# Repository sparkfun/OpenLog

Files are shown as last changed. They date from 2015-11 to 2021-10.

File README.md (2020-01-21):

SparkFun OpenLog
================

<table class="table table-hover table-striped table-bordered">
  <tr align="center">
   <td><a href="https://www.sparkfun.com/products/13712">SparkFun OpenLog</a></td>
   <td><a href="https://www.sparkfun.com/products/13955">SparkFun OpenLog with Headers</a></td>
  </tr>
  <tr align="center">
    <td><i>SparkFun OpenLog (<a href="https://www.sparkfun.com/products/13712">DEV-13712</a>)</i></td>
    <td><i>SparkFun OpenLog with Headers (<a href="https://www.sparkfun.com/products/13955">DEV-13955</a>)</i></td>
  </tr>
</table>

OpenLog is an open source data logger that works over a simple serial connection and supports microSD cards up to 64GB. 

Repository Contents
-------------------
* **/Documentation** - Data sheets, additional product information
* **/Firmware** - Example sketches for the OpenLog, and for an Arduino connected to the OpenLog.
* **/Hardware** - Hardware design files for the OpenLog PCB. These files were designed in Eagle CAD.
* **/Libraries** - Libraries for use with the OpenLog.
* **/Production** - Production panel files (.brd)

Documentation
--------------
* **[Hookup Guide](https://learn.sparkfun.com/tutorials/openlog-hookup-guide)** - Basic hookup guide for the OpenLog.
* **[SparkFun Fritzing repo](https://github.com/sparkfun/Fritzing_Parts)** - Fritzing diagrams for SparkFun products.
* **[SparkFun 3D Model repo](https://github.com/sparkfun/3D_Models)** - 3D models of SparkFun products. 
* **[SparkFun Graphical Datasheets](https://github.com/sparkfun/Graphical_Datasheets)** -Graphical Datasheets for various SparkFun products.

License Information
-------------------

This product is _**open source**_! 

Please review the LICENSE.md file for license information. 

If you have any questions or concerns on licensing, please contact techsupport@sparkfun.com.

Distributed as-is; no warranty is given.

- Your friends at SparkFun.

_SDFatLib-beta and SerialPort are written by Bill Greiman, and released under GPLv3._

Version History
---------------

For a full view of changes please see the [changelog](https://github.com/sparkfun/OpenLog/blob/master/CHANGELOG.md). 

OpenLog v4 is refactored with better RAM utilization for better performance at higher record speeds (115200/57600).

OpenLog v3 is stable, supports FAT32 cards up to 64GB and supports higher record speeds (115200/57600).

OpenLog v2 is a bit buggy but supports FAT32 and SD cards up to 16GB.  

OpenLog v1 is stable but only supports FAT16 and up to 2GB.  

* **v1.0**  Buggy initial release
* **v1.1**  Small changes to system settings and EEPROM storage.
* **v1.2**  Added wild card to listing and remove commands. Added read file command.
* **v1.3**  Added auto buffer record if unit sits idle for more than 5 seconds.
* **v1.4**  Increase buffer size to 900 bytes. Pinning down URU errors.
* **v1.5**  Lowered power consumption to ~2mA avg. Added 4800 and 19200 baud rates.
* **v1.51** Added configurable escape character, and escape character amount.
* **v1.6**  Added ability to configure via config.txt file.
* **v2.0**  Massive overhaul. Ported to sdfatlib. Now supports FAT16/FAT32/SD/SDHC.
* **v2.1**  Power save not working. Fixed issue 35. Dropping characters at 57600bps.
* **v2.11** Tested with 16GB microSD. Fixed issues 30 & 34. Re-enable power save.
* **v2.2**  Modified append_file() to use a single buffer. Increased HardwareSerial.cpp buffer to 512 bytes.
* **v2.21** ringp fork brought in. rm dir, cd .., and wildcards now work!
* **v2.3**  Migrated to v10.10.10 of sdfatlib. Moved to inline RX interrupt and buffer.
* **v2.4**  Merged ringp updates. Commands cd, rm, ls work again!
* **v2.41** Power loss bug fixed. Adding support for 38400bps for testing with SparkFum 9DOF IMU logging. 
* **v2.5**  Added software reset command. Modified the read command to print extended ASCII characters.
* **v2.51** Changed command prompt control to ignore \n for easier control from microcontroller.
* **v3.0**  Migration to Arduino v1.0 and better recording speed at 115200bps and 57600bps.
* **v3.1**  Better handling of recording during power loss.
* **v3.2**  Freed up RAM for larger RX ring buffer. Added support for wildcards and ability to ignore emergency override.
* **v3.3**  Added ability to ignore escape character checking and corrected incremental log naming.
* **v4.0**  Re-worked to be compatible with Arduino v1.6.x. Freed RAM to increase RX buffer size.

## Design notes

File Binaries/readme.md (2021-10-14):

Programming OpenLog via Serial
===========================================================

The SparkFun OpenLog can be updated using a USB to serial adapter and 5 jumper wires. Run batch_program.bat with a given COM port and HEX file.

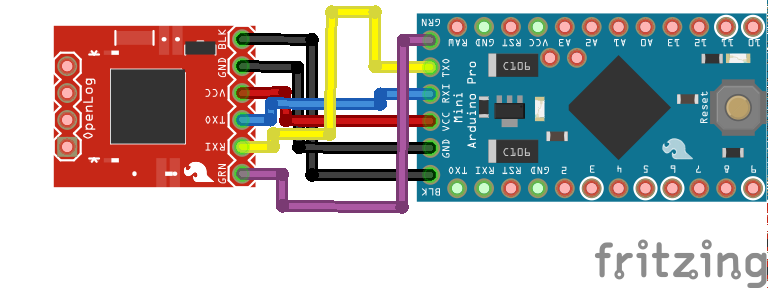
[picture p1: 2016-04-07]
Documentation/OpenLogProMini.png

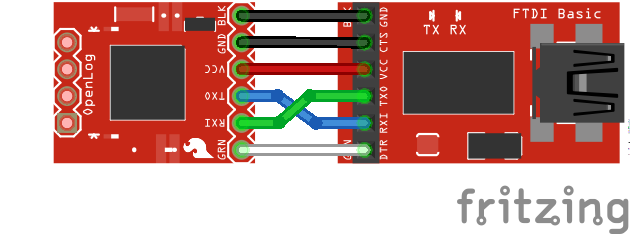
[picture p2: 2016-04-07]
Documentation/OpenLogFTDI.png

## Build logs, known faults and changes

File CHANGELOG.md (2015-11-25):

#Change Log
All notable changes to this project will be documented in this file. We'll also give shout outs to folks who help fix bugs and generally make OpenLog a better experience.
 
## [4.0] - November 23 2015 

27,046 bytes compiled

Welcome to version 4! Now compiles under Arduino v1.6.x! Thanks @owenduffy for getting OpenLog ported to the new SdFatLib.

Worked on issue #168. Fixed issue #178. Thanks @jremington! Now works with Bill's latest [SD lib](https://github.com/greiman/SdFat-beta).

[Added] Escape character sequences are now removed from logs. If you hit ctrl+z three times you'll drop to the command shell and the three escape characters will not be recorded to the log.

[Removed] The pwd command has been removed from the command shell. This *shouldn't* effect anyone but you should know.

[Removed] The sync command has been removed from the command shell. This *shouldn't* effect anyone but you should know.

Fixed a bad bug found by @ystark. Thank you! New file name array is now correctly defined as static.

Fixed the LEDs so they now blink correctly when doing an emergency reset.

In order to get the maximum out of SerialPort lib you'll need to edit SerialPort.h: 

* Set BUFFERED_TX to 0
* Set ENABLE_RX_ERROR_CHECKING to 0

## [3.3] August 2014

28,350 bytes compiled

Using the latest SdFat lib from Bill: https://code.google.com/p/sdfatlib/downloads/list
Using Arduino v1.5.4

Fixed issue #160: https://github.com/sparkfun/OpenLog/issues/160
Logs now increment continously regardless of what file may be on the card. Adds 6 bytes.

Added feature/issue #166: If escape characters is set to zero, it ignores all escape characters. Adds 200 bytes.

Fixed issue 164 - Reducing RX buffer size to allow for correct baud rate changes.
SerialPort<0, 780, 0> NewSerial; //Fails
SerialPort<0, 750, 0> NewSerial; //Works

Fixed issue #163 - using dlkeng's fix to get baud rate to work at 300 baud. Adds 80 bytes.

Increased escape character limits to 0 and 254. If set to zero, it will not check for escape characters.

## [3.2] April 8 2013

28,640 bytes compiled (yay! saved a bunch by removing the text-based menu system)

Re-wrote baud rate system to support anything from 300bps to 1,000,000bps

Added support for newlines when using the 'write' command.
Should fix issue #149.

Fixed issue #134: When removing files and there is a directory, all wildcard files are now removed correctly.
Fixed issue #135: ls with wildcard works again. Thank you @dlkeng!

## [3.14]

29,354 bytes compiled

Added support for 1200bps. Issue #139.

## [3.13]

29,172 bytes compiled

Changed the string compares from strings in RAM (strcmp) to strings located in flash memory (strcmp_P).

We used to use this type of compare: else if(strcmp_P(command_arg, PSTR("md")) == 0)

I'm not sure how or why I got away from it, but bringing it back frees up a lot of RAM. I bet I got rid of PSTRs in an attempt to reduce code size when I should have been more worried about RAM running out. RAM is currently at 645 after 2 and 562 once we've begun append_file. Also figured out there is sprintf_P built just for PSTRs. Neat! RAM is currently at 779 after 2 and 696 once we've begun append_file. Removal of strncmp(). I believe we used it to reduce flash footprint. Once migrated to PSTR, it makes it worse.

## [3.12]

29,282 bytes compiled

Using freeMemory() function from JeeLabs. Seems to be working well.

Echo on/off is working again with a reduction of the buffer from 600 to 500. Code size is up a bit to 29,282. We have free RAM of about 527 after "2" and 444 once we've begun append_file.

## [3.11] March 26 2012

Added freeMemory support for RAM testing.

This was taken from: http://arduino.cc/playground/Code/AvailableMemory

## [3.1] March 23 2012

Fixed bug where entire log data is lost when power is lost.

Added fix from issue #76. Added support for verbose and echo settings recorded to the config file and EEPROM. Bugs #101 and #102 fixed with the help of @pwjansen and @wilafau - thank you!!

Because of the new code to the cycle sensitive append_log loop, 115200bps is not as rock solid as I'd like. I plan to correct this in the Light version.

Added a maxLoop variable calculation to figure out how many bytes to receive before we do a forced file.sync.

## [3.0] March 14 2012

28,354 bytes compiled

Re-write of core functions. Support under Arduino v1.0. Now supports full speed 57600 and 115200bps! Lower standby power.

Be sure to check out https://github.com/nseidle/OpenLog/issues for issues that have been resolved up to this version.

Update to new beta version of SerialPort lib from Bill Greiman. Update to Arduino v1.0. With Bill's library, we don't need to hack the HardwareSerial.cpp.

Re-wrote the append function. This function is the most important function and has the most affect on record accuracy. We are now able to record at 57600 and 115200bps at full blast! The performance is vastly improved.

To compile v3.0 you will need Arduino v1.0 and Bill's beta library: http://beta-lib.googlecode.com/files/SerialLoggerBeta20120108.zip Unzip 'SerialPortBeta20120106.zip' and 'SdFatBeta20120108.zip' to the libraries directory and close and restart Arduino.

Small stuff:

* Redirected all static strings to point to the new way in Arduino 1.0: Serial.print(F("asdf")); instead of PgmPrint
* Figured out lower standby power from the low-power tutorial: http://www.sparkfun.com/tutorials/309
* Corrected #define TRUE to built-in supported 'true'
* Re-arranged some functions
* Migrating to Uno bootloader to get an additional 1500 bytes of program space
* Replumbed everything to get away from hardware UART
* Reduced # of sub directory support from 15 levels to 2 to allow for more RAM
* Wildcard remove is supported in v3.1
* Wildcard is supported in v3.2
* [Remove] efcount and efinfo is not yet supported in v3.0

Testing at 115200. First test with clean/empty card. The second test is with 193MB across 172 files on the microSD card.

* 1GB: 333075/333075, 333075/333075
* 8GB: 333075/333075, 333075/333075
* 16GB: 333075/333075, 333075/333075

The card with tons of files may have problems. Whenever possible, use a clean, empty, freshly formatted card.

Testing at 57600. First test with clean/empty card. The second test is with 193MB across 172 files on the microSD card.

* 1GB: 111075/111075, 111075/111075
* 8GB: 111075/111075, 111075/111075
* 16GB: 111075/111075, 111075/111075

The card with tons of files may have problems. Whenever possible, use a clean, empty, freshly formatted card.

## [2.51] June 1 2011

Improved command prompt parsing (now ignores '\n')
 
We now ignore the \n character when parsing characters from the command prompt. This makes it easier to create code on a microcontroller that correctly controls OpenLog. Previously, println or sprintf commands were adding a \n to the end of the string that would confuse OpenLog. One way around this if you have previous versions is this 

    sprintf(buff, "new blah.txt\r");
    Serial.print(buff); //No println, use \r in string instead

Also - added a CommandTest sketch to demonstrate how you can control OpenLog from a microcontroller / automate the command prompt

## [2.5] February 2 2011

28,782 bytes compiled

Improved 'read' command. Added 'reset' command.

Modified the read command so that we can print extended ASCII characters. The function was also failing to print any value over 127 (limited to signed 8 bits - boo). Thank you @wilafau! You proposed excellent, easy fixes.

Added raw command during print operation. This allows for non-visible and extended ASCII characters to be printed correctly, if need be.
 
Issuing 'reset' command causes OpenLog to reset and re-read the config file. This is important if you want to change the config file then restart.
 
Removed some of the extraneous prints from the help menu to save on space.

## [2.41]

29,124 bytes compiled (yikes)

Power loss bug fixed. Adding support for 38400bps for testing with SparkFum 9DOF IMU logging. 

Found a bug in the append_file routine. If the unit is actively logging, file.writes are flying by quickly. But if OpenLog loses power, none of the data is recorded because there is no file.sync. Data would only get recorded if the unit went idle or if user entered escape command. This has since been fixed with two file.sync() commands.

## [2.4] November 17 2010

29,028 bytes compiled (yikes)

Merged @ringp updates. Commands cd, rm, ls work again! New "rm -rf" command to remove directory and its files. Thanks ringp! Great work.
 
Remember - we had to completely butcher HardwareSerial.cpp so a normal Arduino installation will not work. 

C:\arduino-xxxx\hardware\arduino\cores\arduino\HardwareSerial.cpp

I've added the modified HardwareSerial.cpp to the repo.
 
Testing at 57600

* 1GB: 110490/111000, 110490/111000
* 8GB: 111000/111000, 111000/111000, 111000/111000
* 16GB: 83890/111000, 84908/111000

The 16GB card with tons of files continue to have problems but the other cards (FAT and FAT32) are acceptable. Whenever possible, use a clean, empty, freshly formatted card.
 
To remove a directory and all its files:

    rm -rf mydirectory
 
Windows 7 stores the Arduino hex file in an awful place. Something like:

    C:\Users\Main\AppData\Local\Temp\build3390340147786739225.tmp\OpenLog_v2.cpp.hex
 
Added HardwareSerial.cpp and a readme to the main trunk.
Added OpenLog_v2.cpp.hex to the main trunk.

## [2.3]

27,334 bytes compiled

Migrated to v10.10.10 of sdfatlib. Moved to inline RX interrupt and buffer. Improved the ability to receive a constant stream at 57600bps.
 
Remember - we had to completely butcher HardwareSerial.cpp so a normal Arduino installation will not work. 
C:\arduino-xxxx\hardware\arduino\cores\arduino\HardwareSerial.cpp
 
I removed the receive interupt handler from HardwareSerial.cpp so that we can deal directly with USART_RX_vect in the main code. This allows us to return to the way OpenLog used to operate - by having one buffer split in half. Once one half fills, it is recorded to SD while the other half fills up. This dramatically decreases the time spent in function calls and SD recording, which leads to many fewer characters dropped.

The change log at the top of the main code got so large I've moved it to a version controlled "Changes.txt" file.

By making all these changes, I have broken many things. Ringp - I could use your help here. I apologize for stomping on so much of your work. I was not good enough to figure out how to re-link from the old function calls to the new sdfatlib setup.
 
Backspace is broken - ringp, I saw this fix in one of your commits, but looking at the code, I don't see how it is supposed to work. Either way, we still get 0x08 when trying to backspace.
 
New sdfatlib doesn't have SdFat.cpp so fileInfo doesn't work. These function calls are marked with //Error
 
I have chosen to dis-allow deprecated functions: #define ALLOW_DEPRECATED_FUNCTIONS 0
This forced some trivial changes to the SD write and new file creation function calls. I believe we've successfully migrated to the new version of sdfatlib.
 
In the command_shell / read_line function : It may be better to pull directly from the UART buffer and use the RX interrupt. For now, we brute force it.
 
Because of all these changes, I need to re-test power consumption. For now, I'm confident it's low enough.
 
Testing with 512 buffer array size

* 1GB @ 57600 - dropped very little out of 3 tests
* 1GB @ 115200 - dropped very little out of 2 tests
* 8GB @ 57600 - Formatted using the sd formater (32k byte allocation size). Dropped nothing.
* 8GB @ 115200 - dropped very little, dropped none
* 16GB w/ Lots of files @ 57600 - Drops the first part of the file because of start up delay?
* 16GB w/ Lots of files @ 115200
 
1024 array size (and 800) does not run
 
Testing with 700 buffer array size

* 1GB @ 57600 - 110300 out of 111000 bytes, 110300/111000,
* 1GB @ 115200 - 111000/111000!, 109600/111000
* 8GB @ 57600 - 109000/111000, 111000/111000!,
* 8GB @ 115200 - 111000/111000!, 111000/111000!,
* 16GB w/ Lots of files @ 57600 - 85120/111000, 85120/111000
* 16GB w/ Lots of files @ 115200 - 56420 (but once it got going, log looks good). 56420.
 
I am seeing long delays on cards with lots of files. In the above tests, the 16GB test card is a good example. It has 2GB worth of random files in a sub directory.

After OpenLog boots, goes to '12<'. After I send ~500 characters OpenLog freezes for a couple seconds, then returns to normal, very fast, operation. During that down time, I believe sdfatlib is searching for an open cluster. The odd thing is that after the cluster is established (after the initial down time) OpenLog performs excellently. I am hoping to create a faux file or pre-write and save to the file or some how get this allocation done before we report the '12<' indicating we are ready. That way, if a card does fill up, as long as the host system is checking for '<', it doesn't matter how long it takes sdfatlib to find the next free cluster.
 
You can see that we drop 700 bytes at a time. That's a bit odd - I'd expect to drop half or 350 at a time. What happens if we shrink the array size to say 256? To be expected, this is bad - way more instances of dropped characters.
 
Added blink for each test to the OpenLog_Test sketch so we can see as the test progresses.
 
http://www.sdcard.org/consumers/formatter/ is the site for SD card formatting. It looks like this program takes a guess at the correct block size. This could help a lot in the future.

## [2.21]

28,440 bytes compiled

ringp fork brought in. Wildcard remove and list commands now work. Remove directory now works! Change directory up/down the tree works again.
 
ringp brought back many great commands! Thanks ringp!

* rm LOG*.* works
* ls *.TXT works
* cd .. works again
* ls now correctly shows directories first and files following the directories.
 
To remove a directory, you have to navigate into that directory. For example:

    >cd TEMP (you are now in TEMP directory)
    >rm -f TEMP (you are now removing TEMP, and you will be pushed back down one level of the tree)
    >ls (shows files and directories where TEMP directory used to be, but TEMP directory should be gone)
 
ringp added new commands:

* efcount: gives the number of files in the current directory. Example: "efcount" returns "count|3". There are 3 files in the current directory.
* efinfo <spot>: gives info about the file in <spot>. Example: "efinfo 2" reports "LOG00588.TXT|45". File number 2 is named LOG00588.TXT and is 45 bytes in size.
* verbose <"on"|"off">: sets whether command errors are verbose (long winded) or just the "!" character. Example: "verbose off" sets verbose off. Then if a command like "blah" is received, then only "!>" is seen from the command line interface. This makes it easier for embedded systems to recognize there was an error. This setting is not recorded to EEPROM.

## [2.2]

Modified append_file() to use a single buffer. Increased HardwareSerial.cpp buffer to 512 bytes.
 
More testing at 57600. Record times look to be 2, 5, and zero milliseconds when doing a record. This means that the split buffer doesn't really make a difference? There are some records that take 150ms, 14ms, etc. At 57600bps, that's 7200 bytes/s, 138us per byte. With a 150ms pause, that's 1,086 bytes that need to be buffered while we wait... Grrr. Too many.
 
I re-wrote the append_file function to use only one buffer. This allows us to more quickly pull data from the hardware serial buffer. Hardware serial buffer has to be increased manually to 512. This file (hardwareserial.cpp) is stored in the Arduino directory. With testing, it seems like recording is working more solidly at 57600bps. But now I'm seeing glitches at 19200bps so more testing is required before we make this the official OpenLog release.
 
Moved input_buffer into within the append function. Attempting to shave bytes of RAM.

## [2.11]

26,136 bytes compiled out of 30,720

Tested with 16GB microSD. Fixed some general bugs. Lowered power consumption.
 
Fixed issue #30. I added printing a period ('.') for non-visible ASCII characters during a 'read' command. This cleans up the output a bit. HEX printing is still available. 
 
Fixed issue #34. When issuing a long command such as "read log00056.txt 100 200 2" (read from spot 100 to spot 200 and print in HEX), the command shell would die at 24 spots. I increased both the general_buffer and 'buffer' in the command shell from 24 to 30. The limit is now 30 characters, so "read log00056.txt 100 20000 2" is allowed.
 
Works with a 16GB microSD card! High volume test: loaded 16GB card with 5GB of data. Basic serial tests work. When running at 57600, there is an odd delay. I think it has to do with the file system doing an initial scan for an available cluster. Takes 2-3 seconds before OpenLog returns to normal. This can cause significant data loss.
 
Fixing power management in v2. Power down after no characters for 3 seconds now works. Unit drops to 2.35mA in sleep. 7.88mA in sitting  RX mode (awake but not receiving anything). There is still a weird bug where the unit comes on at 30mA. After sleep, it comes back at the correct 7-8mA. Is something not getting shut off?

## [2.1]

26,058 bytes out of 30,720

Power save not working. Fixed issue #35. Dropping characters at 57600bps. 

Fixed a bug found by Salient issue #35. User settings where declared at chars which allowed them to be signed. If a user went from old firmware, to v2, the safety checks would fail because the settings would be read at -1 instead of 255. Declaring user settings as byte fixed issue.
 
Added "a) Clear user settings" to set menu. This allows us to completely wipe an OpenLog (user settings and config file) to see how it will respond to future firmware changes.
 
Improved the file 'size' command.
 
Sequential logging is tested and works.
 
Receive testing: Using the Test_Sketch found on Github, I am testing the receive reliability at different UART speeds.

We need to test a lot of received data. At 57600, 115200, and both from an Arduino (lots of time in between characters becuase of software overhead) and from a raw serial port (almost no time in between characters). I am hoping to make sdfatlib hiccup at 115200, full speed, across a 1MB file. If I can make it fail, then we can start to increase the buffer size and look at how much RAM sdfatlib has left open for the buffer.
 
* 9600bps from Arduino works fine
* 57600bps from Arduino drops characters
* 115200 from Arduino drops characters

It seems that sdfatlib takes longer to write to the SD card than the original file system from Robert Reigel. I'm thinking perhaps we should create a version of OpenLog firmware that is just sequantial logging, no fancy system menus... It might open up some RAM.
 
If only we could get control of the UART from Arduino's clutches, we could probably handle the ring buffer much better. Not sure how to handle UART interrupts without tearing out HardwareSerial.cpp.
 
Added README to the Test sketch. Added 115200bps to test sketch.

## [2.0]

25,986 bytes out of 30,720

Welcome to version 2! We've moved from Roland Riegel's FAT library to Bill Greiman's sdfatlib. OpenLog now works with SD cards up to 16GB (that is the current largest microSD card we can get our hands on). OpenLog automatically detects and works with FAT16/FAT32 file systems. It also automatically works with normal SD cards as well as SDHC cards.
 
Almost all the previous commands have been ported from v1 to v2. The current commands that do not work:

* cd.. - does not work. You can change to an upper directory, but you cannot navigate back down the tree.
* cat - this command was depricated. HEX printing is now done with the 'read' command. We've added a 5th argument to select between ASCII and HEX printing.
* Wild cards do not yet work. So rm and ls do not have wild cards enabled - yet. Help us out!
 
Porting OpenLog to work directly under Arduino to work with sdfatlib (http://code.google.com/p/sdfatlib/) by Bill Greiman.
 
sdfatlib intrinsically supports FAT16, FAT32 as well as SD and HCSD cards. In a word, it's amazing.
 
Needs to be done:

* (Done) Get config file reading/loading working
* Document config file in wiki: if no config file is found, current system settings are used. If config is found, system switches to settings found in file. If system settings are changed, then config file is changed and system uses new settings immediately.
* (Done) We don't want to constantly record a new config file on each power on. Only record when there is a change.
* Get cd.. working
* Seperate OpenLog_v2 into multiple files
* Re-test too many log files created in the newlog setting - 65535. Potentially create thousands of files and see how sdfatlib handles it.
* (Done) Test sequential logging.
* Get wild card support working for ls and rm
* Get backspace working
* Test rm with directories, and directory wildcards? Maybe not.
* Get power save working
* Test compile on a computer that doesn't have WinAVR
 
Test commands:

* new - works, also in sub dirs
* append - works, also in sub dirs
* rm - works, but does not yet support wild cards.
* md - works, also in sub dirs
* cd - you can change up to a sub-directory, but you cannot navigate back down the tree. The current work around is to type 'init'. This will re-init the card and set the directory back to root.
* ls - works pretty well but does not yet support wild cards. Shows directories, files, and file sizes. Would be cool if it listed dirs first.
* read - works well. Tested 0, 1, 2, 3, 4, and 5 arguments (included and left off). Fails gracefully. Now prints in HEX as well!
* size - works well
* disk - works well, prints more information than ever before!
* init - works well
* sync - works, but not really tested
* cat - I've decided to drop this command. You can now print in hex using the read command and using a 5th argument as '1' for ASCII (default) and '2' for HEX.
* set - works well
* baud - works well

## [1.61]

Small PCB change. Fixed version # in help menu.
 
Fixed the firmware version in the help menu to v1.61.
 
Updated Eagle files to Eagle v5.9. Fixed weird airwire. Changed D1 LED from Green to Blue. Will only affect new production after 4-28-10.
 
Closed some tickets and wrote some more example Arduino code: http://forum.sparkfun.com/viewtopic.php?t=21438

## [1.6]

Adding config file.
 
What happens if I reset the system by pulling RX low, but the config file has corrupt values in it?
 
If config file has corrupt values in it, system will default to known values 9600/ctrl+z/3/newlog
 
If config file is empty, system resets to known values
 
After some massive testing, and lots of code to check for illegal states, it looks to be pretty stable. The only problem is that we're running out of RAM. The buffer had to be decreased from 900 bytes to 700 bytes to facilitate all the config file checking. Testing at 57600bps, unit runs very well over 40kb test file on straight RS232 connection. That's pretty good. Testing at 115200 on straight  connection, unit will drop a buffer every once and a while. Not great, but not much we can do if the SD card times out for ~150ms while it's writing. 8 bits to the byte plus a start/stop bit = 10 bits per byte
 
* 9600bps = 960 bytes per second. Buffer will last for 729ms
* 57600bps = 5760 bytes per second. Buffer will last for 121ms
* 115200bps = 11520 bytes per second. Buffer will last for 60.7ms
 
So if the SD card pauses for more than 60ms, 115200 will have lost data, sometimes. All other baud rates should be covered for the most part.
 	
SD cards with larges amounts of data will have increased pause rates. Always use a clean card where possible.

## [1.51]

check_emergency_reset, default break character is ctrl+z 3 times, example Arduino sketch
 
Added function from @mungewell - check_emergency_reset. This has improved testing of the RX pin. There was potential to get a false baud reset. There is still a chance but it's now much less likely.
 
If OpenLog is attached to a Arduino, during bootloading of the Arduino, ctrl+z will most likely be sent to the Arduino from the computer. This character will cause OpenLog to drop to command mode - probably not what we want. So I added user selectable character (ctrl+x or '$' for example) and I added user selectable number of escape characters to look for in a row (example is 1 or 2 or 3, '$$$' is a common escape sequence). The default is now ctrl+z sent 3 times in a row.
 
Added an example Arduino sketch (from @ScottH) to GitHub so that people can easily see how to send characters to OpenLog. Not much to it, but it does allow us to test large amounts of text thrown at OpenLog at 57600bps.
 
## [1.5]

Added 4800bps and 19200bps support
 
Added power saving features. Current consumption at 5V is now:

In default append mode: 

* 6.6/5.5mA while receiving characters (LED On/Off)
* 2.1mA during idle

In command mode: 

* 3.2/2.1mA (LED On/Off)
 
So if you're actively throwing characters at the logger, it will be ~6mA. If you send the logger characters then delay 5-10 seconds, current will be ~2.5mA. (Unit records the characters in the buffer and goes into idle more if no characters are received after 5 seconds)
 
These power savings required some significant changes to uart.c / uart_getc()

## [1.4]

Added exit options to the two menus (set and baud)
Also added display of current settin to two menus (Ex: "Baud currently: 57600bps")
 
Added '!' infront of 'error opening'. This pops up if there is an error while trying to append to a freshly created new log (ex: LOG00548.txt is created, then errors out because it cannot append). '!' was added so that user can parse against it.
 
Replicated logging errors at 57600 using 5V Arduino. Unit would systematically glitch during logging of 111054 bytes.
 
Increasing buffer to 1000 characters caused URU error. URU: Unit Resets Unexpectedly
 
To recreate URU error. Type "append ". Include the space. If you get "!error opening", then things are fine. If you get "!error opening#" where # is a weird character, then type 'ls' and the unit will unexpectedly reset (URU error). I believe this is attributed to a memory overrun somewhere in the FAT system.
 
Changed buffer size to 900 and declared the character buffer as volatile

    #define BUFF_LEN 900
    volatile char input_buffer[BUFF_LEN];
 
This increase to the buffer allows for clean logging of 444055 bytes with no URU errors.
 
Experimenting with Scott's SD cards (customer gave cards on loan for recreating logging errors):

* Card with single ~740mb file produces errors when trying to open/append to new log. 
* Card with less stuff on it logs full 444055 bytes correctly.

## [1.3]

Added sd_raw_sync() inside append_file. I believe this was why tz1's addition of the timeout buffer update feature was not working. Auto buffer update now working. So if you don't send anything to OpenLog for 5 seconds, the buffer will automatically record/update.
 
Need to create 'Testing' page to outline the battery of tests we need to throw at any OpenLog after a firmware submission and update is complete.
 
Testing create 40,000 logs
 
Record at full speed: Run at full 115200, load lotsoftext.txt and verify no characters are dropped.
 
Detect too many logs: Create new log at 65533 (do this by editing 'zero' function to set EEPROM to 0xFF and oxFD) and power cycle. Verify unit starts new log. Power cycle and verify unit errors out and drops to command prompt.
 
Record buffer after timeout: Create new log. Type 20 characters and wait 5 seconds. Unit should auto-record buffer. Power down unit. Power up unit and verify LOG has 20 characters recorded.	

## [1.2]

@ringp added:

* Adding support for splitting command line parameters into arguments
* Adding support for reading files sequencially
** read <filename> <start> <length>
* New log now for sequencial log functions supports 0-65535 files
* Adding support for wildcard listing or deletion of files
** ls <wildcard search>
** rm <wildcard delete>
 
Really great additions. Thanks ringp!
 
Nate added error testing within newlog(). Checks to see if we have 65534 logs. If so, error out to command prompt with "!Too many logs:1"
 
## [1.1]

Adding better defines for EEPROM settings
Adding new log and sequential log functions.
 
Code is acting very weird with what looks to be stack crashes. I can get around this by turning the optimizer off ('0'). Found an error : EEPROM functions fail when optimizer is set to '0' or '1'. sd-reader_config.h contains flag for USE_DYNAMIC_MEMORY
 
Looks like tweaking the optimization higher causes the asm("nop"); to fail inside the append_file routine. Changing this to delay_us(1); works.
 
I have a sneaking suspicion that I was having buffer overrun problems when defining the input_buffer at 1024 bytes. The ATmega328 should have enough RAM (2K) but weird reset errors were occuring. With the buffer at 512bytes, append_file runs just fine and is able to log at 115200 at a constant data rate.
 
Added file called 'lots-o-text.txt' to version control. This text contains easy to scan text to be used for full data rate checking and testing.
 
## [1.0] December 3 2009

Original version written in C.

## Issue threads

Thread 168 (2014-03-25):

problem command Write file offset

marclabouille, 2014-03-25:
Hi, i have tested the V3.3 for command write file offset, i want modify data on text, but when i enter the new data, the two Carriage return (exit write mode) killed the next data and i have a new line on my text
The V3.13 don't have this problem, i don't see the problem on code.

nseidle, 2015-08-20:
I'm just scratching the surface of this issue. There are multiple things going on. Let's start with some test cases:

    new test.txt
    append test.txt
    1234567890<CR>^Z^Z^Z           //(should exit out)
    read test.txt 0 100 2                    //(show file from 0, 100 chars, in hex)
    output: 31 32 33 ... 39 30 D 1A 1A 1A          //0x0D is CR, 0x1A is ^Z

This output seems to be correct. I am using teraterm v4.87.

"The CR character 0x0D has been replaced with a LF 0x0A and then the 3 ^Z characters are written to the file."

This is perhaps a limit of your terminal program? I cannot replicate this problem.

"It's even worse when I use the write command to insert characters ABC at position 3."

Forgive me but there is too much going on in this issue to keep it straight. Please start another issue with specific test cases that I can test from a terminal. I really like your ideas about ways to avoid recording escape characters but there are some technical challenges to figure out.

nseidle, 2015-08-20:
I believe most of the issues revolve around the write command. If we return to the original issue:

    rm test.txt
    new test.txt
    write test.txt
    123456789<enter><enter>
    read test.txt 0 100 2
    31 32 33 34 35 ... 39 A D       //A is NL, D is CR

It is odd that Openlog is recording a Newline and a carriage return

    write test.txt 1
    ABC<enter><enter>
    read test.txt 0 100 2
    31 41 42 43 A D 37 38 39 A D

This looks sort of correct. The NL and CR are being inserted the same as the previous write command. I believe the original poster wants the write command to not insert the 0x0A and 0x0D into the stream. This can be done but it will be tricky to not write two CRs but *to* write one CR followed by other text.

jcdammeyer, 2015-08-20:
It’s been a few months since I looked at this.  I did a work-around.  I’ve almost used up the first 50 units.  I made 100 carrier boards for them so I’ll get getting another 50 or so.

Here’s the thing.  In DOS and before that in CP/M-80,  a ^Z marked the end of a text file.  If you opened the file and did a seek to the end to append to the file the next written character was written over the ^Z and the new text was terminated with the ^Z when the file was closed.
You could have three ^Z characters there.  It doesn’t matter.

So a file might look like:
Hello World!<CR><LF>
It’s a nice day outside. <CR><LF>
Do you want to Play? <CR><LF>^Z^Z^Z

Now if I want to append to the file the Line “No it’s cold outside.” The file would look like this.

Hello World!<CR><LF>
It’s a nice day outside. <CR><LF>
Do you want to Play? <CR><LF>
No it’s cold outside. <CR><LF>^Z^Z^Z

IIRC, My testing showed the file looked like this.
Hello World!<CR><LF>
It’s a nice day outside. <CR><LF>
Do you want to Play? <CR><LF>^Z^Z^Z
No it’s cold outside. <CR><LF>^Z^Z^Z

So instead I’d have to seek to the EOF minus 3 characters to get rid of the ^Z..  But then I’m not appending and the writing doesn’t terminate with the ^Z.  I think that’s what was happening.

But as I said, that’s a long time ago and the code for it is currently locked down and since it’s for a Homeland Security client I’m not allowed to just change it without the client doing extensive testing.

Thanks
John

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

jcdammeyer, 2015-08-20:
Also to test what is written it's best to use write or append the data and close the file.  Then pull the MicroSD card ands mount it in your PC and load it with an editor that can look at the binary values.  That's when I discovered there were problems.  Writing and reading to the SD card in my application is done with a Delphi application and UART.  Not a terminal emulation program from the desktop.

jcdammeyer, 2015-08-20:
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I just checked the application code.
The solution was to break the file into smaller pieces.  I have one file per minute. So I'd rm the old one.  Append the new one and close it when done.  That solved the multiple ^Z issue since I never append to an existing file.  I have an #ifdef in the code for APPEND verses WRITE and APPEND is enabled.
Simple solution for problem code.  The attached photo shows the board it's mounted on.  At the far back (not installed) is a WizNet Ethernet module.  On the bottom side of the board is a coin cell and RTC.  I have one version that runs ACN-E1.31 DMX-512A messaging on Ethernet and the plan was to also put show software on the SD card.
This board was done in a hurry because the client forgot to ask for it.  Then suddenly there was a deadline that had to be met.
A replacement

nseidle, 2015-08-20:
So very cool! Thanks for posting the photo. Sounds like you've got some nice work arounds in place.

To be clear, I'm not using an emulator - I am using a serial terminal to send commands directly to OpenLog. Teraterm is just a free/easy to use one that allows distinct CR/NL control.

The ^Z command is intended to drop the user to the command prompt, not to designate the end of a file (sorry for the confusion). The break command (^Z) on OpenLog is configurable to any ASCII character and was picked arbitrarily to be ^Z by me as the default.

The write command relies on the user entering it from the command shell. This means it uses the read_line function which itself relies on searching for \r to signify the end of user input.

    if(dataLen < (sizeof(buffer) - 1)) tempFile.write("\n\r", 2); //If we didn't fill up the buffer then user must have sent NL. Append new line and return

We could change the two bytes that are written to the file when using write command but I am worried about breaking compatibility with current users.

I'm going to close this issue but open a new one that discusses methods to avoid recording the three escape characters from the log. I that feature would be more valuable than modifying how the write method works.

JKPina, 2017-06-20:
Hi guys, I got #168 issue but I couldn't figure out if it was finally solved, I dived into the openlog firmware version 4, but checked that the piece of code referring to that issue was commented, so: is it a fixed issue or (even better) is a correct way in the uController code to avoid putting a <CR> in the file?

thanks in advance ;)

jcdammeyer, 2017-06-20:
I don't know if it was ever fixed.  I ordered (and received) another 50 to finish off this production run.  Because the board these plug into uses an FTDI device that is only rated 0-70C and a -40C device isn't available in the package I'm using we will need to revise the main board for the next production run.  The OpenLog crystal is also only 0-70C and we don't want to rework it with a new crystal.

That's a good enough excuse to fix some of the little issues and recreate the companion board to have a PIC32 for Ethernet, Battery backed up RTC and SD card support.  As I said above.  I worked around the issue and that interface code is stable.

JKPina, 2017-07-05:
Finally I found that the best way to avoid escape characters ( `(<SUB>)` is just a particular escape character) in the end of file is just update the firmware to v4. as @nseidle said in another thread #196 https://github.com/sparkfun/OpenLog/issues/196

cheers,

Closed 2015-08-20.

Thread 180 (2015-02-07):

Eagle Cad file error

rconry60, 2015-02-07:
From the hardware section, right clicked on the .sch and .brd files and selected "save link as...", saved the files locally.  Attempted to open (in Eagle v6.1 and v7.2) but was given the message
"Error:
line 6, column 25: This is not an EAGLE file."

I have seen closed issues where the files could be corrupted because the raw file is being downloaded but that is not the case.

nseidle, 2015-02-11:
Hello! Github is not friendly when it comes to downloading a single file or two. Right clicking and save as will not work. You have to click on the file, then raw. This should cause your browser to download the file.

If that doesn't work, goto the main page: https://github.com/sparkfun/OpenLog and click on 'Download As Zip' button on the right side. You'll get all the files that you don't need but you'll also get the true brd and sch files.

Cheers,
-Nathan

Closed 2015-02-11.

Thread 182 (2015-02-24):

No/wrong serial communication

Brodi, 2015-02-24:
We have been able to log data over the arduino with this board, however when I try communicate over serial directly (putty, teraterm) I don't get the 12> on start up.  It outputs g3 usually, so I know the com1 port is correct and I'm using 9600 8N1 BAUD. The CONFIG.TXT file is the standard 9600,26,0,1,1,0 .  Also I can't access the commands (Ctrl+z).

Thank you.

Brodi, 2015-02-24:
Just realised that my USB converter is RS-232, not TTL.  My Dumb.  I'll use a converter and report back.

Brodi, 2015-02-24:
Yup.  Problem resolved.

nseidle, 2015-02-25:
Best issue resolution ever. Thanks for coming back to post+close it!

Brodi, 2015-02-25:
Well, I hate leaving people in suspense.

Closed 2015-02-24.

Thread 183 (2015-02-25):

Multiple files creates (intermittent garbage data)

krevans, 2015-02-25:
I am trying to print to the SD card in the datalogger, and am having issues with it creating multiple files while the code is looping (and loosing some information between files). Additionally, sometimes a few lines of garbage data are output to the SD card, usually at the beginning or end of a file (can be anywhere within the files created during a single run of the code). I see this issue has been discussed previously, but I've tried to update the firmware to the latest version and this still seems to be a problem.

I am currently running at 9600 baud, printing four integer values (separated by commas) every 136 ms, with the last print including a new line (println).

Do you have any suggestions to remove this problem?

@Brodi has been helping with this issue, but we are stumped!

nseidle, 2015-02-26:
Hmm, I don't have a good solution off the top of my head. I'll need to replicate it on the bench to really dig in. Can you post some code that causes the problem?

Let's also cover the basics:

What have you got it hooked to?
What pins are hooked up?
What operating voltage?

krevans, 2015-02-28:
I think the problem may be that I am trying to send information too quickly. I am trying to send 4 integers, comma delimited, at about 200 Hz frequency. When I slow down the cycle time the problem does not seem to occur. Do you think this might be what was causing problems?

nseidle, 2015-08-20:
9600bps is 960 bytes per second. I can transmit at this speed constantly to OpenLog without it dropping a character. Depending on the extra characters you are transmitting, for example "4,6,11,5" that would be 8 characters at 200Hz. This is 1600 bytes per second, significantly faster than the 9600bps you are communicating at.

Your original comment is "four integer values (separated by commas) every 136 ms, ". This is doable "1,2,3,4," or 8 bytes at 7.35Hz. Much slower. OpenLog should be able to handle a few bytes every few hundred milliseconds.

Because of the age of this issue (sorry I'm slow!) and because it sounds like you've settled on a solution I am going to close it. If you have new information or example code please re-open.

AyrtonEstrella, 2018-08-21:
Hi @nseidle !
I know it's been 3 years since this was posted. But I recently got my own original OpenLog and I am having this same exact issue.
I'm attaching a screenshot of the text I'm trying to capture with the OpenLog.
I'm using this configuration:

- Firmware: OpenLog Minimal
- Baudrate = 9600bps

I don't know how to measure how many bytes are sent each second, but the data you can see on the screenshot takes less than 2 seconds to be printed.

Any ideas?

Thanks!
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

nseidle, 2018-08-27:
Hi! Welcome back. Let's solve this!

Let me get the basics out of the way so we don't waste time chasing the wrong thing:

* What platform are you using?
* What version of the device are you using? Is there a firmware version?
* How is the device wired to your platform?
* How is everything being powered?
* Are there any additional details that may help us help you?

Can you post a text file of that output so that we can measure the number of bytes? With the raw text of your output we can also look for things like ctrl+z popping up. I doubt that's the issue.

Once I have a copy of that output I can replicate your work by sending the same text to a unit I've got here.

AyrtonEstrella, 2018-08-27:
Hi Nathan!

  *   I’m not sure about what you mean by “Platform”. If you mean the device to which I am connecting the OpenLog, its a 3.3V PIC18F26J50.
  *   I purchased the OpenLog a couple of weeks ago. So I assume its the latest OpenLog version.
  *   The firmware version is also the latest, downloaded from github.
  *   This are the connections using jumper wires, I am testing the Minimal version of the OpenLog firmware, and modified the baudrate to 9600:
     *   PIC - OpenLog
     *   3.3V - VCC
     *   GND - GND
     *   TX - RX
  *   The target device is powered by a external 12V power supply, followed by a 4V switching regulator and then a 3.3V LDO (on the target device).
  *   More details:
     *   I am not sure if the 3.3V input voltage is enough to provide stable 3.3V to the OpenLog, because its passing through the OpenLog’s LDO.
     *   I tried modifying some options of the config file, like ignoring the escape character but I had no luck.

Thanks!
--
Ayrton Estrella Alcocer
Móvil: (999) 207 4796

On Aug 27, 2018, at 5:49 PM, Nathan Seidle <notifications@github.com<mailto:notifications@github.com>> wrote:

Hi! Welcome back. Let's solve this!

Let me get the basics out of the way so we don't waste time chasing the wrong thing:

  *   What platform are you using?
  *   What version of the device are you using? Is there a firmware version?
  *   How is the device wired to your platform?
  *   How is everything being powered?
  *   Are there any additional details that may help us help you?

Can you post a text file of that output so that we can measure the number of bytes? With the raw text of your output we can also look for things like ctrl+z popping up. I doubt that's the issue.

Once I have a copy of that output I can replicate your work by sending the same text to a unit I've got here.

—
You are receiving this because you commented.
Reply to this email directly, view it on GitHub<https://github.com/sparkfun/OpenLog/issues/183#issuecomment-416393968>, or mute the thread<https://github.com/notifications/unsubscribe-auth/AUJjovFj2YUv7Lb1O40fBLLMocPSgaLJks5uVHdngaJpZM4DlTbc>.

nseidle, 2018-11-03:
Your setup sounds fine. Out of curiosity, why did you go with the Minimal firmware version? The stock version should work fine for this application.

Can you post a file of what you're sending to the OpenLog so I can try to replicate?

My only guess at the moment is your gut feeling which is maybe the voltage running OpenLog is too low. If you can, check VCC on OpenLog when powering your system. Everything should work if VCC on OL is above about 3.0V.

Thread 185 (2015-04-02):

921600 Baudrate and continuous logging

Leek1001, 2015-04-02:
I would like to use this logger as a sniffer.
OpenLog v3.20
Connected to a serial output with a baudrate of 921600.
Pins used: +3v3, GND, TX, RX
The flashcard what is inserted is: 8GB FAT32 SDHC class 4.
The configuration file on this flashcard is:
921600,26,3,1,1,1,0
baud,escape,esc#,mode,verb,echo,ignoreRX

While booting it flashes a couple of times green and then 3 times blue, goes of and now and then 1 times blue.

But it will not work and log all kind of stange characters. Do you have any idea how I can get this to work?

nseidle, 2015-04-02:
You are using TTL serial not RS232, correct?

I've tested with 1,000,000bps from an Arduino to OpenLog and it worked well because the ATmega on OpenLog could use a divisor that was a whole integer. I'm not sure what the serial error will be at 921,000 bps, I have never tried that before.

If possible, try (or emulate) the system at a slower baud rate just to make sure your system is setup correctly.

thenickdude, 2015-04-02:
Some baud rates have quite inaccurate clocks, if I log at 230400, the error is 8% (from memory) and only garbage will be logged unless I set the data source to use 2 stop bits to aid synchronisation.

The 250000 baud rate has no error and logs flawlessly.

Leek1001, 2015-04-03:
@nseidle,
I've tested it with a FTDI cable 'TTL-232R-3v3-WE' connected to the board and than logging to the computer is going okay, but when I connect the OpenLog it will not log correctly.

nseidle, 2015-04-03:
Ok so you are interfacing with TTL level.

Off the top of my head I can't remember if Arduino sets U2Xn to 1 (I think so). So from page 173 of the ATmega328p datasheet:

UBRRn = 16,000,000 / (8*921600) - 1 = 1.17013
UBRRn = 1 (we have to round 1.17 to whole integer)
BAUD = 16,000,000 / [8*(UBRRn+1)] = 1,000,000bps

(should be) 921,600bps / (is) 1,000,000bps = 92.16 (no so great, 8% error)

Because the ATmega on OpenLog is running at 16MHz it can only really receive at 1Mbps, 666,666bps, 500,000bps, etc. I'm afraid at 921,600bps is going to have considerable receive error rates. If you can change the baud rate of the thing you are trying to log to 1Mbps it should work much better.

Closed 2015-08-20.

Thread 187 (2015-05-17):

File modification date

pgebhard, 2015-05-17:
Is it possible to adjust the modification date generated for each new file on the SD card? As it is, mine always dates files as being modified on Jan 1, 2000.

thenickdude, 2015-05-18:
The OpenLog doesn't have a real-time clock onboard so it can't keep time for you. But are you asking if there is an API for setting the timestamp on a file?

pgebhard, 2015-05-18:
Yes, an API would be sufficient. I'm planning to get a time sync over an Xbee connection first.

--
Peter

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

nseidle, 2015-05-18:
The best way I've found is to add a [GPS module](https://www.sparkfun.com/tutorials/282) (jump down to 'Main Controller Board') or an RTC and print the current date/time to the log. I then use a python script to pull out the date from the log and rename the files. Not ideal but workable.

Allowing the end user to assign a modification date is tricky. The user would send a command, then the date/time, then OpenLog would have to track it until it was power cycled. I'm afraid we don't have the room in flash to handle this amount of overhead. I'm sorry. Please re-open or comment if you think it's a must have feature.

shadimoustafa, 2019-04-15:
Hi Nathan,
I am looking for the same feature to add a timestamp to the log file name so I can distinguish between them as I am using the OpenLog as a black box device.
Thanks

Closed 2015-05-18.

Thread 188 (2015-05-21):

Won't compile with Arduino 1.6.4

ohhorob, 2015-05-21:
Per instructions on this GitHub repo, I downloaded SerialPortBeta20120106.zip and unpacked it, moved the SerialPort folder to the libraries directory.

    Build options changed, rebuilding all
    Using library SdFat in folder: /Applications/Arduino.app/Contents/Java/libraries/SdFat (legacy)
    Using library SerialPort in folder: /Applications/Arduino.app/Contents/Java/libraries/SerialPort (legacy)
    Using library EEPROM in folder: /Applications/Arduino.app/Contents/Java/hardware/arduino/avr/libraries/EEPROM

    /Applications/Arduino.app/Contents/Java/hardware/tools/avr/bin/avr-g++ -c -g -Os -w -fno-exceptions -ffunction-sections -fdata-sections -fno-threadsafe-statics -MMD -mmcu=atmega328p -DF_CPU=16000000L -DARDUINO=10604 -DARDUINO_AVR_UNO -DARDUINO_ARCH_AVR -I/Applications/Arduino.app/Contents/Java/hardware/arduino/avr/cores/arduino -I/Applications/Arduino.app/Contents/Java/hardware/arduino/avr/variants/standard -I/Applications/Arduino.app/Contents/Java/libraries/SdFat -I/Applications/Arduino.app/Contents/Java/libraries/SerialPort -I/Applications/Arduino.app/Contents/Java/hardware/arduino/avr/libraries/EEPROM /var/folders/8p/8cqdmrl10t79g_7gnkytpqn40000gq/T/build876313168200282986.tmp/OpenLog_v3.cpp -o /var/folders/8p/8cqdmrl10t79g_7gnkytpqn40000gq/T/build876313168200282986.tmp/OpenLog_v3.cpp.o
    In file included from OpenLog_v3.ino:180:0:
    /Applications/Arduino.app/Contents/Java/libraries/SerialPort/SerialPort.h: In member function 'size_t SerialPort<PortNumber, RxBufSize, TxBufSize>::write(const __FlashStringHelper*)':
    /Applications/Arduino.app/Contents/Java/libraries/SerialPort/SerialPort.h:583:11: error: 'prog_char' does not name a type
         const prog_char* p = (const prog_char*)s;
               ^
    /Applications/Arduino.app/Contents/Java/libraries/SerialPort/SerialPort.h:584:25: error: 'p' was not declared in this scope
         size_t n = strlen_P(p);
                             ^
    Error compiling.

BrentWilkins, 2015-05-21:
I don't have a way to test right now, but you might try replacing `const prog_char* p` with `const PROGMEM char * p` or `const char* p`.
prog_char is depreciated in avr-libc.  You might first try:
`#define __PROG_TYPES_COMPAT__`

nseidle, 2015-08-20:
I have run into piles of problems getting OpenLog to correctly compile under Arduino 1.6.x. At this time it only works under Arduino 1.0.x. Sorry! I'll update the wiki instructions and this issue as things change.

CerealKiller1, 2015-09-19:
Hello, sorry to bring this back up (this is my first ever issue tracker of any project...)

I am trying to compile OpenLog to install it on a custom board I made. I sourced 328P's with the arduino bootloader already installed on them. The problem is I can not compile, I get a LONG LONG list of errors. I reverted back to arduino 1.0.5 and installed the two libraries needed (SerialPort and SdFAT) yet it doesnt even come close to working. I have also tried sellecting differnt board types and tried both the regular and the lite versions.

I will copy/paste the list of error messages below. I hope my intended use is ok, it complies with the CC SA v3 license and is an open source project I'm working on @ RCGroups

Please note I tried both, downloading the linked directory from the "flashing FW" wiki page as well as downloading from the repo, I also tried copying the text from the files in the repo directly into a new sketch, I've also verified the libraries are installed, nothing works. I'm use to going threw and fixing [sometimes a lot] of errors but this just seems like something's fundamentally messed up. Thanks in advance! If this should be split into it's own issue then I'm sorry...

errors:
sketch_sep19a:5: error: expected constructor, destructor, or type conversion before '<' token
sketch_sep19a:70: error: 'Sd2Card' does not name a type
sketch_sep19a:71: error: 'SdVolume' does not name a type
sketch_sep19a:72: error: 'SdFile' does not name a type
sketch_sep19a.ino: In function 'void systemError(byte)':
sketch_sep19a:103: error: 'NewSerial' was not declared in this scope
sketch_sep19a.ino: In function 'void setup()':
sketch_sep19a:147: error: 'NewSerial' was not declared in this scope
sketch_sep19a:159: error: 'card' was not declared in this scope
sketch_sep19a:159: error: 'SPI_FULL_SPEED' was not declared in this scope
sketch_sep19a:160: error: 'volume' was not declared in this scope
sketch_sep19a:160: error: 'card' was not declared in this scope
sketch_sep19a:161: error: 'currentDirectory' was not declared in this scope
sketch_sep19a:162: error: 'volume' was not declared in this scope
sketch_sep19a.ino: In function 'char* newlog()':
sketch_sep19a:200: error: 'SdFile' was not declared in this scope
sketch_sep19a:200: error: expected `;' before 'newFile'
sketch_sep19a:225: error: 'NewSerial' was not declared in this scope
sketch_sep19a:239: error: 'newFile' was not declared in this scope
sketch_sep19a:239: error: 'currentDirectory' was not declared in this scope
sketch_sep19a:239: error: 'O_CREAT' was not declared in this scope
sketch_sep19a:239: error: 'O_EXCL' was not declared in this scope
sketch_sep19a:239: error: 'O_WRITE' was not declared in this scope
sketch_sep19a:242: error: 'newFile' was not declared in this scope
sketch_sep19a:242: error: 'currentDirectory' was not declared in this scope
sketch_sep19a:242: error: 'O_READ' was not declared in this scope
sketch_sep19a:256: error: 'NewSerial' was not declared in this scope
sketch_sep19a:260: error: 'newFile' was not declared in this scope
sketch_sep19a.ino: In function 'void seqlog()':
sketch_sep19a:290: error: 'SdFile' was not declared in this scope
sketch_sep19a:290: error: expected `;' before 'seqFile'
sketch_sep19a:296: error: 'seqFile' was not declared in this scope
sketch_sep19a:296: error: 'currentDirectory' was not declared in this scope
sketch_sep19a:296: error: 'O_CREAT' was not declared in this scope
sketch_sep19a:296: error: 'O_WRITE' was not declared in this scope
sketch_sep19a:298: error: 'NewSerial' was not declared in this scope
sketch_sep19a:302: error: 'seqFile' was not declared in this scope
sketch_sep19a.ino: In function 'byte append_file(char*)':
sketch_sep19a:316: error: 'SdFile' was not declared in this scope
sketch_sep19a:316: error: expected `;' before 'workingFile'
sketch_sep19a:321: error: 'workingFile' was not declared in this scope
sketch_sep19a:321: error: 'currentDirectory' was not declared in this scope
sketch_sep19a:321: error: 'O_CREAT' was not declared in this scope
sketch_sep19a:321: error: 'O_APPEND' was not declared in this scope
sketch_sep19a:321: error: 'O_WRITE' was not declared in this scope
sketch_sep19a:322: error: 'workingFile' was not declared in this scope
sketch_sep19a:329: error: 'NewSerial' was not declared in this scope
sketch_sep19a:349: error: 'workingFile' was not declared in this scope
sketch_sep19a:363: error: 'workingFile' was not declared in this scope
sketch_sep19a.ino: In function 'void check_emergency_reset()':
sketch_sep19a:429: error: 'card' was not declared in this scope
sketch_sep19a:430: error: 'volume' was not declared in this scope
sketch_sep19a:430: error: 'card' was not declared in this scope
sketch_sep19a:431: error: 'currentDirectory' was not declared in this scope
sketch_sep19a:432: error: 'volume' was not declared in this scope
sketch_sep19a.ino: In function 'void read_config_file()':
sketch_sep19a:549: error: 'SdFile' was not declared in this scope
sketch_sep19a:549: error: expected `;' before 'rootDirectory'
sketch_sep19a:550: error: expected `;' before 'configFile'
sketch_sep19a:551: error: 'rootDirectory' was not declared in this scope
sketch_sep19a:551: error: 'volume' was not declared in this scope
sketch_sep19a:557: error: 'configFile' was not declared in this scope
sketch_sep19a:557: error: 'rootDirectory' was not declared in this scope
sketch_sep19a:557: error: 'O_READ' was not declared in this scope
sketch_sep19a:580: error: 'configFile' was not declared in this scope
sketch_sep19a:584: error: 'configFile' was not declared in this scope
sketch_sep19a:585: error: 'rootDirectory' was not declared in this scope
sketch_sep19a:677: error: 'NewSerial' was not declared in this scope
sketch_sep19a.ino: In function 'void record_config_file()':
sketch_sep19a:760: error: 'SdFile' was not declared in this scope
sketch_sep19a:760: error: expected `;' before 'rootDirectory'
sketch_sep19a:761: error: expected `;' before 'myFile'
sketch_sep19a:762: error: 'rootDirectory' was not declared in this scope
sketch_sep19a:762: error: 'volume' was not declared in this scope
sketch_sep19a:768: error: 'myFile' was not declared in this scope
sketch_sep19a:768: error: 'rootDirectory' was not declared in this scope
sketch_sep19a:768: error: 'O_WRITE' was not declared in this scope
sketch_sep19a:770: error: 'NewSerial' was not declared in this scope
sketch_sep19a:780: error: 'myFile' was not declared in this scope
sketch_sep19a:780: error: 'rootDirectory' was not declared in this scope
sketch_sep19a:780: error: 'O_CREAT' was not declared in this scope
sketch_sep19a:780: error: 'O_APPEND' was not declared in this scope
sketch_sep19a:780: error: 'O_WRITE' was not declared in this scope
sketch_sep19a:781: error: 'NewSerial' was not declared in this scope
sketch_sep19a:803: error: 'myFile' was not declared in this scope
sketch_sep19a:804: error: 'NewSerial' was not declared in this scope
sketch_sep19a:806: error: 'myFile' was not declared in this scope
sketch_sep19a:816: error: 'rootDirectory' was not declared in this scope

This is when pasted into a new sketch but it's the same list of errors no matter how I go about it. Please help! Thanks again.

argtrak, 2016-04-16:
I know it's frowned upon to resurrect old things, but I prefer keeping relevant stuff together instead of looking at dozens of posts for a solution that should be with the question.

I hit the same problem and was able to compile in 1.6.5 by tweaking the code a bit.  There are a few different ways we can make things work, but in essence, the compiler must see __PROG_TYPES_COMPAT__ prior to any inclusion of avr/pgmspace.h in the compile process in order for the SerialPort library to compile and be usable (in this context at least).

The easiest way I found is:
1. Add the PROG_TYPES_COMPAT line in SerialPort.h:
`#ifndef SerialPort_h`
`#define SerialPort_h`
`#define __PROG_TYPES_COMPAT__ //Needed to get SerialPort.h to work in Arduino 1.6.x`
2. Move the `#include <SerialPort.h>` statement to the top of the include block OpenLog.ino
` */`
`#include <SerialPort.h>`
`#include <SPI.h>`
`...`

This way it seems to fix both the library AND the sketch.
Hope it helps.  (Now back to trying this thing out!)

joneseym, 2021-03-28:
@argtrak it may be 5 years later but thank you, this helped me.  I'm surprised that Sparkfun have not fixed this in all that time.  The Openlog bundle referenced from the Openlog guide still contains this issue and I wasted a lot of time trying to get it to compile.

Hermesfrank, 2021-06-01:
@ohhorob's comment above (May 20, 2015)...

I had same problem today! June, 2021...the "fix", i.e.:   _#define __PROG_TYPES_COMPAT__ //Needed to get SerialPort.h to work in Arduino 1.6.x_, was already in the .ino file...

I downloaded IDE V1.6.5 for this purpose, and used it, so not sure what may still be lingering out there to cause such an issue so many years later - I guess @jonesym saw similar a few months ago...

Wonder what will happen if use current IDE?

If anyone has an insight as to another fix, please advise...

markingle, 2022-09-11:
This one was tough....I got lucky and found the solution.  Simply change the following in Serialport.h.....

const prog_char *p = (const prog_char *)s  to   PGM_P p = (PGM_P)s;

There are two lines in the SerialPort.h that need to be changed...here is a screenshot from my header file that has been updated...
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

Closed 2015-08-20.

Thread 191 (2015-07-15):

LED not working on stm32

puedpued, 2015-07-15:
The openlog works fine with arduino, the blue LED is ON when data is being transmitted.
When I use it with an STM32F411 microcontroller, the data transmits normally but the blue LED is not lit to show when it's communicating with the microcontroller.

Am I missing something? Is there a way to fix this?

Thank you in advance.

nseidle, 2015-07-15:
Hmm. Do you have the ability to check the communication with a logic analyzer? Do you know what voltage the STM is communicating at?

thenickdude, 2015-07-20:
To clarify, are you saying that the data is logged fine but the blue LED doesn't light up?

puedpued, 2015-07-20:
I know what the problem was. I had the transmitting rate too slow, hence, causing the led to hardly flash and my room was too bright to actually realize it was flashing. Once I increased the trandmitting rate it all works fine :)

Closed 2015-07-20.

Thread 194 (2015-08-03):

QC-Rev 4-way junction

ToniCorinne, 2015-08-03:
4 way junction on power supply on schematic

SFE-KADE, 2015-08-03:
fixed.

Closed 2015-08-03.

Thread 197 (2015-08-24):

READ command doesn't work properly in ASCII or RAW mode

jremington, 2015-08-24:
I'm using a Pololu USB-TTL serial converter at 9600 baud, with 3.3V IO, and a terminal program on a PC, to talk with a brand new OpenLog. Everything works properly except the actual data logging and read back, as follows. However, READ works correctly with CONFIG.TXT.

at the 12< prompt I type the following 3 lines, followed by 3 fast ctrl-Z:
line 1
line 2
last 3
^z^z^z

The latest file created was log00077.txt. If one "reads" the entire file, the output consists of some periods and the "t 3" from the third line. However, a read HEX format command works properly and shows that the contents of the file are correct. A laptop also verifies that the file contents are correct.

A typical session output follows:
12<~>ls
Volume is FAT16
CONFIG.TXT 59
LOG00076.TXT 29
LOG00077.TXT 30
>read log00077.txt
...t 3

Power down/up and repeat data entry...

12<~>ls
Volume is FAT16
CONFIG.TXT 59
LOG00076.TXT 29
LOG00077.TXT 30
LOG00078.TXT 10
LOG00079.TXT 24
>read log00079.txt 1
...t 3
>read log00079.txt 0 100 2
6C 69 6E 65 20 31 D 6C 69 6E 65 20 32 D 6C 61 73 74 20 33 D 1A 1A 1A
>read log00079.txt 0 100 1
...t 3
>read log00079.txt 0 100 3
last 3
>read config.txt
9600,26,3,0,1,1,0
baud,escape,esc#,mode,verb,echo,ignoreRX

jremington, 2015-09-09:
Fixed. Line feeds weren't being stored or printed, so the output lines were being overwritten.
New code for the "read" command follows:

        if(printType == 1) { //Printing ASCII
          //Test character to see if it is visible, if not print '.'
          if(c >= ' ' && c < 127)
            NewSerial.write(c); //Regular ASCII
          else if (c == '\r') {
            NewSerial.write(c); //Go ahead and print the carriage returns and new lines
            NewSerial.write('\n');
          }

Closed 2015-09-09.

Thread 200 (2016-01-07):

Maximum ATmega328 frequency

YvonKAP, 2016-01-07:
Hi,
I'm currently working with the OpenLog V11 board and I noticed that the crystal is 16MHz.  According to the ATmega328 datasheet, at 3.3V, 16MHz is outside the maximum frequency safe operating area.  See Figure 29-1, page 303, ATmega328 full datasheet.  Am I missing something?

http://www.atmel.com/images/atmel-8271-8-bit-avr-microcontroller-atmega48a-48pa-88a-88pa-168a-168pa-328-328p_datasheet_complete.pdf

Thanks,

BrentWilkins, 2016-01-07:
You are correct. We are running that IC out of the manufacturer's recommended safe area.

YvonKAP, 2016-01-07:
Thanks Brent.
Is there a particular reason?
If we use 12MHz instead, would the ATmega328 still be fast enough to do its job?

BrentWilkins, 2016-01-07:
The engineer wanted to be able to process buffers as quickly as possible. A common 12.5MHz clock would run in the safe operating area of Figure 28-1 of the datasheet. I believe any clock speed at least 8MHz and less than 50MHz will interface the µSD card at the same speed. That's how the Arduino SD library that's based on the same code (sdfatlib) works. Unfortunately last time I looked a lot of stuff was hard coded in Arduino to run at the more common 8MHz, 16MHz, etc. rates. I'd look into that before changing hardware.

nseidle, 2016-01-11:
Hi Yvon! Yep - this has been discussed in the product comments (our comment system pre-dates our use of github) [here](https://www.sparkfun.com/products/9530#comment-53bb7377757b7f305b8b4567) and [here](https://www.sparkfun.com/products/9530#comment-4eaad842757b7fd351001fe2). The decision was made many years ago to run OpenLog with an ATmega328P at 16MHz. This is outside the mfg recommended graph of voltage vs frequency. There is a need for speed as we pull characters from the serial buffer and out to the SD library. Running at 8MHz would degrade the performance of OpenLog for our users who are doing lots of recording, nonstop at 115200bps.

12MHz might be sufficient but, as Brent pointed out, would break the underlying serial libraries that Arduino is built on.

For now I'm closing the issue. Please re-open if you have any other concerns.

YvonKAP, 2016-01-12:
Thanks for the reply.  Maybe on a future version, you can power the AtMega at 5V and have 5V to 3.3V level shifter to access the card if there's room.  i know there's not much space available on this one.

Closed 2016-01-11.

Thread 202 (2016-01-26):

v15 hardware review [for reds]

lewispg228, 2016-01-26:
1) Does it pass SparkFun DRC? [NO]
comment: Not sure how I missed this on the checklist for proto, but there's an overlap error - a GND via sitting on the upper left pad of the SD socket, I'd like to see that via moved off that pad to prevent sucking away the paste

2) If there are any DRC errors, have they all been approved? [NO]
comment: a couple dimension errors should be approved

nseidle, 2016-01-26:
Cool. Via removed/fixed in branch v15: https://github.com/sparkfun/OpenLog/tree/hardware-v15

Closed 2016-01-26.

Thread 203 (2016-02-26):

only write every other record

s-hicks2, 2016-02-26:
I've been using more than 20 of these for the past year.  I've been very happy with their performance so far, but It seems like almost a third of the ones I bought will skip every other serial string when writing to the card.  No matter what I do, they always miss data in an alternating pattern.

For example, I power it up via the Arduino board using a relay, give it time to read the config.txt (I currently have it appending the sequential file), then send it a serial string, give it a second, then power it off.  Five minutes later, I repeat the process.  What I find is that for some of OpenLog boards, the text files will only have data every 10 minutes.  Keeping the Arduino/relay circuit the same and just swapping out the OpenLog module for another one, then the data is correctly recorded every 5 minutes.

So I've got 5 or 6 of them lying around that aren't being used because they aren't reliable enough.  Would reflashing with new code help, or is it a hardware problem, or something else?

mgrusin, 2016-02-29:
Hi there, sorry to hear you're having these problems. The developer will probably step in and try to help, but my first guess is that the bad ones aren't being given enough time to write the received data to SD before you power them down. The firmware first stores any received data in RAM, and only writes it to the SD when the RAM buffer is full, or if 500ms elapses since the last character was received. If the log is powered down before 500ms elapses, or if a stray character extends the timeout, you'll lose the data in RAM. This doesn't explain why some of your logs are working and some aren't though.

Updating to the latest code couldn't hurt; at least you'll know they all have the same baseline. (You can also check the version number of each unit in the menu if you connect to it interactively.) Beyond that, my advice is to ensure you're giving them at least one solid second (1000ms) before powering them down (500ms + a few 10s of ms to allow the write to complete + safety margin) as well as ensuring that all characters have really stopped during that time period. And since these go into a low-power sleep mode after the 500ms timeout anyway, you might consider NOT cutting power to them, and just leaving them connected to power the whole time.

If none of this fixes your problem, please contact our tech support department (techsupport@sparkfun.com). They'll probably want to examine one of the failing ones. Again sorry for the problem, I hope this helps!

nseidle, 2016-06-09:
Hi s-hicks2 - Can you post a basic example sketch that demonstrates this behavior? I'm wrapping my head around the problem.

> For example, I power it up via the Arduino board using a relay,

You control power to the OpenLog via a relay? This should be ok but OpenLog requires only a few mA so you could power it through a NPN transistor if it's easier/smaller for you.

What voltage are you providing to OpenLog via the relay? 5V should be ok.

> give it time to read the config.txt (I currently have it appending the sequential file), then send it a serial string, give it a second, then power it off. Five minutes later, I repeat the process. What I find is that for some of OpenLog boards, the text files will only have data every 10 minutes. Keeping the Arduino/relay circuit the same and just swapping out the OpenLog module for another one, then the data is correctly recorded every 5 minutes.

Very odd. I agree with mgrusin, the OpenLog will auto-record after a few hundred milliseconds if no additional serial data is received. Perhaps OpenLog is not being

nseidle, 2016-10-11:
Closing because of lack of activity. s-hicks2 if you have any updates please re-open and let us know!

Closed 2016-10-11.

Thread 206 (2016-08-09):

lower power usage

bandigore, 2016-08-09:
Is there any way to optimize the power consumption of OpenLog?  I am operating on battery power over long periods and need to conserve every electron.  Compared to my other components, OpenLog is quite power hungry.

I've thought of turning the power off between log writes (about every 30 sec).  But I'm not sure if this will gain me anything with the (assumed additional) power use during initialization.

My thought is to optimize power consumption by shutting down all unused portions of the processor. I know this is possible on the newer chips, but not sure about this one.  Maybe you've already done this?

Also great would be to add a sleep mode and be able to turn off the LEDs.

nseidle, 2016-08-18:
Power consumption is already pretty low. OpenLog automatically goes to sleep when a serial char is not received for more than 500ms:

See line 454: https://github.com/sparkfun/OpenLog/blob/master/firmware/OpenLog_Firmware/OpenLog/OpenLog.ino#L454

I believe current is around 1.5mA during sleep/idle and ~15mA when 100% logging.

Closing out. Let me know if you have other thoughts.

bandigore, 2016-08-19:
In the power save mode the processor should be using less than 1 ua.  Add
in the crystal and the regulator and I would think it would be possible to
achieve an OpenLog sleep mode of under 100 ua.  I need to get way under the
1.5 ma.  I haven't really looked at the code in any kind of depth yet.  If
you can point me to where the current sleep/idle is implemented, I'll try
to find some time to tinker with a deeper sleep mode.

Thanks,

John

On Thu, Aug 18, 2016 at 12:15 PM, Nathan Seidle <notifications@github.com>
wrote:

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

--
John der Kinderen
WNWN: "Win Win; Waste Not Want Not"
www.wnwn-llc.com
207 671 0522

nseidle, 2016-08-22:
Hi John,

Code relating to powering bits down is here: https://github.com/sparkfun/OpenLog/blob/master/firmware/OpenLog_Firmware/OpenLog/OpenLog.ino#L206

Also a tutorial I wrote awhile ago may be helpful to you: https://www.sparkfun.com/tutorials/309

I suspect the microSD card may be a vampire draw of unknown amounts (varying mfgs may have varying draws). I agree the regulator may be part of the draw but the quiescent current should be minimal.

Let me know if you find any places for improvement! I would love to make things better.

bandigore, 2016-08-22:
Thanks! It's a great little tool, but needs a few refinements. I'll see
what I can squeeze in in between my other commitments.

John

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

bandigore, 2016-08-23:
I think what I'll try first is to completely shut down between writes. What
would be the consequences of turning power on and off repeatedly (say every
few minutes)?

John

On Aug 22, 2016 7:58 PM, "John der Kinderen" <johndk@wnwn-llc.com> wrote:

Thanks! It's a great little tool, but needs a few refinements. I'll see
what I can squeeze in in between my other commitments.

John

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

nseidle, 2016-08-23:
The unit already shuts down if no characters are received after 500ms, so no consequences? :) Please have at it and let us know!

bandigore, 2016-08-23:
I'll let you know how it goes. I don't mean an idle state, but a no-power
state. It seems that should be more energy efficient if it doesn't cause
side effects.

John

On Aug 23, 2016 11:39 AM, "Nathan Seidle" <notifications@github.com> wrote:

The unit already shuts down if no characters are received after 500ms, so
no consequences? :) Please have at it and let us know!

—
You are receiving this because you authored the thread.
Reply to this email directly, view it on GitHub
<https://github.com/sparkfun/OpenLog/issues/206#issuecomment-241775478>,
or mute
the thread
<https://github.com/notifications/unsubscribe-auth/APXHEaJndMXgnsYH8qMLJ3q-V_kTLUMRks5qixQ5gaJpZM4Jf9yT>
.

lipopo, 2018-01-04:
So are there any solution that can make much more power save now?

Closed 2016-08-18.

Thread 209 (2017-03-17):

unresponsive OpenLog device, blue LED blinking 3x...

RootlessAgrarian, 2017-03-17:
I am not that experienced yet with Arduino (have worked my way through all examples in the Uno beginner book successfully).  This is my first non-Genuino part (Sparkfun OpenLog board).

So I soldered header pins onto the board, and wired it up to my Uno per this guide

http://arduino.stackexchange.com/questions/30389/where-on-uno-to-connect-blk-and-grn-pins-of-openlog-board

I then attempted to load the sketch OpenLog_CommandTest, which I DL'd from Sparkfun's web site.  This seemed to be the basic "Hello World" test for this device.

I am able to upload the sketch only if I pull the tx and rx wires, otherwise I get the dreaded avrdude error.  I posted about this error originally.   I have added a 5 sec delay into the example sketch to give me time to reinsert the wires before the sketch attempts to contact the OpenLog device:

```
//Reset OpenLog
  digitalWrite(resetOpenLog, LOW);
  delay(100);
  digitalWrite(resetOpenLog, HIGH);

  signal(1);
  delay(5000);  // plug in tx rx  wires now!
  signal(1);
```

('signal' is a void func of my own which blinks the Uno built-in LED with distinctive patterns, giving me a low level debug capability).

```
//Wait for OpenLog to respond with '<' to indicate it is alive and recording to a file
  while(1) {
    if(Serial.available())
      signal(2);
      if(Serial.read() == '<') break;
  }

```

We get the first signal (4 slow blinks), and after 5 seconds during which I plug the tx and rx wires in again, we get the second signal (4 slow blinks).  But then... no more blinks.  I conclude that Serial.available() never becomes true, and so we are stuck forever in that while loop.  I don't know why Serial.available() would never become true.

It bears repeating that I am not that experienced with Arduino.  I bought this OpenLog device because it sounded like it "just works out of the box" for logging data from an Arduino project.  I am therefore pretty much flummoxed when the demo sketch doesn't work as described;  out of my depth already.  I don't know what I should try next.  I did notice that there's no "include" macro at the top of the demo sketch;  I expected that there would be an include of some OpenLog library.  Could this be my issue?

(UPDATE) I tried the OpenLogReadExample sketch.  Once again, all my OL will do is blink its blue LED three times.  This apparently indicates a problem with the SD card;  however, this SD card formats OK as FAT (under OSX using Disk Utility), and I can put a config.txt file on it.  It mounts and unmounts under OSX without issue.  So I don't know why OL would blink at it.  Did I just get a dud unit?

nseidle, 2018-02-09:
I have re-written the example files. Please see them [here](https://github.com/sparkfun/OpenLog/tree/master/firmware/Arduino_Examples). Example1 should help you get started.

I recommend you use SoftwareSerial and avoid using the hardware serial port. Every time you upload a new sketch it can lead to accidental re-configuring of your OpenLog.

Closed 2018-02-09.

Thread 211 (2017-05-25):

Garbage Characters

dpstring, 2017-05-25:
I have an OpenLOG that is hooked up to an AliCAT mass flow controller via an 8-pin mini-DIN connector. My problem is that when it is powered up and collecting data, I get data that looks like this:

" ßÿû %ìûë %dÿë¡!dÿû BIïÿ (d{÷ÿ (auûÿAIB}ï (d{»ÿ‰(eÝûÿ % õÿ÷ $huï "hw÷ÿ AI»¯ÿ $2ûk Hdë÷ÿ
­û{% Ñû» Ûûû  úý{*

Just a bunch of unintelligible characters. I'm curious if anyone has had this same problem. It has been suggested that the OpenLOG needs to be programmed to read and interpret/parse the data correctly. Do you all agree, what could be my problem? Sorry if this is a dumb question, I'm new to most of this.

Thanks
Danny

nseidle, 2017-05-25:
Hi Danny -

There could be a few culprits. What is the baud rate that the AliCAT is outputing? OpenLog needs to be configured to communicate at that same baud rate. Is AliCAT outputting TTL serial or RS232? OpenLog only works with TTL (0 to 5V) signals, not RS232 (-9 to +9V).

dpstring, 2017-05-25:
Hmm, the baud rates are both 9600 so that is good. But I believe that the AliCAT is based around an RS232 serial. If that is the case, any suggestions? Thanks for your response!

Danny

nseidle, 2017-05-25:
No problem. First, checkout the [RS232 tutorial](https://www.sparkfun.com/tutorials/215) if you haven't already. If AliCAT is indeed outputting RS232 then I would use [this](https://www.sparkfun.com/products/449) or [this](https://www.sparkfun.com/products/8780) to convert the RS232 to TTL.

Closed 2017-05-25.

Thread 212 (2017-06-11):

Stat 1 (blue )LED pulse inconsistency.

andydswing, 2017-06-11:
I'm serial writing about 15 characters every 10 seconds at 9600 baud. I have a dozen or so loggers.

All my old loggers pulse the blue LED for about 250ms and I have had no data issues on 4GB and 8GB sandisk cards. For months, sometimes years, at a time.

My new loggers seem to do 250ms pulses and then randomly drop to 25ms pulses and I'm not sure if they are logging data in the same reliably way. I've had a few 0 byte log files. It's a bit unnerving as these need to go into the field soon. They are right on top of a promini.. close proximity.

Andy ideas??

andydswing, 2017-06-11:
I should mention that my ProMini is 5V and I think the Tx is also 5V. Openlog appears to require 3.3V - I never noticed this before. Is openlog compatible with 5V ProMinis?

nseidle, 2017-06-12:
It may be different versions of firmware. If you have access to a good and bad units please drop to the command prompt (usually 3 x ctrl+z) and send the '?' [command](https://learn.sparkfun.com/tutorials/openlog-hookup-guide#command-set). This will give you the firmware version on the units.

The LEDs may be behaving differently but can you confirm that data is being recorded differently?

andydswing, 2017-06-13:
The units are brand new from digikey.

The good news is that the data seems to be fine. But it's unnerving when it goes from a relatively long blue pulse to a short blip. Something is changing.

nseidle, 2017-06-13:
It's still unclear to me if you have units of all the same age (firmware would be the same) or if you have units from very different time periods (we have customers with 4+ years in between versions).

Sounds like the units are working as designed. On [this line](https://github.com/sparkfun/OpenLog/blob/master/firmware/OpenLog_Firmware/OpenLog/OpenLog.ino#L449) the write time may vary depending on the card write times and even what section of the card is being written to (it may take a few extra ms for the controller to locate a new/good section of flash for these bytes to be written to).

I'm going to close out this issue but do please raise a flag if you see any problems.

Closed 2017-06-13.

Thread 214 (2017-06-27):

Using hardware flow control

tostasmistas, 2017-06-27:
Hi,

I'm using the OpenLog to record data at 115200bps, sent by a device at a rate of 8 bytes per 1ms. The uSD card is a 32GB SanDisk Extreme PRO, UHS-I Class 3.

To have better control over the UART transmission we are using hardware flow control. For this, we shunted one of the GPIO pins of the MCU of the OpenLog to the CTS pin, and set it as a digital output that we are abe to control. In terms of firmware, we have based our work on v4.0 of the OpenLog Minimal version.

We have adjusted the loop of the `appendFile()` function so that it works as follows:

```
while (1) {
  charsToRecord = NewSerial.read(buff, sizeof(buff));
  if (charsToRecord > 0) {
    charsCount += charsToRecord;
    toggleLED(stat1);
    workingFile.write(buff, charsToRecord);
  }
  if (charsCount >= CHAR_COUNT) {
   digitalWrite(cts, HIGH);
   _delay_ms(1);
   workingFile.sync(); // sync the card
   digitalWrite(cts, LOW);
   charsCount = 0;
  }
}
```
Instead of controlling the sync by time, we are doing it by counting the bytes. Whenever we have recorded `CHAR_COUNT` bytes (set at the moment to 384), the OpenLog should sync the card. However, before doing this, we set the CTS pin HIGH so we can suspend the UART transmission from the device, with the goal of possibly avoiding data loss. This device is capable of internally storing ~1400 bytes, which should give us time to sync the file and resume the data transmission, once the CTS pin is set to LOW.

Even though we are using this flow control technique we are still experiencing some data loss. To better understand what is happening, we recorded to the SD card the state of the CTS pin. The next picture shows the temporal representation of the state of the pin for a time when there was data loss.

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

For some reason, the sync operation seems to have taken longer time to complete. On average, this operation lasts ~5ms, but we registered a maximum of ~145ms, which caused the data loss. Furthermore, this occasional longer sync appears to be periodic, for instance we recorded continuously for ~35mins, and the fails happened at minutes 1, 15 and 30.

Is the card doing some internal housekeeping that could justify this behaviour? Our goal is to record continuously at 115200bps, without data loss.

I should also mention that because in our application we are doing some JSON encoding and decoding, we have to use the ArduinoJson library, limiting the overall available memory. As such, the serial RX buffer has 512 bytes instead of 1024.

alexpirine, 2018-01-24:
Hi,

I am also interested in the continuous 115200 bps logging. Any success since you opened the issue?

tostasmistas, 2018-01-24:
Hi,

Yes, I was able to do it successfully. I ended up removing the JSON enconding and decoding, so the serial RX buffer could have a size of 1024 bytes. This change along with the hardware flow control mechanism provided good results.

I did extensive performance tests and I could log data for 24h-40h without loss of packets. You can see the hardware modifications I did on the OpenLog board and the firmware in this [repo](https://github.com/BITalinoWorld/firmware-loggerbit).

Closed 2018-01-24.

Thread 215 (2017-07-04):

openlog power consumption

pvfpvf, 2017-07-04:
I hooked up an openlog to my PC. 5V supply. Nothing connected to pins 1 (marked BLK) and 6 (marked GRN). It works fine. However the current consumption is weird.

After power on (in mode 0): 21.5 mA, lowering momentarily to 6 mA whenever a character is sent to openlog
After switching to command mode: 26.2 mA continuous (stays like that after a READ or DISK command)
After giving LS command: 7 mA
After giving ECHO OFF  command: back to 27 mA (echo was off anyway)
After giving APPEND command: 1.5 mA until first char sent, then 21.5 mA continuous falling to 7 mA as each char sent.

There doesn't seem go be a command to find firmware version. I am not using an Arduino.

Is this how it should behave?

pvfpvf, 2017-07-22:
I am disappointed no one has decided to look into this matter. The current consumption is excessive and clearly irrational. There must be something wrong with this software. It limits the utility of openlog in battery powered applications.

nseidle, 2018-02-09:
I apologize for the slow response. I was incorrectly filtering github issue notifications.

Pressing ? at the command prompt will give you a list of commands as well as the firmware version at the start of the help menu. This is documented under the low level commands on the [hookup guide](https://learn.sparkfun.com/tutorials/openlog-hookup-guide#command-set).

I believe OpenLog is performing as designed. When the device is in command mode it is not low power, it does not go to sleep, it does not turn off the LEDs. As you type commands the status LED will turn on/off and the LED is responsible for ~20mA of current. The processor not sleeping is another 5-10mA.

To test overall system current consumption make sure the device is in mode 0 (config file setting). With no other wires or devices attached, insert a microSD card and power with 5V and GND. Interrupt the 5V line with a DMM in current measuring mode. When the DMM is attached the OpenLog should power up, briefly blink the LEDs, then turn off the LEDs indicating it has gone to sleep. This should draw less then 2mA (1.5mA on the unit on my desk). When you enter command mode it will increase to ~20mA as you were seeing and alternate as the status LEDs turn on/off with each key stroke received.

nseidle, 2018-04-18:
Please open a new issue. The original issue possibly describes connecting an OpenLog to a PC's serial or USB port. Both of which are generally bad ideas (12V on serial port can fry the OpenLog pins, USB is not TTL serial).

pvfpvf, 2018-04-18:
No it doesn't, and that's just an excuse toavoid facing the issue. Naturally I used an FT232R. However, I lost interest in this matter some time ago.

nseidle, 2018-04-18:
@pvfpvf - I had not heard back from you so I closed this issue. Can you answer the questions, mainly what firmware version you have?

Additionally, so I can replicate your issue:

* What platform are you using?
* What version of the device are you using? Is there a firmware version?
* How is the device wired to your platform?
* How is everything being powered?
* Are there any additional details that may help us help you?

I have tried to replicate this issue but cannot. If you've lost interest, I totally understand. Perhaps @zmeeaag can help me figure out the problem.

zmeeag, 2018-04-20:
Platform: Windows/ STM32
Product/FW version: It's been a while since I've looked at this. But I believe it was the latest OL firmware. All boards were purchased across the past year.
Connection/p: FTDI USB->TTL adapter / STM32L4 w/ HW UART
Power: Regulated 3.3V and 5V rails
Not sure it helps but the original support email went in on May 30th, 2017 at 1:44pm MDT. I can forward you the email chain if you'd like.

nseidle, 2018-04-25:
Here's what I found:

* Firmware version: OpenLog v4.0 (fresh off the shelf production unit)
* Connection: Arduino hardware TX, VCC, and GND to OpenLog
* Powered from 3.3V on Arduino (in an attempt to match your STM32 3.3V power)
* SD Type: Cheap card, 512mb
* During standby - 2.4mA
* During constant record - 7.5mA
* Sitting at command prompt waiting for character - 7.2mA

To measure the current I interrupted the 3.3V line to the OpenLog.

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

Above - standby

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

Above - constant read

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

Above - sitting at command prompt with LED on

I cannot replicate @pvfpvf's findings. Do either of you have simplified code that I can use to replicate your measurements? If you think this is still an issue I'm happy to do a hardware swap.

nseidle, 2018-04-25:
Btw - I added an [example sketch](https://github.com/sparkfun/OpenLog/blob/master/firmware/Arduino_Examples/Example6_GetVersionNumber/Example6_GetVersionNumber.ino) to help you obtain your firmware version without a USB connection.

zmeeag, 2018-04-29:
How about a simplified HW setup?
I connected one to 3.3V through a multimeter and it immediately started drawing 20mA immediately on power up.

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
I then went to check the FW version by hooking up a 3.3V ftdi cable and putting the OL into command mode. When I did this the current increased to 23.6mA. Here is a screenshot of the serial terminal including the card information.
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

If I remove the card then the current draw goes down to 7mA in command mode, which is about what I'd expect (and what you've reported)

Now to the interesting bit. Some SD cards work a lot better than others.  I have an 8GB ATP card here:
Card type: SDHC
Manufacturer ID: 9
OEM ID: AP
Product: AF UD
Version: 0.2
Serial number: 1741636114
Manufacturing date: 3/2017
Card Size: 8039 MB
that does properly return down to a lower current (<2mA!) which is awesome

I have a 16GB Kensington card here:
Card type: SDHC
Manufacturer ID: 27
OEM ID: PH
Product: SD16G
Version: 3.0
Serial number: 784587265
Manufacturing date: 7/2017
Card Size: 15590 MB
That starts low (~3mA) but the second anything is written to it the current jumps to ~17mA and won't come back down until a read operation occurs (I generally use ls as it's really simple to do)

lastly I have a 16GB card I purchased from SF with the OL a while back:
Card type: SDHC
Manufacturer ID: 2
OEM ID: TM
Product: SA16G
Version: 2.4
Serial number: 2813862936
Manufacturing date: 5/2016
Card Size: 15489 MB
This one starts at ~20mA and blips *down* to ~7.5mA with each character it gets before returning up to 20mA on an idle serial line.

Is there some "sleep" step that needs to be done to higher performance cards that got missed?

nseidle, 2018-04-30:
Really interesting. Thanks for the numbers! In addition (someday), please measure the current outside of command mode as well, as command mode is the highest (no sleep) mode.

The current consumption of the SD card is the result of the flash controller and AFAIK sleep control is not accessible via SPI commands.

I'll keep trying to find SD cards that mimic your behavior. This issue looks like it's outside the purview of the OpenLog firmware.

pvfpvf, 2018-04-30:
Thanks to you both. You have inspired me to revisit the issue. I bought 3 openlogs in June 2017, tested one, and reported the above anomalies. I then built one into some equipment, destroyed one, and I've just managed to find the third. Meanwhile I had used it as an Arduino Uno and overwritten the openlog software. So I reinstalled the openlog bundle I'd downloaded in March 2018. Testing this with a Sandisk Ultra 16GB HC I card, it does not show the anomalies I reported. Nor is it's consumption as high. But I don't know if the SD card is the same as last June's, nor what openlog version was in the June hardware. For details of current test results, please see
https://www.dropbox.com/s/ivs1sz8oz401z8g/openlog_consumption_201804.mp4?dl=1
(about 75 MB).
In a sense I am sorry to have bothered you now about it, but it really was there last June.

nseidle, 2018-04-30:
Hi pvfpvf - I have never had such a pleasant interaction on Github! You have no need to apologize, I should have responded to your issue *much* faster than I did.

Thank you, your video is superb and highlights the current consumption in different modes.

When OpenLog is in command mode the ATmega never goes to sleep. Thus we see the ~10mA current consumption. For each letter that is pressed in command mode the LED toggles on/off. Your video expertly shows 9.2mA when the LED is off and 9.9mA when the status LED is on. Not much of a difference but it is part of the equation.

When in normal logging mode the ATmega will go to sleep when there is 500ms of no serial traffic and the unit should go down to the 3 to 4mA range *and* turn off the power LED. What I think the issue is, and your issue is valid, is that different SD cards can use different currents, regardless of how much we sleep the ATmega.

I'll grab a microSD card from our production stock to test as well because zmeeag reported high current from a card they bought from us.

And if you managed to fry an OpenLog, I'm impressed! They are pretty hardy. I will email you separately about replacing hardware.

zmeeag, 2018-04-30:
Little bit of research is pointing me towards some cards being less tolerant of floating pins than others when trying to go to sleep (See Cave Pearl Project). This sorta matches the behavior I'm seeing with the card where the power consumption drops when its active.  Might be worth looking into in the long run, but for now I've moved these over to a switched power rail. Wish I had the time to dig into this further it seems like a really fun project.

nseidle, 2018-04-30:
Hmm. Floating pins could be the problem? That's interesting. I could drive the pins on the SPI interface low before going to sleep...

Here is a [version of OpenLog](https://github.com/sparkfun/OpenLog/files/1962365/OpenLog.zip) where I drive the SPI pins low before sleep (pins 10, 11, 12, 13). I'll call it beta for now.

Current usage: v4.0 firmware / beta firmware
Transcend 8GB: 2.0/2.1
512MB Generic: 2.4/2.4
16GB Kingston: 3.2/3.3

I don't see much of a difference but I haven't found a power-hog SD card yet. If you can load new firmware please give it a try.

pvfpvf - I pulled a [16GB Kingston](https://www.sparkfun.com/products/13833) from our stock to check if the cards we are (currently) selling are a problem. I don't think they are.

nseidle, 2018-11-03:
Closing issue due to lack of activity. Please re-open if anyone has power issues or information.

nseidle, 2019-01-24:
This is a very new issue that is unrelated to power consumption. Please open a new issue.

Closed 2018-11-03.

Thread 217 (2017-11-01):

RXI pin voltage 3.2v , seemingly preventing serial data reception (or it's dead)

dmalnati, 2017-11-01:
Hi,

I think my OpenLog may have gone bad (though I don't know why it was in a box for a year since I last used it successfully).

Short story is that OpenLog doesn't appear to be receiving Serial data properly.
Looking more closely with a scope (Saleae) I measure the RXI pin as having a voltage of around 3.2v, which I believe is either the cause of Serial data not being received, or a symptom of the unit having died somehow.

To illustrate I have two screenshots below:
- the first in isolation from all other circuit elements (and showing the RXI voltage)
- the second being in circuit with a microcontroller and the voltage changes on RXI as Serial data is received.  Here the voltage varies, but not full 0v-5v swings, instead it's within 2v-3.5v, which is wrong.

I have tried tying RXI to ground to reset any bad configuration (no change).
I have not flashed any new firmware because I just suspect this unit is busted.

Can you tell me what might be going on, or perhaps send me another?  My original order number was 2839165.

Again, this used to work in 2016 when I last used it.  Now it doesn't, and I didn't change anything.  I even ran the original working test code I wrote for it and no luck.

When completely isolated from any microcontroller, simply plugged into a power supply:
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

When on the same circuit as a properly functioning microcontroller and receiving serial data:
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

Thanks.

doug

nseidle, 2018-02-04:
Hi dmalnati - Sorry for the very late response. My github notifications were being filtered.

I'm happy to get you a replacement unit if you're still working on a project that could use an OpenLog.

A few things to check:

* With nothing but VCC/GND attached, do you see the status LEDs do anything? You should see activity at power on. If you don't, there's something more wrong than the RX pin.
* Format the SD card, reinsert, apply power. You should see status LEDs active then turn off. Check contents of SD card with computer. Does the config.txt file appear? If not, there may be a problem with the microSD socket.

dmalnati, 2018-02-08:
Hi Nathan,

Thank you for getting back to me.

Unfortunately I have already thrown away the module and replaced it with
another so I can't do any testing beyond what I wrote up in the bug report.

I'd be happy to take a replacement if it's covered by warranty or
anything.  I can't imagine why it died, and the replacement worked in the
same conditions that the replaced one didn't.

Thanks.

doug

On Sat, Feb 3, 2018 at 7:29 PM, Nathan Seidle <notifications@github.com>
wrote:

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

nseidle, 2018-02-08:
Hi Doug - No worries. Yep, I'll email you.

dmalnati, 2018-02-09:
Thanks!

On Thu, Feb 8, 2018 at 3:24 PM, Nathan Seidle <notifications@github.com>
wrote:

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

Closed 2018-02-08.

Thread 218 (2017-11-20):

Reduce clock speed to 8 MHz, can not properly log @ 115200 baud rate

ewan1983, 2017-11-20:
I use Openlog to connect with my board, and got a lot of small files, seems Openlog have been keep resetting. I suspect it was a power issue as my board have only 3V supply, and it might not be enough to drive 16MHz clock as in default Openlog.

So I modified the F_CPU configuration in boards.txt to 8MHz `uno.build.f_cpu=8000000L, `
and in `setup(void)` function of OpenLog_Minimal firmware, I add
`clock_prescale_set(clock_div_2);`

The result is that I can only correctly log one character, if send more than one character only the first one is correctly logged, and the rest are corrupted. The problem is probably in serial rx part, but I haven't figure out what exactly the problem is.

The `setting_uart_speed` is 115200, when this problem happens. If I change the baud rate to 57600, everything is fine. So I thought high baud rate got problem, then I change the baud rate to 200000, it also works! Only 115200 got problem, WTF?

However, at 8 MHz and 200000 baud rate, I still have multiple small files, and have many data missing in-between.

alexpirine, 2018-01-24:
Hi,

Have you solved the issue?

marshalltaylorSFE, 2018-01-24:
I ran into a similar issue on another project using an 8MHz processor and 115200.  The problem is that there simply isn't enough time to service the ISR between bytes.  By the time the serial ISR completes, we're mid-way into the next byte.  Thus garbage.

If you can cause your serial transmitter to emit two stop bits instead of one, it gives an extra symbol's worth of time between the bytes.  With my test, this was enough to get the data correctly.  Otherwise, get the voltage up so you can run at 16MHz.

alexpirine, 2018-01-24:
Which voltage is required for 16 MHz? I currently use 3.3 V and sometimes it works, sometimes I get plenty of log files and lose data in between...

alexpirine, 2018-01-24:
Is it possible to set an arbitrary clock speed like 12 MHz?

marshalltaylorSFE, 2018-01-24:
3.3V should be fine.  ewan1983's issue is exactly a baud related problem... if you're getting solid chunks of data, then just missing some, that sounds like a different issue entirely.  Can you post another issue with more information about your setup that causes intermittent lost of data?

I explored 12MHz for my other project.  There's no easy way to scale things to 1.5x, so it would take a bit of research and modification to the project and maybe even the board files in Arduino.

JensGrabner, 2018-01-24:
Here is a calculator for that: http://wormfood.net/avrbaudcalc.php?bitrate=57.6k%2C76.8k%2C115.2k&clock=8%2C+12%2C+16&databits=8
I use 3V3 with 12MHz Clock a Baud Rate 115.2k (U2Xn = 1)  is good ...
and 3V3 with 8MHz Clock a Baud Rate 76.8k (U2Xn = 1)  is also good.

alexpirine, 2018-01-24:
Thanks for the tips. I am running at 3.3V and 115200 baud rate with the "minimal" firmware.

And I get multiple open log files instead of just one.

I will be happy to open a new issue if this not related to the clock (which is at 16 MHz by default from my understanding) / voltage.

Closed 2018-01-24.

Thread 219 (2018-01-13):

Flashing with avrdude

alexpirine, 2018-01-13:
Hello,

I wanted to update the firmware of my OpenLog device, and I encountered a lot of problems on my Mac.

So I tried using `avrdude`. Sometimes flashing succeeds, sometimes it fails, but the device never properly works. And eventually, I can not even flash it anymore.

I compiled hex files in Arduino UNO (should I use Uno or Pro Mini as target?).

I then flashed them with `avrdude` (should I flash with or without bootloader ?).

I wonder if, before flashing, I should set the fuse values?

Currently, my chip reads:

```
avrdude: Device signature = 0x1e950f (probably m328p)
avrdude: safemode: lfuse reads as 62
avrdude: safemode: hfuse reads as D9
avrdude: safemode: efuse reads as FF
```

Should I change these values before flashing? I think my problems might be related to the fuse settings.

I found that values used by Arduino IDE are different:

https://github.com/arduino/Arduino/blob/dc5827e08b5e269d3d22322cefaed90a14191b89/hardware/arduino/avr/boards.txt

Which values should I use?

Thank you!

alexpirine, 2018-01-14:
I think I bricked about 4 OpenLog devices now… I don't understand why writing OpenLog firmware to flash with OpenLog firmware changes fuses incorrectly sometimes. And sometimes it says that everything is OK, but when I boot the device, the TX/RX led is flashing and the device is not responding to any commands. Under oscilloscope the TX pin seem to send data at some non-standard baudrate…

The bricked devices no longer work and avrdude reads random chip identifiers now (like 0x00ff00, 0x0000ff…). If I try to force it with `-F`, it just says it cannot read fuses.

I am using an Arduino nano as ISP. I learned plenty of things, but still have so many random problems… I don't understand why is it so difficult to flash using the SPI pins? I never thought it I would struggle with this so much.

alexpirine, 2018-01-24:
Works now with a USBAsp device I bought.

Closed 2018-01-24.

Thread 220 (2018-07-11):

Garbled Data, No Serial RX

BigDave365, 2018-07-11:
### Garbled Data, No Serial

I cannot seem to get my Open Log to work properly.

Lights work as described in wiki. Will create a config file on sd card. Will record data file on sd card.

Data fed from GPS is totally garbled. GPS data tested good via FTDI and terminal (9600,8,N,1).

Data is also corrupted if sent directly to OpenLog via FTDI.

Openlog will NOT generate a prompt, or go in command mode.

Openlog will not reflash via Arduino IDE.

I reflashed via USBASP with clips, same result.

Any Ideas?

nseidle, 2018-07-11:
Hmm, did you use a cross over board to align the tx pin of openlog to the
rx pin of your terminal?

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

BigDave365, 2018-07-11:
You mean OpenLog TX to FTDI RX and vice versa? Yes, I check it backwards as well, and the Openlog receives no data.

Is there any way to get an older copy of the firmware to give that a try?

Thanks for the help!

-Dave

nseidle, 2018-07-11:
You can compile from the [source](https://github.com/sparkfun/OpenLog/tree/master/firmware/OpenLog_Firmware/OpenLog) (it's just an Arduino sketch with a lib or two). Also, I had the sketch handy so I compiled it.

[OpenLog.ino.with_bootloader.eightanaloginputs.zip](https://github.com/sparkfun/OpenLog/files/2186352/OpenLog.ino.with_bootloader.eightanaloginputs.zip)

This version might be slightly non-production: I was doing some work on the other issue (SPI current consumption).

BigDave365, 2018-07-16:
I got it sorted...what an adventure.

Thanks for the help. I did end up using your .Hex file, but the root of the problem was I was using a chip from bare metal and did not program the fuses. The defaults will give the results I had (no response to serial and garbage data).

For those that might need them, here is what worked for me with Avrdude and a UsbASP:

High = 0xD6
Low =  0xFF
Ex  = 0x05

Lock Bit = 0x0F

Thanks again for the project and help.

-Dave

nseidle, 2018-07-16:
That is good news! Just so I understand, you have your own ATmega328P+microSD design/setup? Not one of our OpenLogs? I ask because I'm always trying to make our issue system better. Next time I'll be sure to specifically ask what a user's setup is.

Closed 2018-07-16.

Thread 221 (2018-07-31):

echo and verbose commands issue

danistrigaro, 2018-07-31:
### Subject of the issue
My OpenLog [1] seems to stuck after setting the echo or verbose parameter to off/on. It is not able to receive any more commands.

### Your workbench
* I'm using Arduino Mega wired to this OpenLog [1]
* The firmware version is the 4.0
* wiring schema ---> RX of the Openlog to TX2 of the Arduino; TX of the Openlog to RX2 of the Arduino
* The OpenLog is powered by 5V; the Arduino by 7V
* With other version of OpenLog everything works fine
* if I do not use the verbose or echo commands the others (set, md, read, cd, etc.) work as expected

### Steps to reproduce
Type through Serial2 "echo off/on" or "verbose off/on" before any other commands

### Expected behavior
Parameters configured without blocking the next commands sent.

### Actual behavior
The echo or verbose command works as expected and a '>' will appear, but for any other commands sent after, the exception "unknown command " is prompted together with a mirrored question mark.
Once the Arduino is reset a series of "1212121121212..." is printed in the serial monitor

Best
Daniele

[1] https://www.epal.pk/product/openlog-serial-to-micro-sd-data-logger-module/

nseidle, 2018-08-01:
Ick. Sounds like the unit is crashing when verbose is disabled. I'll try to dig into it today. In the mean time are you able to operate with verbose on?

danistrigaro, 2018-08-02:
Thank you for your response! There is the same behavior if we put verbose or echo to on...

nseidle, 2018-08-02:
It sounds like the verbose and echo commands are causing problems. If you do a [emergency reset](https://learn.sparkfun.com/tutorials/openlog-hookup-guide#troubleshooting), does the OpenLog record data as expected?

> With other version of OpenLog everything works fine

Do you mean you have another OpenLog board that works ok or did you load a different firmware version?

Since we did not build this board it can be difficult to troubleshoot. Please contact EPal and see if they have support.

danistrigaro, 2018-08-20:
I solved the issue by buying a new OpenLog directly from Sparkfun.
I tried to flash the firmware using Arduino UNO as ISP but it did not work.
I wrote to epal (linking also to this discussion) but they said that I have to update the firmware.
Thanks for you kind and fast support!

nseidle, 2018-08-20:
Thanks for coming back to let us know! I'm sorry Epal is shipping units with different firmware. If you have any other problems please ask.

Closed 2018-08-20.

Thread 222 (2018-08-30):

How to read the file number from eeprom and reset it from config.txt ?

sorenoneill, 2018-08-30:
### Subject of the issue

Two simple(?) questions:
a) is it possible to read the auto-inc number of the current file? (I would like to present this on a digit display to the user)
b) Is it possible to reset the auto-inc number via the config file?

### Your workbench
* Arduino Uno
* BN: Arduino/Genuino Uno
* VID: 2341
* PID: 0043
* SN: 55731323935351C011A1
* Breadboard for now -- soldered soon
* Via Arduino

nseidle, 2018-11-03:
Hi - sorry for the slow reply.

a) Currently we do not have a way to read the auto-increment log number via command. However, you can use the [ls command](https://learn.sparkfun.com/tutorials/openlog-hookup-guide#command-set) to list the files and identify the last file number.

b) Good question, I'm sorry but currently we don't offer that option. I never thought someone would need to reset the log number via the config file. I really don't want to add another variable to the config file (it's already getting a bit large) so for now I'll create a feature request/issue for it.

Closed 2018-11-03.

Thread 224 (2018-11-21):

Verbose and echo mode always turn on.

usernamesarelreadytaken, 2018-11-21:
### Verbose and echo mode always turn on.
I try to change config of openlog using config.txt I can change baud rate normally but for echo and verbose, I can't turn them off.

### How I connect openlog to my data streaming device
- I connect Tx, Rx directly to my Rx, Tx of my device.

### Steps to reproduce
I write my config.txt as
> 115200,26,3,0,0,0,1
> baud,escape,esc#,mode,verb,echo,ignoreRX

When I use my openlog, it always show my config as I wrote in config.txt

but when I format my SDcard and try to see current config of my openlog it show as
> 115200,26,3,0,1,1,1
> baud,escape,esc#,mode,verb,echo,ignoreRX

If I change baud rate to 57600 by changing config.txt to
> 57600,26,3,0,0,0,1
> baud,escape,esc#,mode,verb,echo,ignoreRX

and checking my current config on openlog, it show as
> 57600,26,3,0,1,1,1
> baud,escape,esc#,mode,verb,echo,ignoreRX

Please help

nseidle, 2018-11-28:
I thought this [sounded familiar](https://github.com/sparkfun/OpenLog/issues/208). Looks like I changed how the verbose setting was stored, whereas the echo setting was stored the original way. Not good. Let me dig into it.

nseidle, 2018-11-28:
Thanks for reporting this bug! I've committed a new INO. Please load [this new INO](https://github.com/sparkfun/OpenLog/blob/master/firmware/OpenLog_Firmware/OpenLog/OpenLog.ino) and let me know if you still have the issue.

usernamesarelreadytaken, 2018-11-29:
@nseidle Thanks. I have try it. No issue found now.

nseidle, 2018-11-29:
Very good! Thanks for testing it out.

Closed 2018-11-28.

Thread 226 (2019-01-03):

Checking if OpenLog is connected

Keudra, 2019-01-03:
I want to check first if OpenLog is conected to my board before I start sending informations.
My idea was to create a new file and delete it afterwards to see if it works. Is there a better way to do it?

I'm using a stm32L100 with I2C for communication.

nseidle, 2019-01-03:
I'm slightly confused. Are you using [OpenLog](https://github.com/sparkfun/OpenLog) (serial interface) or [Qwiic OpenLog](https://github.com/sparkfunX/Qwiic_OpenLog) (I2C)?

Regular Serial OpenLog: You can check to see if the '12<' characters come through

Qwiic I2C OpenLog: You can check to see if the I2C device responds to the correct I2C address.

Keudra, 2019-01-04:
I'm using the serial interface with UART. I2C was an other project sorry for the confusion.
I would like to check if it's avalible without checking a visual interface. I'm planning to use it by its own using some selfmade functions.

Keudra, 2019-01-09:
I'm try to fetch the answer from the OpenLog but it seams that it isn't working, because I ounly get the same data from the UART. It doesn't mather if I send a command befor it or not, it's always 536887084.
This is the function how I would like to see if the OpenLog is connected to the board.
`HAL_StatusTypeDef checkLogger(){
       char buffer[100];
	int l;

	l = sprintf(buffer,"new test.txt\r\n");

	HAL_UART_Transmit(&huart1, buffer, l, 1000);

        HAL_UART_Receive(&huart1, buffer, 1, 1000);
	if(strcmp(buffer, 536887084) == 0){	//thats the part where I would check if it received <
                l = sprintf(buffer,"rm test.txt\r\n");

		HAL_UART_Transmit(&huart1, buffer, l, 1000);
		return HAL_OK;
         }
         return HAL_Error;
}
`

Closed 2019-01-14.

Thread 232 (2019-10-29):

Empty Log File

rzurbuch, 2019-10-29:
### Subject of the issue
I have the OpenLog connected to some proprietary hardware.  Our HW is sending UART data (115200bps) to the OpenLog.  We also have the OpenLog RXI line connected to an o-scope to verify UART traffic.  When we power up the HW and the OpenLog, we see activity on the o-scope for a bit and it stops (let's call this Activity#1).  There is around 100 bytes of data sent to the OpenLog before going idle. We remove the SDCard and the log is empty.  We plug the SDCard back into the OpenLog.  We make the HW send some more UART data (maybe 100 more bytes, let's call this Activity #2).  We remove the SDCard and we see data but it is from Activity #1.  For some reason the buffer isn't being purged.  My understanding is that the buffer should be sent to the SDCard when there is 500ms of UART idle time.

### Your workbench
* What platform are you using?  OpenLog v4.0, Current boot mode: New file

* What version of the device are you using? I'm not sure where this information is located.  We bought from DigiKey and haven't changed the code on the OpenLog.  Is there a firmware version?  v4.0
* How is the device wired to your platform?  GRN (DTR): open, RXI connected to UART at 3.3V, TX0:  open, VCC = 5V
* How is everything being powered?  Our Proprietary HW is powering the unit with 5V.
* Are there any additional details that may help us help you?
     From the "disk" command:
     Card type: SDHC
     Manufacturer ID: 9F
     OEM ID: TI
     Product: SD32G
     Version: 6.1
     Serial number: 671776948
     Manufacturing date: 10/2018
     Card Size: 31104 MB

### Steps to reproduce
I can't seem to reproduce on a standalone OpenLog.  I'm only able to reproduce when it is connected to our HW.

### Expected behavior
I expect that all UART data should be recorded to the SDCard.  It shouldn't sit in the RAM of the micro.

### Actual behavior
See above.

rzurbuch, 2019-10-30:
> Test #1:  Show that the log file in the SD Card is empty after sending data to the OpenLog ...
1.  Power up the OpenLog
2. wait for the OpenLog to go to sleep (>2seconds)
3. Send the OpenLog some UART data:  "This is the 1st message."
4. If you look at the current log in the SDCard, it should be empty.

Test #2:  Show that the log file doesn't contain all the data sent to the OpenLog.  The last bit of data is stored in the OpenLog buffer and isn't sent to the SD Card.
1.  Power up the Open Log.
2.  wait for the OpenLog to go to sleep (>2seconds).  I used 3 seconds.
3.  Send the OpenLog some UART data:  "This is the 1st message."
4.  wait for the OpenLog to go to sleep (>2seconds).  I used 3 seconds.
5.  Send the OpenLog some UART data:  "This is the 2nd message."
6.  If you look at the current log in the SDCard, it should show the first message ("This is the 1st message" but won't show the second message ("This is the 2nd message.").

nevercast, 2020-01-15:
I think I may be seeing this issue also, on a fresh OpenLog bought from SparkFun

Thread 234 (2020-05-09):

No LogFile / Problems Update Firmware

Thor2018, 2020-05-09:
Hello guys,
I have a problem with my OpenLog. When i insert a FAT32 formatted sd card (Formatted with Windows) nothing happens. No lights blinking, nothing. When i open up my sdcard in windows, there is no "config.txt" file created. I connected VCC, GND and RX from the OpenLog.

After that i tried to update the firmware on the openlog. I connected all Pins from my FT232RL board (DTR, RX, TX, VCC, GND, CTS) to the Open Log including swaping Rx/Tx (like the picture on the wiring page here).
I tried to Upload the normal OpenLog File with the correct COM Port, Board Arduino Uno and programmer "AVRIPS mkII". But i get the typical error:
`avrdude: stk500_recv(): programmer is not responding
avrdude: stk500_getsync() attempt 1 of 10: not in sync: resp=0x39`

I also tried to programm via "Arduino Pro or Pro Mini" and the processor ATmega238P 5V, but nothing changed.

I have Arduino IDE Version 1.8.9 and Arduino AVR Board Version 1.6.21 (I also tried with 1.8.2 - but the error still exists).
My FT232 Board can manage 3,3V or 5V. I tried both, but the same error.

Do you have any ideas oder solution hints for me? That would be awesome!

Best regards, Thor

nseidle, 2020-05-12:
Please fill out the issue form so we can help you.

Sounds like your OpenLog doesn't have a bootloader on it. Where did you purchase the OpenLog from? Do you have an order #?

Does (did?) the OpenLog work correctly with a FAT16 formatted card?

What version of firmware is appearing on your OpenLog?

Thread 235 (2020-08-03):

SparkFun_Qwiic_Relay library 1.2.0 warnings when -fpermissive is not set

PickyBiker, 2020-08-03:
The Quad Solid State library Example2_Quad_Relay_Basics sketch compiles without errors or warnings using the Arduino UNO in the Arduino IDE. That is because with that board in that IDE the -fpermissive compile flag is set by default.

If you try to compile that board using a Teensy board, the -fpermissive flag is not set and the compiler generates the numerous warnings. Please correct the code so  it works without warnings when using Teensy boards.

In addition, the default I2C address is "RELAY_ADDR 0x6D // Alternate address 0x6C" but when an I2C scan is performed the actual board address (just purchased and unaltered) appears to be 0x08.

Here is the environment being used:
OS: Windows 10
IDE: Arduino version 1.8.12
Boards: Arduino UNO and Teensy 4.0
SparkFun_Qwiic_Relay library 1.2.0
The Quad Relay board is the one in this kit: [](https://www.sparkfun.com/products/16833)

The errors are cause by 2 lines of code in the SparkFun_Qwiic_Relay.cpp file. The changes I tested (shown below) resolve the warnings issue but you may want to apply a different fix.

line #340   original _i2cPort->requestFrom(_address, 1);
line #340   no warnings with:  _i2cPort->requestFrom((uint16_t)_address, 1);

line #353   original:   _i2cPort->requestFrom(_address, 2);
line #353  no warnings with:  _i2cPort->requestFrom(**(uint16_t)**_address, 2);

The requestFrom function expects the address argument to be a 16bit int but_address is an 8 bit value. Without -fpermissive this generates the warnings.

The warnings are in this attached file.
[Errors.txt](https://github.com/sparkfun/OpenLog/files/5019243/Errors.txt)

PaulZC, 2020-08-04:
Hi @PickyBiker ,
You have opened this issue in the SparkFun OpenLog repo. Can you please close and re-open it in the Qwiic Relay library repo?
https://github.com/sparkfun/SparkFun_Qwiic_Relay_Arduino_Library
Best wsihes,
Paul

PickyBiker, 2020-08-04:
Closed because it was in the wrong forum.

Closed 2020-08-04.

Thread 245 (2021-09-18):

Unable to return to System Config menu after executing some of the 'set' menu commands (hang)

EmbeddedMan, 2021-09-18:
### Subject of the issue
Unable to return to System Config menu after executing some of the 'set' menu commands (hang)

### Your workbench
Windows 10 Pro, fresh compile of OpenLog firmware with Arduino IDE v1.8.15

Using genuine OpenLog hardware from SparkFun, purchased several months ago.

Using OpenLog.ino v4.2 (most recent at this date)

OpenLog hardware only connection is through FTDI cable to PC using jumper wires as described in SparkFun OpenLog hookup guide.

Powered only through FTDI power

Using TeraTerm on PC to communicate with OpenLog

Contents of config.txt file:
115200,26,3,0,1,1,0
baud,escape,esc#,mode,verb,echo,ignoreRX

No other files on SD card at boot

### Steps to reproduce
1) Connect to OpenLog from TeraTerm
2) Get "12<" as output from OpenLog
3) Hit <ctrl-z> three times rapidly
4) OpenLog drops down into command mode
5) Get "~>" from OpenLog
6) Type "set" then enter
7) See System Configuration menu
8) Type "1", do not press enter
9) Receive "1New file logging" from OpenLog
10) OpenLog is now hung. No combination of commands, characters, <ctrl-z>s will induce OpenLog to respond in any way. No log file is generated or appended. OpenLog must be rebooted (disconnect/reconnect serial connection) in order to regain any functionality.

### Expected behavior
10) OpenLog should return to normal command mode and accept commands like "?" and "set". At least that's what a code review shows should be happening.

### Additional Debugging Information
Adding printf()s in the code shows that recordConfigFile() is completely executing, saving the 'set' menu choice properly to the config file and EEPROM, and then returns to systemMenu() just fine, which returns back up into the while(1) loop in commandShell() just fine. But something crashes before another loop through the while(1) can be made and so we never get to the  NewSerial.print(F(">")); statement at the top of the loop. I'm stuck here - maybe a stack problem? Maybe some sort of timing related hang when printing serial?

I'm assuming this worked at some point back in maybe November 2018 when @nseidle made the last code change. Maybe it's something to do with the compiler settings of the newer Arduino IDEs?

EmbeddedMan, 2021-09-18:
Another note here: if you simply exit from the 'set' menu with the 'x' command, it works fine. You get the ">" prompt and all System Configuration menu options work fine. Menu option "4" also appears to work fine. But all the rest ("1", "2", "3", "5" and "6") cause the crash to happen.

EmbeddedMan, 2021-09-18:
I have confirmed that the line "if (readLine(buffer, sizeof(buffer)) < 1)" is where the crash is occurring.

I have confirmed that commenting out the call to recordConfigFile() prevents the crash from occurring.

So something in recordConfigFile() is causing a problem that then makes the crash happen at the top of the commandShell() loop when readLine() is called.

EmbeddedMan, 2021-09-18:
I have confirmed that the exact same code, compiled under Arduino IDE 1.6.8 works fine. So something about the newer compiler/IDE/build process is what is causing the change in behavior. Maybe part of it is that the newer IDE/compiler (1.8.15) makes a much smaller image (25,188 bytes compared to 27,652 bytes for IDE v1.6.8).

It would still be great to figure out why readLine() is crashing. But at least we now know why it was working in the past and how to get it to work as a workaround (use older IDE version).

EmbeddedMan, 2021-09-18:
And it is the memset() in readLine() that is triggering the crash.

EmbeddedMan, 2021-09-19:
Confirmed: Stack corruption. In readLine(), the value of 'buffer' used in memset() is being changed by something in recordConfigFile(). The memory location 'buffer' points to the first time through the command loop (when things work) is 2238. But after a call to recordConfigFile() it has gotten changed to 190.

After an immense amount of debugging, I'm confident that there is some stack corruption going on inside recordConfigFile() which only shows itself as a crash when the memset() line in readLine() is called.

The workaround solution that I've found is to make the buffer[] array in commandShell() static. This appears to completely eliminate the problem, although it's not clear why. Another, more complicated way to eliminate the problem is to create a global volatile pointer to the buffer[] array, copy the address of the buffer[] array in commandShell(). This changes the way the compiler uses the global[] array in such a way that the crash doesn't happen. Again, I'm not exactly sure how.

Is this worth a pull request? Or is it better to just use an older Arduino IDE? Not sure. I'll leave this hear for anyone who wants to dive deeper into this problem, but I'm not able to spend any more time on it at present.

nseidle, 2021-09-20:
Hi EmbeddedMan - Thanks for digging into all this! If I following the issue correctly, when you compile and load the 'stock' firmware, you have this issue. But if you use an off-the-shelf unit from SparkFun (with a binary that has been presumably compiled with an earlier version of Arduino) the issue goes away? If that's true, I may need to de-emphasize this issue a bit. I haven't touched this firmware in a long time and OpenLog sells very well so I'm hesitant to risk adding a potential variable to the stability of the firmware.

That said, your feature request is a great one. I'll try to make time for this issue and the feature in the coming weeks.

EmbeddedMan, 2021-09-20:
I don't know about the stock firmware from SparkFun - I did not test this feature on any of the 20 something OpenLogs we ordered before I put my own customized firmware on (see upcoming PR for adding log rotate mode). I know that compiling the latest code from this repo with the latest Arduino IDE version does cause the failure. You probably should double check a unit from stock just to be sure it doesn't have this problem. My assumption is that it's fine, as nobody else has complained about it.

Agreed with this not being a big issue for production OpenLogs if your existing hex file is working fine. However, maybe you should create a 'production' branch of the repo with an updated Readme saying which version of IDE you used to compile the production hex file so that people can get to that version if they want. If your production code isn't going to change, but the code here will continue to add features/bugfixes, that should probably be notated somewhere obvious (The OpenLog hookup guide maybe?) I just don't want users to get confused by thinking that the latest code from this repo with the latest IDE version gives them the same thing that comes from SparkFun.

EmbeddedMan, 2021-10-12:
Heh, that's good at least. Now we just need to find a solution (or strongly warn users away from using newer IDE versions). The engineer in me really wants to know why this is failing and find a way to fix it. :-)

EmbeddedMan, 2021-10-12:
Yeah at this point what we could use is somebody who has experience debugging Arduino code with a hardware debugger. I suspect that if you had that ability and a little time it would become obvious what's getting corrupted and how. Just too hard to do with printf() debugging only.

nseidle, 2021-10-12:
Found it. It looks like I hit this problem before. [This line's comments](https://github.com/sparkfun/OpenLog/blob/master/firmware/OpenLog_Firmware/OpenLog/OpenLog.ino#L996) points out that **strcpy_P()** adds a null pointer but that strlen does not consider \0 as a character. So the array needs +1. I suspect `strcpy_P(configFileName, PSTR(CFG_FILENAME));` was dutifully copying the 'config.txt' string, then adding \0 past the last spot of configFileName[] causing corruption to the RAM next door. In your case, it was buffer[30]. By casting `static char buffer[30];` you pushed the corruption to a different part of RAM, but it was still getting corrupt.

In your PR, I've made sure both config.txt and SEQLOG00.TXT are terminated and any use of strcpy_P has the appropriate sized array to store the incoming string.

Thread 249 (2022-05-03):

Random data corruption

creagan01, 2022-05-03:
### Subject of the issue
This is more of a question than a issue.  Just wondering if this is something anyone may have seen before.

I am seeing random corrupted data samples, about every 2000 or 3000 samples.

Each sample is a data structure containing a 4 byte timestamp and a 4 byte sample value.
The timestamp is never corrupted only the sample value.
The corrupted values are very similar (first 3 bytes always the same) but way out of the range of what the sample value should look like.
Sample rate is 65Hz.
Data snippet shown below is a test example logging an incrementing 32bit integer.

<html xmlns:v="urn:schemas-microsoft-com:vml"
xmlns:o="urn:schemas-microsoft-com:office:office"
xmlns:x="urn:schemas-microsoft-com:office:excel"
xmlns="http://www.w3.org/TR/REC-html40">

<head>

<meta name=ProgId content=Excel.Sheet>
<meta name=Generator content="Microsoft Excel 15">
<link id=Main-File rel=Main-File
href="file:///C:/Users/creagan/AppData/Local/Temp/msohtmlclip1/01/clip.htm">
<link rel=File-List
href="file:///C:/Users/creagan/AppData/Local/Temp/msohtmlclip1/01/clip_filelist.xml">
<style>
<!--table
	{mso-displayed-decimal-separator:"\.";
	mso-displayed-thousand-separator:"\,";}
@page
	{margin:.75in .7in .75in .7in;
	mso-header-margin:.3in;
	mso-footer-margin:.3in;}
tr
	{mso-height-source:auto;}
col
	{mso-width-source:auto;}
br
	{mso-data-placement:same-cell;}
td
	{padding-top:1px;
	padding-right:1px;
	padding-left:1px;
	mso-ignore:padding;
	color:black;
	font-size:11.0pt;
	font-weight:400;
	font-style:normal;
	text-decoration:none;
	font-family:Calibri, sans-serif;
	mso-font-charset:0;
	mso-number-format:General;
	text-align:general;
	vertical-align:bottom;
	border:none;
	mso-background-source:auto;
	mso-pattern:auto;
	mso-protection:locked visible;
	white-space:nowrap;
	mso-rotate:0;}
.xl65
	{mso-number-format:Scientific;}
-->
</style>
</head>

<body link="#0563C1" vlink="#954F72">

39597 | 2178
-- | --
39613 | 2179
39629 | 2180
39644 | 1.48E+20
39660 | 2182
39676 | 2183
39692 | 2184
39707 | 2185

</body>

</html>

### Your workbench
* What platform are you using?
 SparkFun OpenLog wired to a Noridic nRF52840
* What version of the device are you using? Is there a firmware version?
 OpenLog v4.2
* How is the device wired to your platform?
RX/TX to UART?  It is a prototype so wiring is a bit messy but it works, well, almost.  :)
* How is everything being powered?
The SparkFun board is powered by the same 3.3v that the Nordic device is using, so, some dropout there.
* Are there any additional details that may help us help you?
Running at 115,200 baud, using command mode.  I escape to command mode about every 4.5hrs  and start appending to a new log file but all that seems to be working fine.

Below is the config.txt:
115200,90,8,2,0,1,0
baud,escape,esc#,mode,verb,echo,ignoreRX

I can provide further information if needed.

Thanks

creagan01, 2022-05-05:
After further debugging, I have found the problem with my code.  This issue can be closed.

nseidle, 2022-05-05:
Good find! Thanks for letting us know.

Closed 2022-05-05.

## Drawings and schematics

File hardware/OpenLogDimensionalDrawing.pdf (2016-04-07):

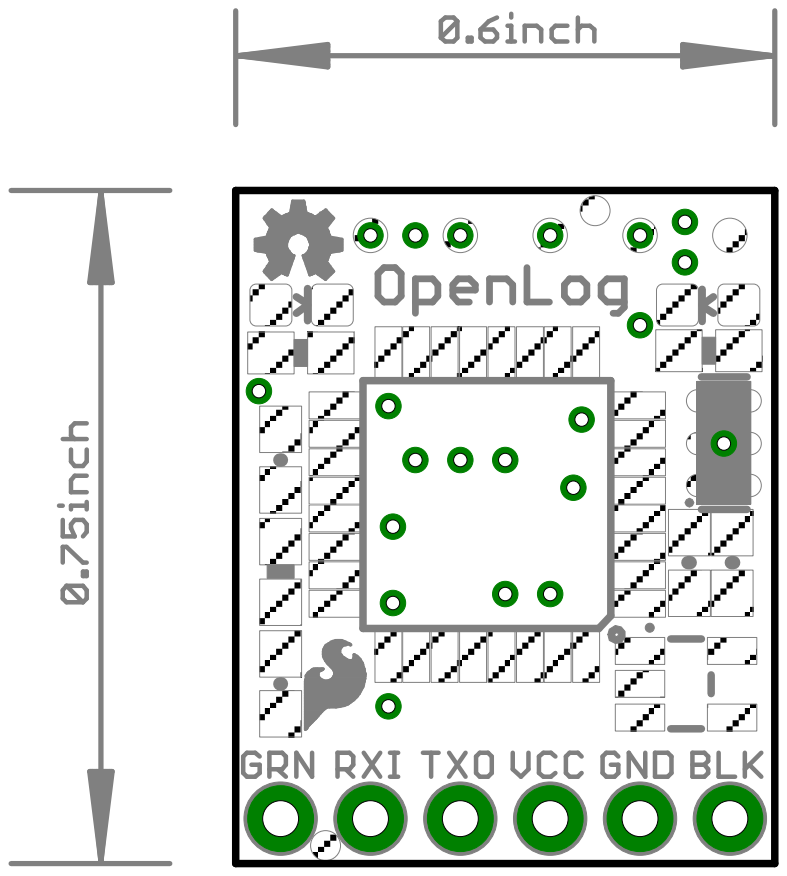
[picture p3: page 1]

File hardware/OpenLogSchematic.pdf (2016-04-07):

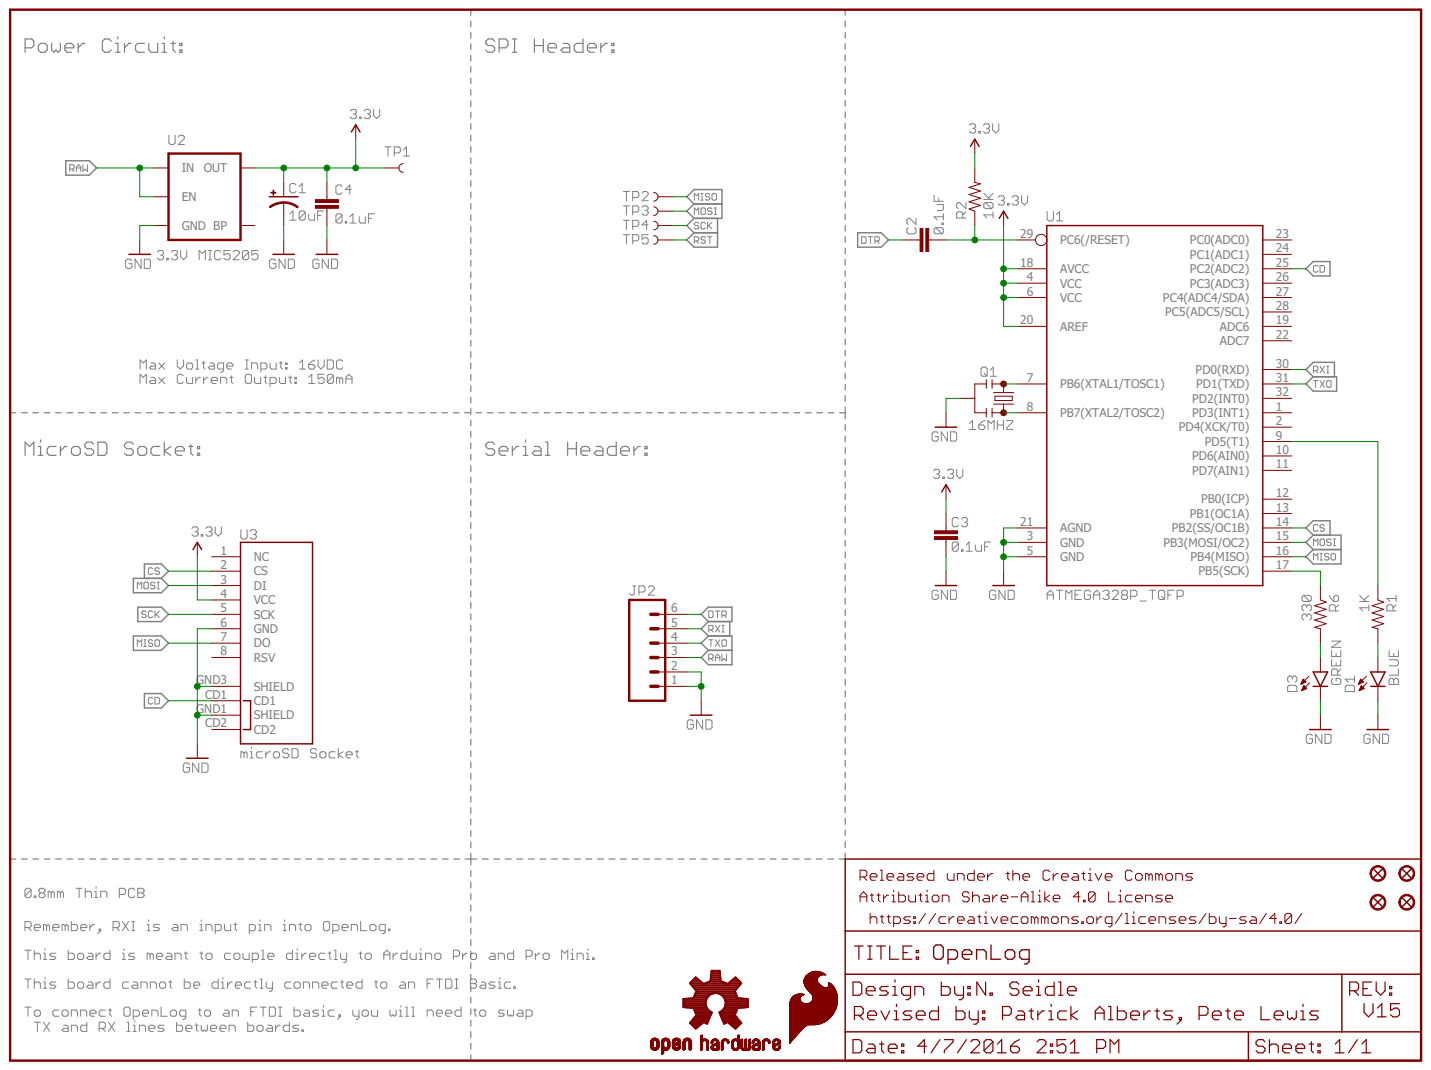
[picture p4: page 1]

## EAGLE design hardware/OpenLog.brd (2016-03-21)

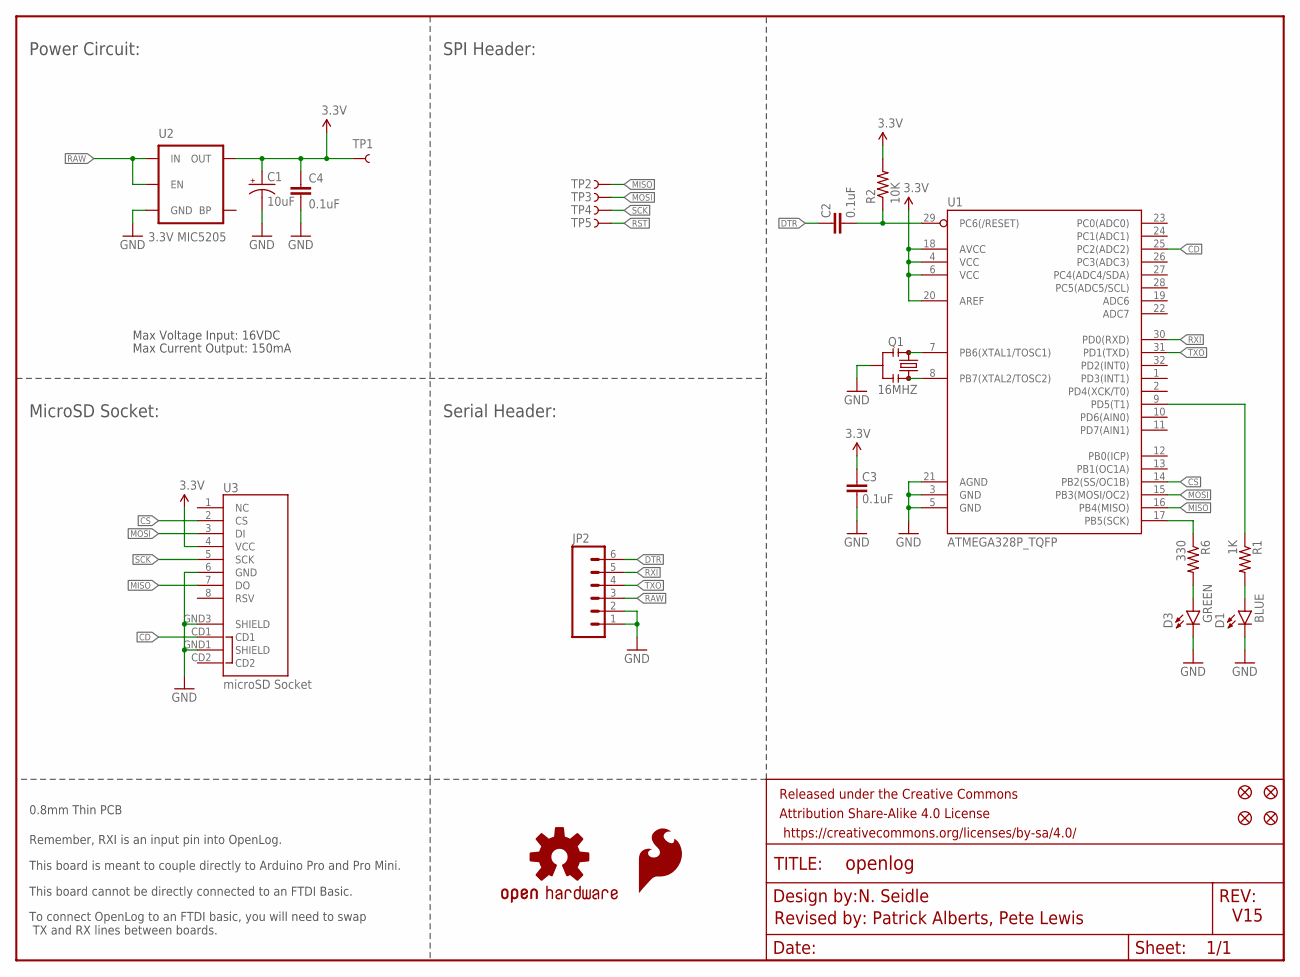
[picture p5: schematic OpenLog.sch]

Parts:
C1: 10uF; 0603-POL
C2, C3, C4: 0.1uF; 0603-CAP
D1: BLUE; LED-0603
D3: GREEN; LED-0603
FID1, FID2, FID3, FID4: FIDUCIALUFIDUCIAL; MICRO-FIDUCIAL
FRAME1: FRAME-LETTER; CREATIVE_COMMONS
JP2: M06NO_SILK_FEMALE_PTH; 1X06_NO_SILK
LOGO1: SFE_LOGO_FLAME.1_INCH; SFE_LOGO_FLAME_.1
LOGO2: OSHW-LOGOMINI; OSHW-LOGO-MINI
Q1: 16MHZ; RESONATOR-SMD
R1: 1K; 0603-RES
R2: 10K; 0603-RES
R6: 330; 0603-RES
TP1, TP2, TP3, TP4, TP5: TEST-POINT3; PAD.03X.03
U1: ATMEGA328P_TQFP; TQFP32-08
U2: 3.3V MIC5205; SOT23-5
U3: microSD Socket; MICROSD_1:1

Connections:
3.3V: C1.A (+), C3.2, C4.1, R2.2, TP1.P$1, U1.4 (VCC), U1.6 (VCC), U1.18 (AVCC), U1.20 (AREF), U2.5 (OUT), U3.4 (VCC)
CD: U1.25 (PC2(ADC2)), U3.CD1
CS: U1.14 (PB2(SS/OC1B)), U3.2 (CS)
DTR: C2.2, JP2.6
GND: C1.K (-), C3.1, C4.2, D1.C, D3.C, JP2.1, JP2.2, Q1.2, U1.3 (GND), U1.5 (GND), U1.21 (AGND), U2.2 (GND), U3.6 (GND), U3.GND1 (SHIELD), U3.GND3 (SHIELD)
MISO: TP2.P$1, U1.16 (PB4(MISO)), U3.7 (DO)
MOSI: TP3.P$1, U1.15 (PB3(MOSI/OC2)), U3.3 (DI)
unnamed: Q1.1, U1.8 (PB7(XTAL2/TOSC2))
unnamed: Q1.3, U1.7 (PB6(XTAL1/TOSC1))
unnamed: D1.A, R1.2
unnamed: R1.1, U1.9 (PD5(T1))
unnamed: D3.A, R6.2
RAW: JP2.3, U2.1 (IN), U2.3 (EN)
RST: C2.1, R2.1, TP5.P$1, U1.29 (PC6(/RESET))
RXI: JP2.5, U1.30 (PD0(RXD))
SCK: R6.1, TP4.P$1, U1.17 (PB5(SCK)), U3.5 (SCK)
TXO: JP2.4, U1.31 (PD1(TXD))

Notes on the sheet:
Max Voltage Input: 16VDC
Max Current Output: 150mA
Remember, RXI is an input pin into OpenLog.
This board is meant to couple directly to Arduino Pro and Pro Mini.
This board cannot be directly connected to an FTDI Basic.
To connect OpenLog to an FTDI basic, you will need to swap TX and RX lines between boards.
V15
N. Seidle
Revised by: Patrick Alberts, Pete Lewis
0.8mm Thin PCB
Power Circuit:
Serial Header:
MicroSD Socket:
SPI Header:

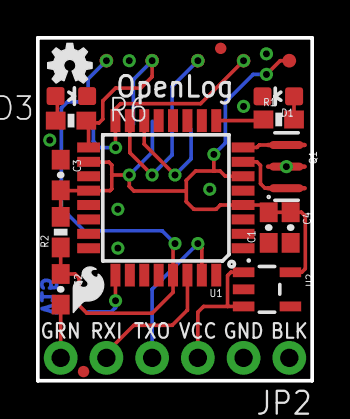
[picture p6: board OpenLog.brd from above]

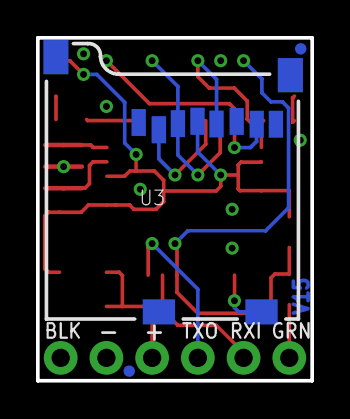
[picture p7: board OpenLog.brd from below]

Board: 2 copper layers, 15.2 x 19.1 mm, 26 parts (3 on the bottom side), 17 nets.

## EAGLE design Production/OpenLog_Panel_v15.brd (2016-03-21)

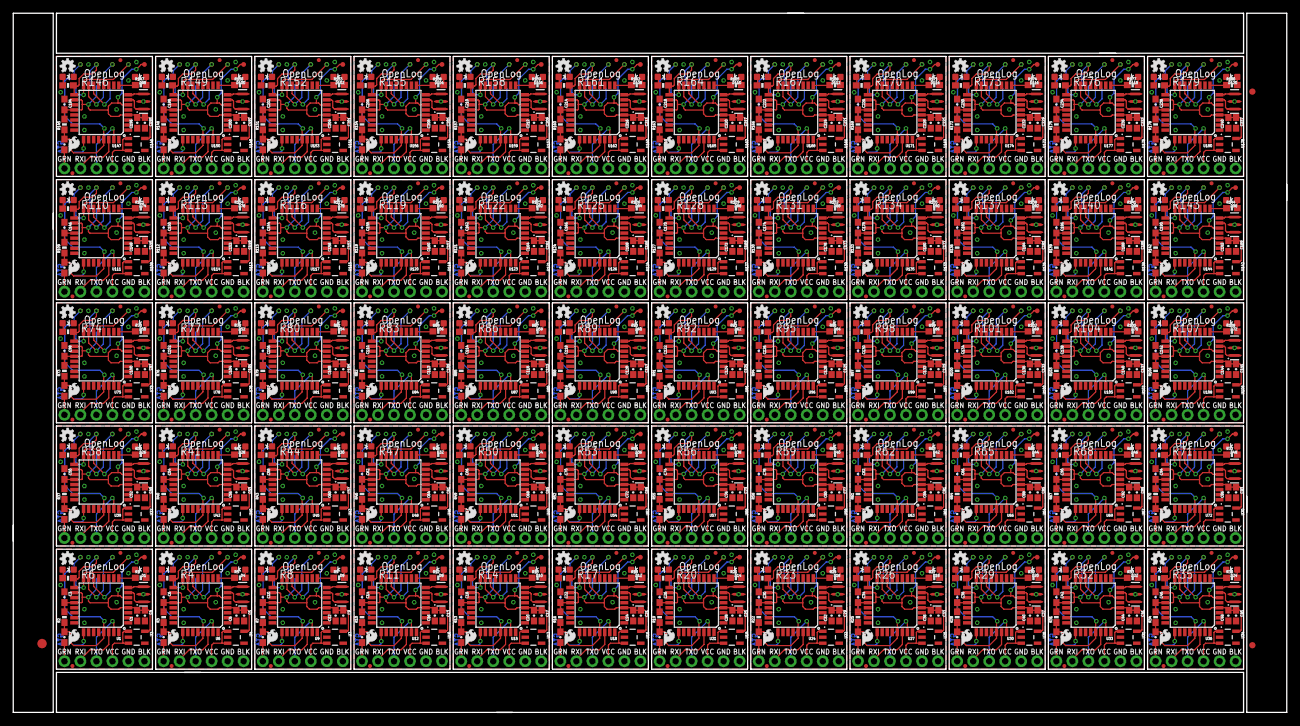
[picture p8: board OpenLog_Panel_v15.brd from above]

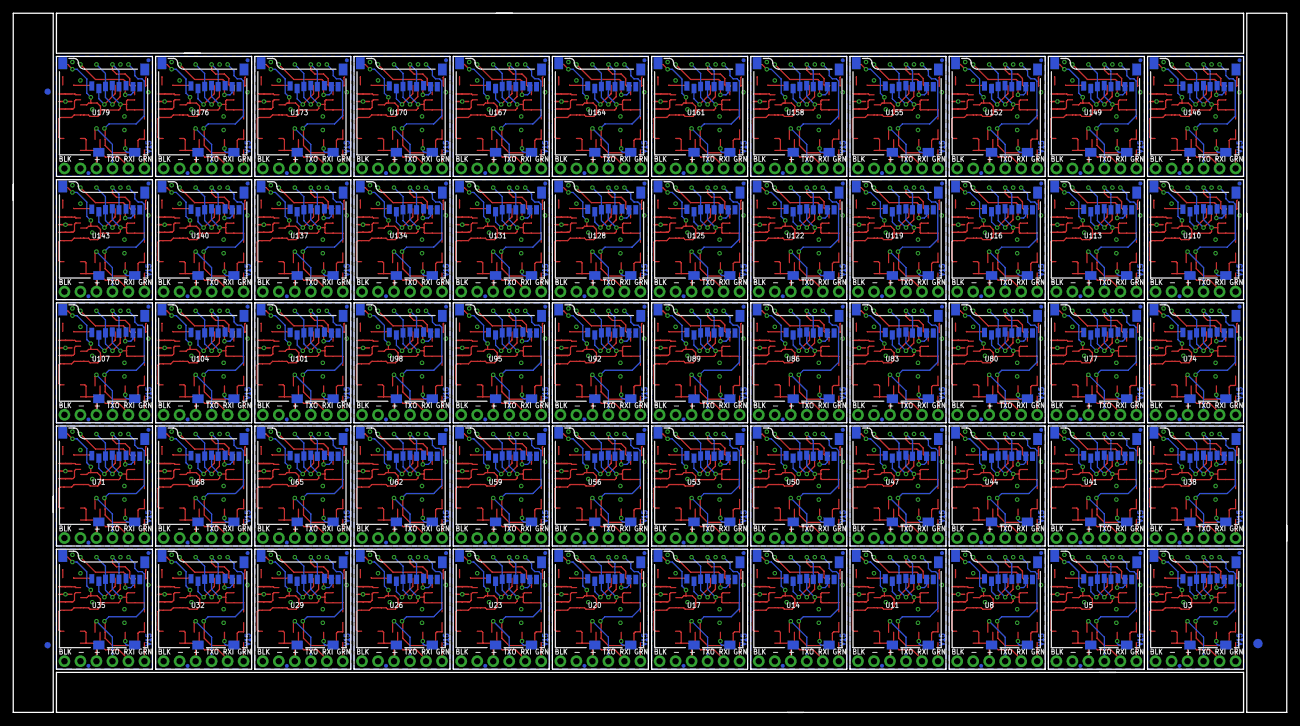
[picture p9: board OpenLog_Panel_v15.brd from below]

Board: 2 copper layers, 202.2 x 111.0 mm, 1506 parts (183 on the bottom side), 1020 nets.

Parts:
C1, C8, C12, C16, C20, C24, C28, C32, C36, C40, C44, C48, C52, C56, C60, C64, C68, C72, C76, C80, C84, C88, C92, C96, C100, C104, C108, C112, C116, C120, C124, C128, C132, C136, C140, C144, C148, C152, C156, C160, C164, C168, C172, C176, C180, C184, C188, C192, C196, C200, C204, C208, C212, C216, C220, C224, C228, C232, C236, C240: 10uF; 0603-POL
C2, C3, C4, C5, C6, C7, C9, C10, C11, C13, C14, C15, C17, C18, C19, C21, C22, C23, C25, C26, C27, C29, C30, C31, C33, C34, C35, C37, C38, C39, C41, C42, C43, C45, C46, C47, C49, C50, C51, C53, C54, C55, C57, C58, C59, C61, C62, C63, C65, C66, C67, C69, C70, C71, C73, C74, C75, C77, C78, C79, C81, C82, C83, C85, C86, C87, C89, C90, C91, C93, C94, C95, C97, C98, C99, C101, C102, C103, C105, C106, C107, C109, C110, C111, C113, C114, C115, C117, C118, C119, C121, C122, C123, C125, C126, C127, C129, C130, C131, C133, C134, C135, C137, C138, C139, C141, C142, C143, C145, C146, C147, C149, C150, C151, C153, C154, C155, C157, C158, C159, C161, C162, C163, C165, C166, C167, C169, C170, C171, C173, C174, C175, C177, C178, C179, C181, C182, C183, C185, C186, C187, C189, C190, C191, C193, C194, C195, C197, C198, C199, C201, C202, C203, C205, C206, C207, C209, C210, C211, C213, C214, C215, C217, C218, C219, C221, C222, C223, C225, C226, C227, C229, C230, C231, C233, C234, C235, C237, C238, C239: 0.1uF; 0603-CAP
D1, D4, D6, D8, D10, D12, D14, D16, D18, D20, D22, D24, D26, D28, D30, D32, D34, D36, D38, D40, D42, D44, D46, D48, D50, D52, D54, D56, D58, D60, D62, D64, D66, D68, D70, D72, D74, D76, D78, D80, D82, D84, D86, D88, D90, D92, D94, D96, D98, D100, D102, D104, D106, D108, D110, D112, D114, D116, D118, D120: BLUE; LED-0603
D2, D3, D5, D7, D9, D11, D13, D15, D17, D19, D21, D23, D25, D27, D29, D31, D33, D35, D37, D39, D41, D43, D45, D47, D49, D51, D53, D55, D57, D59, D61, D63, D65, D67, D69, D71, D73, D75, D77, D79, D81, D83, D85, D87, D89, D91, D93, D95, D97, D99, D101, D103, D105, D107, D109, D111, D113, D115, D117, D119: GREEN; LED-0603
E$1, E$2: FIDUCIAL-1.5X3
E$3, E$4, E$7, E$8: FIDUCIAL-1X2
FID1, FID2, FID3, FID4, FID5, FID6, FID7, FID8, FID9, FID10, FID11, FID12, FID13, FID14, FID15, FID16, FID17, FID18, FID19, FID20, FID21, FID22, FID23, FID24, FID25, FID26, FID27, FID28, FID29, FID30, FID31, FID32, FID33, FID34, FID35, FID36, FID37, FID38, FID39, FID40, FID41, FID42, FID43, FID44, FID45, FID46, FID47, FID48, FID49, FID50, FID51, FID52, FID53, FID54, FID55, FID56, FID57, FID58, FID59, FID60, FID61, FID62, FID63, FID64, FID65, FID66, FID67, FID68, FID69, FID70, FID71, FID72, FID73, FID74, FID75, FID76, FID77, FID78, FID79, FID80, FID81, FID82, FID83, FID84, FID85, FID86, FID87, FID88, FID89, FID90, FID91, FID92, FID93, FID94, FID95, FID96, FID97, FID98, FID99, FID100, FID101, FID102, FID103, FID104, FID105, FID106, FID107, FID108, FID109, FID110, FID111, FID112, FID113, FID114, FID115, FID116, FID117, FID118, FID119, FID120, FID121, FID122, FID123, FID124, FID125, FID126, FID127, FID128, FID129, FID130, FID131, FID132, FID133, FID134, FID135, FID136, FID137, FID138, FID139, FID140, FID141, FID142, FID143, FID144, FID145, FID146, FID147, FID148, FID149, FID150, FID151, FID152, FID153, FID154, FID155, FID156, FID157, FID158, FID159, FID160, FID161, FID162, FID163, FID164, FID165, FID166, FID167, FID168, FID169, FID170, FID171, FID172, FID173, FID174, FID175, FID176, FID177, FID178, FID179, FID180, FID181, FID182, FID183, FID184, FID185, FID186, FID187, FID188, FID189, FID190, FID191, FID192, FID193, FID194, FID195, FID196, FID197, FID198, FID199, FID200, FID201, FID202, FID203, FID204, FID205, FID206, FID207, FID208, FID209, FID210, FID211, FID212, FID213, FID214, FID215, FID216, FID217, FID218, FID219, FID220, FID221, FID222, FID223, FID224, FID225, FID226, FID227, FID228, FID229, FID230, FID231, FID232, FID233, FID234, FID235, FID236, FID237, FID238, FID239, FID240: FIDUCIALUFIDUCIAL; MICRO-FIDUCIAL
JP1, JP2, JP3, JP4, JP5, JP6, JP7, JP8, JP9, JP10, JP11, JP12, JP13, JP14, JP15, JP16, JP17, JP18, JP19, JP20, JP21, JP22, JP23, JP24, JP25, JP26, JP27, JP28, JP29, JP30, JP31, JP32, JP33, JP34, JP35, JP36, JP37, JP38, JP39, JP40, JP41, JP42, JP43, JP44, JP45, JP46, JP47, JP48, JP49, JP50, JP51, JP52, JP53, JP54, JP55, JP56, JP57, JP58, JP59, JP60: 1X06_NO_SILK
LOGO1, LOGO3, LOGO5, LOGO7, LOGO9, LOGO11, LOGO13, LOGO15, LOGO17, LOGO19, LOGO21, LOGO23, LOGO25, LOGO27, LOGO29, LOGO31, LOGO33, LOGO35, LOGO37, LOGO39, LOGO41, LOGO43, LOGO45, LOGO47, LOGO49, LOGO51, LOGO53, LOGO55, LOGO57, LOGO59, LOGO61, LOGO63, LOGO65, LOGO67, LOGO69, LOGO71, LOGO73, LOGO75, LOGO77, LOGO79, LOGO81, LOGO83, LOGO85, LOGO87, LOGO89, LOGO91, LOGO93, LOGO95, LOGO97, LOGO99, LOGO101, LOGO103, LOGO105, LOGO107, LOGO109, LOGO111, LOGO113, LOGO115, LOGO117, LOGO119: SFE_LOGO_FLAME.1_INCH; SFE_LOGO_FLAME_.1
LOGO2, LOGO4, LOGO6, LOGO8, LOGO10, LOGO12, LOGO14, LOGO16, LOGO18, LOGO20, LOGO22, LOGO24, LOGO26, LOGO28, LOGO30, LOGO32, LOGO34, LOGO36, LOGO38, LOGO40, LOGO42, LOGO44, LOGO46, LOGO48, LOGO50, LOGO52, LOGO54, LOGO56, LOGO58, LOGO60, LOGO62, LOGO64, LOGO66, LOGO68, LOGO70, LOGO72, LOGO74, LOGO76, LOGO78, LOGO80, LOGO82, LOGO84, LOGO86, LOGO88, LOGO90, LOGO92, LOGO94, LOGO96, LOGO98, LOGO100, LOGO102, LOGO104, LOGO106, LOGO108, LOGO110, LOGO112, LOGO114, LOGO116, LOGO118, LOGO120: OSHW-LOGOMINI; OSHW-LOGO-MINI
Q1, Q2, Q3, Q4, Q5, Q6, Q7, Q8, Q9, Q10, Q11, Q12, Q13, Q14, Q15, Q16, Q17, Q18, Q19, Q20, Q21, Q22, Q23, Q24, Q25, Q26, Q27, Q28, Q29, Q30, Q31, Q32, Q33, Q34, Q35, Q36, Q37, Q38, Q39, Q40, Q41, Q42, Q43, Q44, Q45, Q46, Q47, Q48, Q49, Q50, Q51, Q52, Q53, Q54, Q55, Q56, Q57, Q58, Q59, Q60: 16MHZ; RESONATOR-SMD
R1, R4, R5, R6, R8, R9, R11, R12, R14, R15, R17, R18, R20, R21, R23, R24, R26, R27, R29, R30, R32, R33, R35, R36, R38, R39, R41, R42, R44, R45, R47, R48, R50, R51, R53, R54, R56, R57, R59, R60, R62, R63, R65, R66, R68, R69, R71, R72, R74, R75, R77, R78, R80, R81, R83, R84, R86, R87, R89, R90, R92, R93, R95, R96, R98, R99, R101, R102, R104, R105, R107, R108, R110, R111, R113, R114, R116, R117, R119, R120, R122, R123, R125, R126, R128, R129, R131, R132, R134, R135, R137, R138, R140, R141, R143, R144, R146, R147, R149, R150, R152, R153, R155, R156, R158, R159, R161, R162, R164, R165, R167, R168, R170, R171, R173, R174, R176, R177, R179, R180: 1K; 0603-RES
R2, R3, R7, R10, R13, R16, R19, R22, R25, R28, R31, R34, R37, R40, R43, R46, R49, R52, R55, R58, R61, R64, R67, R70, R73, R76, R79, R82, R85, R88, R91, R94, R97, R100, R103, R106, R109, R112, R115, R118, R121, R124, R127, R130, R133, R136, R139, R142, R145, R148, R151, R154, R157, R160, R163, R166, R169, R172, R175, R178: 10K; 0603-RES
TP1, TP2, TP3, TP4, TP5, TP6, TP7, TP8, TP9, TP10, TP11, TP12, TP13, TP14, TP15, TP16, TP17, TP18, TP19, TP20, TP21, TP22, TP23, TP24, TP25, TP26, TP27, TP28, TP29, TP30, TP31, TP32, TP33, TP34, TP35, TP36, TP37, TP38, TP39, TP40, TP41, TP42, TP43, TP44, TP45, TP46, TP47, TP48, TP49, TP50, TP51, TP52, TP53, TP54, TP55, TP56, TP57, TP58, TP59, TP60, TP61, TP62, TP63, TP64, TP65, TP66, TP67, TP68, TP69, TP70, TP71, TP72, TP73, TP74, TP75, TP76, TP77, TP78, TP79, TP80, TP81, TP82, TP83, TP84, TP85, TP86, TP87, TP88, TP89, TP90, TP91, TP92, TP93, TP94, TP95, TP96, TP97, TP98, TP99, TP100, TP101, TP102, TP103, TP104, TP105, TP106, TP107, TP108, TP109, TP110, TP111, TP112, TP113, TP114, TP115, TP116, TP117, TP118, TP119, TP120, TP121, TP122, TP123, TP124, TP125, TP126, TP127, TP128, TP129, TP130, TP131, TP132, TP133, TP134, TP135, TP136, TP137, TP138, TP139, TP140, TP141, TP142, TP143, TP144, TP145, TP146, TP147, TP148, TP149, TP150, TP151, TP152, TP153, TP154, TP155, TP156, TP157, TP158, TP159, TP160, TP161, TP162, TP163, TP164, TP165, TP166, TP167, TP168, TP169, TP170, TP171, TP172, TP173, TP174, TP175, TP176, TP177, TP178, TP179, TP180, TP181, TP182, TP183, TP184, TP185, TP186, TP187, TP188, TP189, TP190, TP191, TP192, TP193, TP194, TP195, TP196, TP197, TP198, TP199, TP200, TP201, TP202, TP203, TP204, TP205, TP206, TP207, TP208, TP209, TP210, TP211, TP212, TP213, TP214, TP215, TP216, TP217, TP218, TP219, TP220, TP221, TP222, TP223, TP224, TP225, TP226, TP227, TP228, TP229, TP230, TP231, TP232, TP233, TP234, TP235, TP236, TP237, TP238, TP239, TP240, TP241, TP242, TP243, TP244, TP245, TP246, TP247, TP248, TP249, TP250, TP251, TP252, TP253, TP254, TP255, TP256, TP257, TP258, TP259, TP260, TP261, TP262, TP263, TP264, TP265, TP266, TP267, TP268, TP269, TP270, TP271, TP272, TP273, TP274, TP275, TP276, TP277, TP278, TP279, TP280, TP281, TP282, TP283, TP284, TP285, TP286, TP287, TP288, TP289, TP290, TP291, TP292, TP293, TP294, TP295, TP296, TP297, TP298, TP299, TP300: TEST-POINT3; PAD.03X.03
U1, U6, U9, U12, U15, U18, U21, U24, U27, U30, U33, U36, U39, U42, U45, U48, U51, U54, U57, U60, U63, U66, U69, U72, U75, U78, U81, U84, U87, U90, U93, U96, U99, U102, U105, U108, U111, U114, U117, U120, U123, U126, U129, U132, U135, U138, U141, U144, U147, U150, U153, U156, U159, U162, U165, U168, U171, U174, U177, U180: ATMEGA328P_TQFP; TQFP32-08
U2, U4, U7, U10, U13, U16, U19, U22, U25, U28, U31, U34, U37, U40, U43, U46, U49, U52, U55, U58, U61, U64, U67, U70, U73, U76, U79, U82, U85, U88, U91, U94, U97, U100, U103, U106, U109, U112, U115, U118, U121, U124, U127, U130, U133, U136, U139, U142, U145, U148, U151, U154, U157, U160, U163, U166, U169, U172, U175, U178: 3.3V MIC5205; SOT23-5
U3, U5, U8, U11, U14, U17, U20, U23, U26, U29, U32, U35, U38, U41, U44, U47, U50, U53, U56, U59, U62, U65, U68, U71, U74, U77, U80, U83, U86, U89, U92, U95, U98, U101, U104, U107, U110, U113, U116, U119, U122, U125, U128, U131, U134, U137, U140, U143, U146, U149, U152, U155, U158, U161, U164, U167, U170, U173, U176, U179: microSD Socket; MICROSD_1:1

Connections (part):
3.3V: C1.A, C3.2, C4.1, R2.2, TP1.P$1, U1.4, U1.6, U1.18, U1.20, U2.5, U3.4
3.3V1: C5.1, C6.2, C8.A, R3.2, TP6.P$1, U4.5, U5.4, U6.4, U6.6, U6.18, U6.20
3.3V2: C9.1, C10.2, C12.A, R7.2, TP11.P$1, U7.5, U8.4, U9.4, U9.6, U9.18, U9.20
3.3V3: C13.1, C14.2, C16.A, R10.2, TP16.P$1, U10.5, U11.4, U12.4, U12.6, U12.18, U12.20
3.3V4: C17.1, C18.2, C20.A, R13.2, TP21.P$1, U13.5, U14.4, U15.4, U15.6, U15.18, U15.20
3.3V5: C21.1, C22.2, C24.A, R16.2, TP26.P$1, U16.5, U17.4, U18.4, U18.6, U18.18, U18.20
3.3V6: C25.1, C26.2, C28.A, R19.2, TP31.P$1, U19.5, U20.4, U21.4, U21.6, U21.18, U21.20
3.3V7: C29.1, C30.2, C32.A, R22.2, TP36.P$1, U22.5, U23.4, U24.4, U24.6, U24.18, U24.20
3.3V8: C33.1, C34.2, C36.A, R25.2, TP41.P$1, U25.5, U26.4, U27.4, U27.6, U27.18, U27.20
3.3V9: C37.1, C38.2, C40.A, R28.2, TP46.P$1, U28.5, U29.4, U30.4, U30.6, U30.18, U30.20
3.3V10: C41.1, C42.2, C44.A, R31.2, TP51.P$1, U31.5, U32.4, U33.4, U33.6, U33.18, U33.20
3.3V11: C45.1, C46.2, C48.A, R34.2, TP56.P$1, U34.5, U35.4, U36.4, U36.6, U36.18, U36.20
3.3V12: C49.1, C50.2, C52.A, R37.2, TP61.P$1, U37.5, U38.4, U39.4, U39.6, U39.18, U39.20
3.3V13: C53.1, C54.2, C56.A, R40.2, TP66.P$1, U40.5, U41.4, U42.4, U42.6, U42.18, U42.20
3.3V14: C57.1, C58.2, C60.A, R43.2, TP71.P$1, U43.5, U44.4, U45.4, U45.6, U45.18, U45.20
3.3V15: C61.1, C62.2, C64.A, R46.2, TP76.P$1, U46.5, U47.4, U48.4, U48.6, U48.18, U48.20
3.3V16: C65.1, C66.2, C68.A, R49.2, TP81.P$1, U49.5, U50.4, U51.4, U51.6, U51.18, U51.20
3.3V17: C69.1, C70.2, C72.A, R52.2, TP86.P$1, U52.5, U53.4, U54.4, U54.6, U54.18, U54.20
3.3V18: C73.1, C74.2, C76.A, R55.2, TP91.P$1, U55.5, U56.4, U57.4, U57.6, U57.18, U57.20
3.3V19: C77.1, C78.2, C80.A, R58.2, TP96.P$1, U58.5, U59.4, U60.4, U60.6, U60.18, U60.20
3.3V20: C81.1, C82.2, C84.A, R61.2, TP101.P$1, U61.5, U62.4, U63.4, U63.6, U63.18, U63.20
3.3V21: C85.1, C86.2, C88.A, R64.2, TP106.P$1, U64.5, U65.4, U66.4, U66.6, U66.18, U66.20
3.3V22: C89.1, C90.2, C92.A, R67.2, TP111.P$1, U67.5, U68.4, U69.4, U69.6, U69.18, U69.20
3.3V23: C93.1, C94.2, C96.A, R70.2, TP116.P$1, U70.5, U71.4, U72.4, U72.6, U72.18, U72.20
3.3V24: C97.1, C98.2, C100.A, R73.2, TP121.P$1, U73.5, U74.4, U75.4, U75.6, U75.18, U75.20
3.3V25: C101.1, C102.2, C104.A, R76.2, TP126.P$1, U76.5, U77.4, U78.4, U78.6, U78.18, U78.20
3.3V26: C105.1, C106.2, C108.A, R79.2, TP131.P$1, U79.5, U80.4, U81.4, U81.6, U81.18, U81.20
3.3V27: C109.1, C110.2, C112.A, R82.2, TP136.P$1, U82.5, U83.4, U84.4, U84.6, U84.18, U84.20
3.3V28: C113.1, C114.2, C116.A, R85.2, TP141.P$1, U85.5, U86.4, U87.4, U87.6, U87.18, U87.20
3.3V29: C117.1, C118.2, C120.A, R88.2, TP146.P$1, U88.5, U89.4, U90.4, U90.6, U90.18, U90.20
3.3V30: C121.1, C122.2, C124.A, R91.2, TP151.P$1, U91.5, U92.4, U93.4, U93.6, U93.18, U93.20
3.3V31: C125.1, C126.2, C128.A, R94.2, TP156.P$1, U94.5, U95.4, U96.4, U96.6, U96.18, U96.20
3.3V32: C129.1, C130.2, C132.A, R97.2, TP161.P$1, U97.5, U98.4, U99.4, U99.6, U99.18, U99.20
3.3V33: C133.1, C134.2, C136.A, R100.2, TP166.P$1, U100.5, U101.4, U102.4, U102.6, U102.18, U102.20
3.3V34: C137.1, C138.2, C140.A, R103.2, TP171.P$1, U103.5, U104.4, U105.4, U105.6, U105.18, U105.20
3.3V35: C141.1, C142.2, C144.A, R106.2, TP176.P$1, U106.5, U107.4, U108.4, U108.6, U108.18, U108.20
3.3V36: C145.1, C146.2, C148.A, R109.2, TP181.P$1, U109.5, U110.4, U111.4, U111.6, U111.18, U111.20
3.3V37: C149.1, C150.2, C152.A, R112.2, TP186.P$1, U112.5, U113.4, U114.4, U114.6, U114.18, U114.20
3.3V38: C153.1, C154.2, C156.A, R115.2, TP191.P$1, U115.5, U116.4, U117.4, U117.6, U117.18, U117.20
3.3V39: C157.1, C158.2, C160.A, R118.2, TP196.P$1, U118.5, U119.4, U120.4, U120.6, U120.18, U120.20
3.3V40: C161.1, C162.2, C164.A, R121.2, TP201.P$1, U121.5, U122.4, U123.4, U123.6, U123.18, U123.20
3.3V41: C165.1, C166.2, C168.A, R124.2, TP206.P$1, U124.5, U125.4, U126.4, U126.6, U126.18, U126.20
3.3V42: C169.1, C170.2, C172.A, R127.2, TP211.P$1, U127.5, U128.4, U129.4, U129.6, U129.18, U129.20
3.3V43: C173.1, C174.2, C176.A, R130.2, TP216.P$1, U130.5, U131.4, U132.4, U132.6, U132.18, U132.20
3.3V44: C177.1, C178.2, C180.A, R133.2, TP221.P$1, U133.5, U134.4, U135.4, U135.6, U135.18, U135.20
3.3V45: C181.1, C182.2, C184.A, R136.2, TP226.P$1, U136.5, U137.4, U138.4, U138.6, U138.18, U138.20
3.3V46: C185.1, C186.2, C188.A, R139.2, TP231.P$1, U139.5, U140.4, U141.4, U141.6, U141.18, U141.20
3.3V47: C189.1, C190.2, C192.A, R142.2, TP236.P$1, U142.5, U143.4, U144.4, U144.6, U144.18, U144.20
3.3V48: C193.1, C194.2, C196.A, R145.2, TP241.P$1, U145.5, U146.4, U147.4, U147.6, U147.18, U147.20
3.3V49: C197.1, C198.2, C200.A, R148.2, TP246.P$1, U148.5, U149.4, U150.4, U150.6, U150.18, U150.20
3.3V50: C201.1, C202.2, C204.A, R151.2, TP251.P$1, U151.5, U152.4, U153.4, U153.6, U153.18, U153.20
3.3V51: C205.1, C206.2, C208.A, R154.2, TP256.P$1, U154.5, U155.4, U156.4, U156.6, U156.18, U156.20
3.3V52: C209.1, C210.2, C212.A, R157.2, TP261.P$1, U157.5, U158.4, U159.4, U159.6, U159.18, U159.20
3.3V53: C213.1, C214.2, C216.A, R160.2, TP266.P$1, U160.5, U161.4, U162.4, U162.6, U162.18, U162.20
3.3V54: C217.1, C218.2, C220.A, R163.2, TP271.P$1, U163.5, U164.4, U165.4, U165.6, U165.18, U165.20
3.3V55: C221.1, C222.2, C224.A, R166.2, TP276.P$1, U166.5, U167.4, U168.4, U168.6, U168.18, U168.20
3.3V56: C225.1, C226.2, C228.A, R169.2, TP281.P$1, U169.5, U170.4, U171.4, U171.6, U171.18, U171.20
3.3V57: C229.1, C230.2, C232.A, R172.2, TP286.P$1, U172.5, U173.4, U174.4, U174.6, U174.18, U174.20
3.3V58: C233.1, C234.2, C236.A, R175.2, TP291.P$1, U175.5, U176.4, U177.4, U177.6, U177.18, U177.20
3.3V59: C237.1, C238.2, C240.A, R178.2, TP296.P$1, U178.5, U179.4, U180.4, U180.6, U180.18, U180.20
CD: U1.25, U3.CD1
CD1: U5.CD1, U6.25
CD2: U8.CD1, U9.25
CD3: U11.CD1, U12.25
CD4: U14.CD1, U15.25
CD5: U17.CD1, U18.25
CD6: U20.CD1, U21.25
CD7: U23.CD1, U24.25
CD8: U26.CD1, U27.25
CD9: U29.CD1, U30.25
CD10: U32.CD1, U33.25
CD11: U35.CD1, U36.25
CD12: U38.CD1, U39.25
CD13: U41.CD1, U42.25
CD14: U44.CD1, U45.25
CD15: U47.CD1, U48.25
CD16: U50.CD1, U51.25
CD17: U53.CD1, U54.25
CD18: U56.CD1, U57.25
CD19: U59.CD1, U60.25
CD20: U62.CD1, U63.25
CD21: U65.CD1, U66.25
CD22: U68.CD1, U69.25
CD23: U71.CD1, U72.25
CD24: U74.CD1, U75.25
CD25: U77.CD1, U78.25
CD26: U80.CD1, U81.25
CD27: U83.CD1, U84.25
CD28: U86.CD1, U87.25
CD29: U89.CD1, U90.25
CD30: U92.CD1, U93.25
CD31: U95.CD1, U96.25
CD32: U98.CD1, U99.25
CD33: U101.CD1, U102.25
CD34: U104.CD1, U105.25
CD35: U107.CD1, U108.25
CD36: U110.CD1, U111.25
CD37: U113.CD1, U114.25
CD38: U116.CD1, U117.25
CD39: U119.CD1, U120.25
CD40: U122.CD1, U123.25
CD41: U125.CD1, U126.25
CD42: U128.CD1, U129.25
CD43: U131.CD1, U132.25
CD44: U134.CD1, U135.25
CD45: U137.CD1, U138.25
CD46: U140.CD1, U141.25
CD47: U143.CD1, U144.25
CD48: U146.CD1, U147.25
CD49: U149.CD1, U150.25
CD50: U152.CD1, U153.25
CD51: U155.CD1, U156.25
CD52: U158.CD1, U159.25
CD53: U161.CD1, U162.25
CD54: U164.CD1, U165.25
CD55: U167.CD1, U168.25
CD56: U170.CD1, U171.25
CD57: U173.CD1, U174.25
CD58: U176.CD1, U177.25
CD59: U179.CD1, U180.25
CS: U1.14, U3.2
CS1: U5.2, U6.14
CS2: U8.2, U9.14
CS3: U11.2, U12.14
CS4: U14.2, U15.14
CS5: U17.2, U18.14
CS6: U20.2, U21.14
CS7: U23.2, U24.14
CS8: U26.2, U27.14
CS9: U29.2, U30.14
CS10: U32.2, U33.14
CS11: U35.2, U36.14
CS12: U38.2, U39.14
CS13: U41.2, U42.14
CS14: U44.2, U45.14
CS15: U47.2, U48.14
CS16: U50.2, U51.14
CS17: U53.2, U54.14
CS18: U56.2, U57.14
CS19: U59.2, U60.14
CS20: U62.2, U63.14
CS21: U65.2, U66.14
CS22: U68.2, U69.14
CS23: U71.2, U72.14
CS24: U74.2, U75.14
CS25: U77.2, U78.14
CS26: U80.2, U81.14
CS27: U83.2, U84.14
CS28: U86.2, U87.14
CS29: U89.2, U90.14
CS30: U92.2, U93.14
CS31: U95.2, U96.14
CS32: U98.2, U99.14
CS33: U101.2, U102.14
CS34: U104.2, U105.14
CS35: U107.2, U108.14
CS36: U110.2, U111.14
CS37: U113.2, U114.14
CS38: U116.2, U117.14
CS39: U119.2, U120.14
CS40: U122.2, U123.14
CS41: U125.2, U126.14
CS42: U128.2, U129.14
CS43: U131.2, U132.14
CS44: U134.2, U135.14
CS45: U137.2, U138.14
CS46: U140.2, U141.14
CS47: U143.2, U144.14
CS48: U146.2, U147.14
CS49: U149.2, U150.14
CS50: U152.2, U153.14
CS51: U155.2, U156.14
CS52: U158.2, U159.14
CS53: U161.2, U162.14
CS54: U164.2, U165.14
CS55: U167.2, U168.14
CS56: U170.2, U171.14
CS57: U173.2, U174.14
CS58: U176.2, U177.14
CS59: U179.2, U180.14
DTR: C2.2, JP2.6
DTR1: C7.2, JP1.6
DTR2: C11.2, JP3.6
DTR3: C15.2, JP4.6
DTR4: C19.2, JP5.6
DTR5: C23.2, JP6.6
DTR6: C27.2, JP7.6
DTR7: C31.2, JP8.6
DTR8: C35.2, JP9.6
DTR9: C39.2, JP10.6
DTR10: C43.2, JP11.6
DTR11: C47.2, JP12.6
DTR12: C51.2, JP13.6
DTR13: C55.2, JP14.6
DTR14: C59.2, JP15.6
DTR15: C63.2, JP16.6
DTR16: C67.2, JP17.6
DTR17: C71.2, JP18.6
DTR18: C75.2, JP19.6
DTR19: C79.2, JP20.6
DTR20: C83.2, JP21.6
DTR21: C87.2, JP22.6
DTR22: C91.2, JP23.6
DTR23: C95.2, JP24.6
DTR24: C99.2, JP25.6
DTR25: C103.2, JP26.6
DTR26: C107.2, JP27.6
DTR27: C111.2, JP28.6
DTR28: C115.2, JP29.6
DTR29: C119.2, JP30.6
DTR30: C123.2, JP31.6
DTR31: C127.2, JP32.6
DTR32: C131.2, JP33.6
DTR33: C135.2, JP34.6
DTR34: C139.2, JP35.6
DTR35: C143.2, JP36.6
DTR36: C147.2, JP37.6
DTR37: C151.2, JP38.6
DTR38: C155.2, JP39.6
DTR39: C159.2, JP40.6
DTR40: C163.2, JP41.6
DTR41: C167.2, JP42.6
DTR42: C171.2, JP43.6
DTR43: C175.2, JP44.6
DTR44: C179.2, JP45.6
DTR45: C183.2, JP46.6
DTR46: C187.2, JP47.6
DTR47: C191.2, JP48.6
DTR48: C195.2, JP49.6
DTR49: C199.2, JP50.6
DTR50: C203.2, JP51.6
DTR51: C207.2, JP52.6
DTR52: C211.2, JP53.6
DTR53: C215.2, JP54.6
DTR54: C219.2, JP55.6
DTR55: C223.2, JP56.6
DTR56: C227.2, JP57.6
DTR57: C231.2, JP58.6
DTR58: C235.2, JP59.6
DTR59: C239.2, JP60.6
GND: C1.K, C3.1, C4.2, D1.C, D3.C, JP2.1, JP2.2, Q1.2, U1.3, U1.5, U1.21, U2.2, U3.6, U3.GND1, U3.GND3
GND1: C5.2, C6.1, C8.K, D2.C, D4.C, JP1.1, JP1.2, Q2.2, U4.2, U5.6, U5.GND1, U5.GND3, U6.3, U6.5, U6.21
GND2: C9.2, C10.1, C12.K, D5.C, D6.C, JP3.1, JP3.2, Q3.2, U7.2, U8.6, U8.GND1, U8.GND3, U9.3, U9.5, U9.21
GND3: C13.2, C14.1, C16.K, D7.C, D8.C, JP4.1, JP4.2, Q4.2, U10.2, U11.6, U11.GND1, U11.GND3, U12.3, U12.5, U12.21
GND4: C17.2, C18.1, C20.K, D9.C, D10.C, JP5.1, JP5.2, Q5.2, U13.2, U14.6, U14.GND1, U14.GND3, U15.3, U15.5, U15.21
GND5: C21.2, C22.1, C24.K, D11.C, D12.C, JP6.1, JP6.2, Q6.2, U16.2, U17.6, U17.GND1, U17.GND3, U18.3, U18.5, U18.21
GND6: C25.2, C26.1, C28.K, D13.C, D14.C, JP7.1, JP7.2, Q7.2, U19.2, U20.6, U20.GND1, U20.GND3, U21.3, U21.5, U21.21
GND7: C29.2, C30.1, C32.K, D15.C, D16.C, JP8.1, JP8.2, Q8.2, U22.2, U23.6, U23.GND1, U23.GND3, U24.3, U24.5, U24.21
GND8: C33.2, C34.1, C36.K, D17.C, D18.C, JP9.1, JP9.2, Q9.2, U25.2, U26.6, U26.GND1, U26.GND3, U27.3, U27.5, U27.21
GND9: C37.2, C38.1, C40.K, D19.C, D20.C, JP10.1, JP10.2, Q10.2, U28.2, U29.6, U29.GND1, U29.GND3, U30.3, U30.5, U30.21
GND10: C41.2, C42.1, C44.K, D21.C, D22.C, JP11.1, JP11.2, Q11.2, U31.2, U32.6, U32.GND1, U32.GND3, U33.3, U33.5, U33.21
GND11: C45.2, C46.1, C48.K, D23.C, D24.C, JP12.1, JP12.2, Q12.2, U34.2, U35.6, U35.GND1, U35.GND3, U36.3, U36.5, U36.21
GND12: C49.2, C50.1, C52.K, D25.C, D26.C, JP13.1, JP13.2, Q13.2, U37.2, U38.6, U38.GND1, U38.GND3, U39.3, U39.5, U39.21
GND13: C53.2, C54.1, C56.K, D27.C, D28.C, JP14.1, JP14.2, Q14.2, U40.2, U41.6, U41.GND1, U41.GND3, U42.3, U42.5, U42.21
GND14: C57.2, C58.1, C60.K, D29.C, D30.C, JP15.1, JP15.2, Q15.2, U43.2, U44.6, U44.GND1, U44.GND3, U45.3, U45.5, U45.21
GND15: C61.2, C62.1, C64.K, D31.C, D32.C, JP16.1, JP16.2, Q16.2, U46.2, U47.6, U47.GND1, U47.GND3, U48.3, U48.5, U48.21
GND16: C65.2, C66.1, C68.K, D33.C, D34.C, JP17.1, JP17.2, Q17.2, U49.2, U50.6, U50.GND1, U50.GND3, U51.3, U51.5, U51.21
GND17: C69.2, C70.1, C72.K, D35.C, D36.C, JP18.1, JP18.2, Q18.2, U52.2, U53.6, U53.GND1, U53.GND3, U54.3, U54.5, U54.21
GND18: C73.2, C74.1, C76.K, D37.C, D38.C, JP19.1, JP19.2, Q19.2, U55.2, U56.6, U56.GND1, U56.GND3, U57.3, U57.5, U57.21
GND19: C77.2, C78.1, C80.K, D39.C, D40.C, JP20.1, JP20.2, Q20.2, U58.2, U59.6, U59.GND1, U59.GND3, U60.3, U60.5, U60.21
GND20: C81.2, C82.1, C84.K, D41.C, D42.C, JP21.1, JP21.2, Q21.2, U61.2, U62.6, U62.GND1, U62.GND3, U63.3, U63.5, U63.21
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

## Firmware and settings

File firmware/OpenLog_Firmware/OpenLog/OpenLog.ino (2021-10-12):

/*
  12-3-09
  Nathan Seidle
  SparkFun Electronics

  OpenLog hardware and firmware are released under the Creative Commons Share Alike v3.0 license.
  http://creativecommons.org/licenses/by-sa/3.0/
  Feel free to use, distribute, and sell varients of OpenLog. All we ask is that you include attribution of 'Based on OpenLog by SparkFun'.

  OpenLog is based on the work of Bill Greiman and sdfatlib. Currently SDFat v1.1.4: https://github.com/greiman/SdFat/releases/tag/1.1.4
  SerialPort is the work of Bill Greiman and is used to increase the size of the RX buffer: https://github.com/greiman/SerialPort

  OpenLog is a simple serial logger based on the ATmega328 running at 16MHz. The whole purpose of this
  logger was to create a logger that just powered up and worked. OpenLog ships with an Arduino/Optiboot
  115200bps serial bootloader running at 16MHz so you can load new firmware with a simple serial
  connection.

  OpenLog has progressed significantly over the past three years. Please see CHANGELOG.md or GitHub commits
  for a full trip down memory lane.

  OpenLog automatically works with 512MB to 64GB micro/SD cards.

  OpenLog runs at 9600bps by default. This is configurable to 1200, 2400, 4800, 9600, 19200, 38400, 57600, and 115200bps. You can alter
  all settings including baud rate and escape characters by editing config.txt found on OpenLog.

  Type '?' to get a list of supported commands.

  During power up, you will see '12<'. '1' indicates the serial connection is established. '2' indicates
  the SD card has been successfully initialized. '<' indicates OpenLog is ready to receive serial characters.

  Recording constant 115200bps datastreams are supported. Throw it everything you've got! To acheive this maximum record rate, please use the
  SD card formatter from : http://www.sdcard.org/consumers/formatter/. The fewer files on the card, the faster OpenLog is able to begin logging.
  200 files is ok. 2GB worth of music and pictures is not.

  To a lower dir, use 'cd ..' instead of 'cd..'.

  Only standard 8.3 file names are supported. "12345678.123" is acceptable. "123456789.123" is not.

  All file names are pushed to upper case. "NewLog.txt" will become "NEWLOG.TXT".

  Type 'set' to enter baud rate configuration menu. Select the baud rate and press enter. You will then
  see a message 'Going to 9600bps...' or some such message. You will need to power down OpenLog, change
  your system UART settings to match the new OpenLog baud rate and then power OpenLog back up.

  If you get OpenLog stuck into an unknown baudrate, there is a safety mechanism built-in. Tie the RX pin
  to ground and power up OpenLog. You should see the LEDs blink back and forth for 2 seconds, then blink
  in unison. Now power down OpenLog and remove the RX/GND jumper. OpenLog is now reset to 9600bps.

  Please note: The preloaded Optiboot serial bootloader is 0.5k, and begins at 0x7E00 (32,256). If the code is
  larger than 32,256 bytes, you will get verification errors during serial bootloading.

  OpenLog regularly shuts down to conserve power. If after 0.5 seconds no characters are received, OpenLog will record
  any unsaved characters and go to sleep. OpenLog will automatically wake up and continue logging the instant a
  new character is received.

  1.55mA idle
  15mA actively writing

  Input voltage on VCC can be 3.3 to 12V. Input voltage on RX-I pin must not exceed 6V. Output voltage on
  TX-O pin will not be greater than 3.3V. This may cause problems with some systems - for example if your
  attached microcontroller requires 4V minimum for serial communication (this is rare).

*/

#define __PROG_TYPES_COMPAT__ //Needed to get SerialPort.h to work in Arduino 1.6.x

#include <SPI.h>
#include <SdFat.h> //We do not use the built-in SD.h file because it calls Serial.print
#include <SerialPort.h> //This is a new/beta library written by Bill Greiman. You rock Bill! https://github.com/greiman/SerialPort
#include <EEPROM.h>
#include <FreeStack.h> //Allows us to print the available stack/RAM size

SerialPort<0, 512, 0> NewSerial;
//<port #, RX buffer size, TX buffer size>
//We set the TX buffer to zero because we will be spending most of our
//time needing to buffer the incoming (RX) characters.

//This is the array within the append file routine
//We have to keep SerialPort buffer sizes reasonable so that when we drop to
//the command shell we have RAM available for the various commands like append
#define LOCAL_BUFF_SIZE 255 //Must not be larger than charsToRecord variable size which is currently a byte
//512/256 shell works, 5/5 logs passed
//800/128 shell works, 3/5 logs passed
//672/256 shell works, 2/5 logs passed
//722/256 shell fails
//850/128 shell fails

#include <avr/sleep.h> //Needed for sleep_mode
#include <avr/power.h> //Needed for powering down perihperals such as the ADC/TWI and Timers

#define SD_CHIP_SELECT 10 //On OpenLog this is pin 10

//Debug turns on (1) or off (0) a bunch of verbose debug statements. Normally use (0)
//#define DEBUG  1
#define DEBUG  0

void(* Reset_AVR) (void) = 0; //Way of resetting the ATmega

#define CFG_FILENAME "config.txt\0" //This is the name of the file that contains the unit settings

#define MAX_CFG "115200,255,255,1,1,1,1,255,255\0" // This is used to calculate the longest possible configuration string. These actual values are not used
#define CFG_LENGTH (strlen(MAX_CFG) + 1) //Length of text found in config file. strlen ignores \0 so we have to add it back 
#define SEQ_FILENAME "SEQLOG00.TXT\0" //This is the name for the file when you're in sequential mode

//Internal EEPROM locations for the user settings
#define LOCATION_SYSTEM_SETTING		  0x02
#define LOCATION_FILE_NUMBER_LSB	  0x03
#define LOCATION_FILE_NUMBER_MSB	  0x04
#define LOCATION_ESCAPE_CHAR		    0x05
#define LOCATION_MAX_ESCAPE_CHAR	  0x06
#define LOCATION_VERBOSE            0x07
#define LOCATION_ECHO               0x08
#define LOCATION_BAUD_SETTING_HIGH	0x09
#define LOCATION_BAUD_SETTING_MID	  0x0A
#define LOCATION_BAUD_SETTING_LOW	  0x0B
#define LOCATION_IGNORE_RX		      0x0C
#define LOCATION_MAX_FILESIZE_MB    0x0D    // In MODE_ROTATE, this is the maximum size (in MB) that a file is allowed to grow to before starting a new file
#define LOCATION_MAX_FILENUMBER     0x0E    // In MODE_ROTATE, this is the highest allowed value of newFileNumer in NeLog() before wrapping around to zero

#define BAUD_MIN  300
#define BAUD_MAX  1000000

#define MODE_NEWLOG	    0
#define MODE_SEQLOG     1
#define MODE_COMMAND    2
#define MODE_ROTATE     3                 // Like NEWLOG, but fills a fixed set of files (settable from config) then starts overwriting oldest ones
#define MODE_MAX_VALID_MODE MODE_ROTATE   // If adding a new mode, set this to the last good mode number

const byte stat1 = 5;  //This is the normal status LED
const byte stat2 = 13; //This is the SPI LED, indicating SD traffic

//Blinking LED error codes
#define ERROR_SD_INIT	    3
#define ERROR_NEW_BAUD	  5
#define ERROR_CARD_INIT   6
#define ERROR_VOLUME_INIT 7
#define ERROR_ROOT_INIT   8
#define ERROR_FILE_OPEN   9

#if !DEBUG
// Using OpenLog in an embedded environment only if not in debug mode. The reason for this
// is that we are out of space if the simple embedded is included
#define INCLUDE_SIMPLE_EMBEDDED
#endif

#ifdef INCLUDE_SIMPLE_EMBEDDED
#define EMBEDDED_END_MARKER  0x08
#endif

//These are bit locations used when testing for simple embedded commands.
#define ECHO			      0x01
#define EXTENDED_INFO		0x02
#define OFF  0x00
#define ON   0x01

SdFat sd;

long setting_uart_speed; //This is the baud rate that the system runs at, default is 9600. Can be 1,200 to 1,000,000
byte setting_systemMode; //This is the mode the system runs in, default is MODE_NEWLOG
byte setting_escape_character; //This is the ASCII character we look for to break logging, default is ctrl+z
byte setting_max_escape_character; //Number of escape chars before break logging, default is 3
byte setting_verbose; //This controls the whether we get extended or simple responses.
byte setting_echo; //This turns on/off echoing at the command prompt
byte setting_ignore_RX; //This flag, when set to 1 will make OpenLog ignore the state of the RX pin when powering up
byte setting_max_filesize_MB; // In MODE_ROTATE, the maximum number of MB that a file is allowed to grow to
byte setting_max_filenumber;  // In MODE_ROTATE, the maximum file number before wrapping around to 0

//The number of command line arguments
//Increase to support more arguments but be aware of the memory restrictions
//command <arg1> <arg2> <arg3> <arg4> <arg5>
#define MAX_COUNT_COMMAND_LINE_ARGS 5

//Used for wild card delete and search
struct commandArg
{
  char* arg; //Points to first character in command line argument
  byte arg_length; //Length of command line argument
};
static struct commandArg cmd_arg[MAX_COUNT_COMMAND_LINE_ARGS];

byte feedbackMode = (ECHO | EXTENDED_INFO);

//Handle errors by printing the error type and blinking LEDs in certain way
//The function will never exit - it loops forever inside blinkError
void systemError(byte errorType)
{
  NewSerial.print(F("Error "));
  switch (errorType)
  {
    case ERROR_CARD_INIT:
      NewSerial.print(F("card.init"));
      blinkError(ERROR_SD_INIT);
      break;
    case ERROR_VOLUME_INIT:
      NewSerial.print(F("volume.init"));
      blinkError(ERROR_SD_INIT);
      break;
    case ERROR_ROOT_INIT:
      NewSerial.print(F("root.init"));
      blinkError(ERROR_SD_INIT);
      break;
    case ERROR_FILE_OPEN:
      NewSerial.print(F("file.open"));
      blinkError(ERROR_SD_INIT);
      break;
  }
}

void setup(void)
{
  pinMode(stat1, OUTPUT);

  //Power down various bits of hardware to lower power usage
  set_sleep_mode(SLEEP_MODE_IDLE);
  sleep_enable();

  //Shut off TWI, Timer2, Timer1, ADC
  ADCSRA &= ~(1 << ADEN); //Disable ADC
  ACSR = (1 << ACD); //Disable the analog comparator
  DIDR0 = 0x3F; //Disable digital input buffers on all ADC0-ADC5 pins
  DIDR1 = (1 << AIN1D) | (1 << AIN0D); //Disable digital input buffer on AIN1/0

  power_twi_disable();
  power_timer1_disable();
  power_timer2_disable();
  power_adc_disable();

  readSystemSettings(); //Load all system settings from EEPROM

  //Setup UART
  NewSerial.begin(setting_uart_speed);
  if (setting_uart_speed < 500)      // check for slow baud rates
  {
    //There is an error in the Serial library for lower than 500bps.
    //This fixes it. See issue 163: https://github.com/sparkfun/OpenLog/issues/163
    // redo USART baud rate configuration
    UBRR0 = (F_CPU / (16UL * setting_uart_speed)) - 1;
    UCSR0A &= ~_BV(U2X0);
  }
  NewSerial.print(F("1"));

#if DEBUG
  NewSerial.print(F("MaxFilesize from EEPROM: "));
  NewSerial.println(setting_max_filesize_MB);
  NewSerial.print(F("MaxFilenumber from EEPROM: "));
  NewSerial.println(setting_max_filenumber);
#endif

  //Setup SD & FAT
  if (!sd.begin(SD_CHIP_SELECT, SPI_FULL_SPEED)) systemError(ERROR_CARD_INIT);
  if (!sd.chdir()) systemError(ERROR_ROOT_INIT); //Change to root directory. All new file creation will be in root.

  NewSerial.print(F("2"));

  //Search for a config file and load any settings found. This will over-ride previous EEPROM settings if found.
  readConfigFile();

  if (setting_ignore_RX == OFF) //If we are NOT ignoring RX, then
    checkEmergencyReset(); //Look to see if the RX pin is being pulled low

#if DEBUG
  NewSerial.print(F("FreeStack: "));
  NewSerial.println(FreeStack());
#endif

}

void loop(void)
{
  //If we are in new log mode, find a new file name to write to
  if (setting_systemMode == MODE_NEWLOG || setting_systemMode == MODE_ROTATE)
  {
    //If in MODE_NEWLOG, then just append the file name that newLog() returns and ignore return value of appendFile()
    //If in MODE_ROTATE, then as long as appendFile() keeps returning 0 (meaning the file is full and a new one
    //  needs to be started) keep creating new files and logging new data. If appendFile() returns a 1 then the escape
    //  sequence has been triggered so drop out of this while() loop and let commandShell() run.
    while ((appendFile(newLog()) == 0) && (setting_systemMode == MODE_ROTATE))
    { } // While loop purposely empty
  }

  //If we are in sequential log mode, determine if seqLog.txt has been created or not, and then open it for logging
  if (setting_systemMode == MODE_SEQLOG)
    seqLog();

  //Once either one of these modes exits, go to normal command mode, which is called by returning to loop()
  commandShell();
}

//Log to a new file everytime the system boots
//Checks the spots in EEPROM for the next available LOG# file name
//Updates EEPROM and then appends to the new log file.
//In MODE_NEWLOG and MODE_SEQLOG, limited to 65535 files but this should not always be the case.
//In MODE_ROTATE maximum number is limited to setting_max_filenumber before wrapping around to 0
char* newLog(void)
{
  byte msb, lsb;
  unsigned int newFileNumber;

  SdFile newFile; //This will contain the file for SD writing

  //Combine two 8-bit EEPROM spots into one 16-bit number
  lsb = EEPROM.read(LOCATION_FILE_NUMBER_LSB);
  msb = EEPROM.read(LOCATION_FILE_NUMBER_MSB);

  newFileNumber = msb;
  newFileNumber = newFileNumber << 8;
  newFileNumber |= lsb;

  //If both EEPROM spots are 255 (0xFF), that means they are un-initialized (first time OpenLog has been turned on)
  //Let's init them both to 0
  if ((lsb == 255) && (msb == 255))
  {
    newFileNumber = 0; //By default, unit will start at file number zero
    EEPROM.write(LOCATION_FILE_NUMBER_LSB, 0x00);
    EEPROM.write(LOCATION_FILE_NUMBER_MSB, 0x00);
  }

  //The above code looks like it will forever loop if we ever create 65535 logs
  //Let's quit if we ever get to 65534
  //65534 logs is quite possible if you have a system with lots of power on/off cycles
  if (newFileNumber == 65534)
  {
    //Gracefully drop out to command prompt with some error
    NewSerial.print(F("!Too many logs:1!"));
    return (0); //Bail!
  }

  // For MODE_ROTATE, we want to loop back around to filenmber 0 if we've gone beyond what our maximum is
  if ((setting_systemMode == MODE_ROTATE) && (newFileNumber > setting_max_filenumber))
  {
    newFileNumber = 0;
  }

  //If we made it this far, everything looks good - let's start testing to see if our file number is the next available
#if DEBUG
  NewSerial.print(F("Found file number: "));
  NewSerial.println(newFileNumber);
#endif

  //There is a weird EEPROM power-up glitch that causes the newFileNumber to advance
  //arbitrarily. This fixes that problem.
  /// TODO: (BPS) I don't understand why this is here. Your file number is then always one less than what's in EEPROM, which doesn't make sense.
  /// I'm commenting this out so that we always use the actual filenumber stored in EEPROM
  //  if (newFileNumber > 0) newFileNumber--;

  static char newFileName[13]; //Bug fix from ystark's pull request: https://github.com/sparkfun/OpenLog/pull/189

  // When in MODE_ROTATE, we don't care if the file exists, or if it is empty, or anything. We will always
  // blindly create whatever the next filename is and use it.
  if (setting_systemMode == MODE_ROTATE)
  {
    sprintf_P(newFileName, PSTR("LOG%05u.TXT"), newFileNumber); //Splice the new file number into this file name
  }
  else
  {
    // For all other modes, search for next available log spot
    while (1)
    {
      sprintf_P(newFileName, PSTR("LOG%05u.TXT"), newFileNumber); //Splice the new file number into this file name

      // O_CREAT - create the file if it does not exist
      // O_APPEND - seek to the end of the file prior to each write
      // O_WRITE - open for write
      // O_EXCL - if O_CREAT and O_EXCEL are set, open() shall fail if file exists

      //Try to open file, if it opens (file doesn't exist), then break
      if (newFile.open(newFileName, O_CREAT | O_EXCL | O_WRITE)) break;

      //Try to open file and see if it is empty. If so, use it.
      if (newFile.open(newFileName, O_READ))
      {
        if (newFile.fileSize() == 0)
        {
          newFile.close();        // Close this existing file we just opened.
          return (newFileName); // Use existing empty file.
        }
        newFile.close(); // Close this existing file we just opened.
      }

      //Try the next number
      newFileNumber++;
      if (newFileNumber > 65533) //There is a max of 65534 logs
      {
        NewSerial.print(F("!Too many logs:2!"));
        return (0); //Bail!
      }
    }
    newFile.close(); //Close this new file we just opened
  }

  newFileNumber++; //Increment so the next power up uses the next file #

  //Record new_file number to EEPROM
  lsb = (byte)(newFileNumber & 0x00FF);
  msb = (byte)((newFileNumber & 0xFF00) >> 8);

  EEPROM.write(LOCATION_FILE_NUMBER_LSB, lsb); // LSB

  if (EEPROM.read(LOCATION_FILE_NUMBER_MSB) != msb)
    EEPROM.write(LOCATION_FILE_NUMBER_MSB, msb); // MSB

#if DEBUG
  NewSerial.print(F("Stored file number: "));
  NewSerial.println(newFileNumber);

  NewSerial.print(F("Created new file: "));
  NewSerial.println(newFileName);
#endif

  return (newFileName);
}

//Log to the same file every time the system boots, sequentially
//Checks to see if the file SEQLOG.txt is available
//If not, create it
//If yes, append to it
//Return 0 on error
//Return anything else on success
void seqLog(void)
{
  SdFile seqFile;

  char sequentialFileName[strlen(SEQ_FILENAME) + 1]; //Limited to 8.3
  strcpy_P(sequentialFileName, PSTR(SEQ_FILENAME)); //This is the name of the config file. 'config.sys' is probably a bad idea.

  //Try to create sequential file
  if (!seqFile.open(sequentialFileName, O_CREAT | O_WRITE))
  {
    NewSerial.println(F("Error creating SEQLOG"));
    return;
  }

  seqFile.close(); //Close this new file we just opened

  appendFile(sequentialFileName);
}

//This is the most important function of the device. These loops have been tweaked as much as possible.
//Modifying this loop may negatively affect how well the device can record at high baud rates.
//Appends a stream of serial data to a given file
//Does not exit until escape character is received the correct number of times, or if the systemMode is MODE_ROTATE
//  and the current file has gotten too big. Then the file is closed and this function returns.
//Returns 0 if SysteMode is MODE_ROTATE and enough bytes have been written to the file so the file is now closed
//Returns 1 if the excape sequence has been detected
byte appendFile(char* fileName)
{
  SdFile workingFile;
  unsigned long totalBytesWritten = 0;  // Keeps track of the total number of bytes written to the file for MODE_ROTATE
  unsigned long maxFilesizeBytes = ((unsigned long)setting_max_filesize_MB * (unsigned long)(1048576)); // Cache this for laster

#if DEBUG
  NewSerial.print(F("setting_max_filesize_MB: "));
  NewSerial.println(setting_max_filesize_MB);
  NewSerial.print(F("maxFileSizeBytes: "));
  NewSerial.println(maxFilesizeBytes);
#endif

  if (setting_systemMode != MODE_ROTATE)
  {
    // O_CREAT - create the file if it does not exist
    // O_APPEND - seek to the end of the file prior to each write
    // O_WRITE - open for write
    if (!workingFile.open(fileName, O_CREAT | O_APPEND | O_WRITE)) systemError(ERROR_FILE_OPEN);
  }
  else
  {
    // O_CREAT - create the file if it does not exist
    // O_TRUNC - truncate the file to zero length
    // O_WRITE - open for write
    if (!workingFile.open(fileName, O_CREAT | O_TRUNC | O_WRITE)) systemError(ERROR_FILE_OPEN);
  }

  if (workingFile.fileSize() == 0) {
    //This is a trick to make sure first cluster is allocated - found in Bill's example/beta code
    workingFile.rewind();
    workingFile.sync();
  }

  //This is the 2nd buffer. It pulls from the larger Serial buffer as quickly as possible.
  //The built-in Arduino serial buffer is 64 bytes: https://www.arduino.cc/en/Serial/Available
  byte localBuffer[LOCAL_BUFF_SIZE];

  byte checkedSpot;
  byte escapeCharsReceived = 0;

  const unsigned int MAX_IDLE_TIME_MSEC = 500; //The number of milliseconds before unit goes to sleep
  unsigned long lastSyncTime = millis(); //Keeps track of the last time the file was synced
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

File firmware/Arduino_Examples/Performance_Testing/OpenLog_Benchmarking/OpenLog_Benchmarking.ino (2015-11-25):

/*
 11-22-2015
 SparkFun Electronics
 Nathan Seidle

 This code is public domain but you buy me a beer if you use this and we meet someday (Beerware license).

 This code sends a series of test strings to OpenLog to see if it can handle large amounts of data
 at different baud rates, file sizes, and delays between writes.

 For maximum speed the Arduino is connected to OpenLog via hardware UART during testing. All menus and control
 are transmitted over software serial. This means you'll need an external FTDI connected to pins 6/7 to be able
 to configure and control the test suite.

 Arduino TX to OpenLog RXI
 Arduino RX to OpenLog TX
 Arduino 5V to OpenLog VCC
 Arduino GND to OpenLog GND
 Arduino 8 to OpenLog GRN (aka DTR or reset)

 Arduino 6 to FTDI TX
 Arduino 7 to FTDI RX

 */

#include <SoftwareSerial.h>

byte ledPin =  13; //Status LED connected to digital pin 13
byte resetOpenLog = 8;

int settingLoops = 10;
long settingBaudRate = 115200;
int settingWriteDelay = 0; //Number of miliseconds between strings sent
int settingTestNumber = 5; //Run these settings across 5 logs, run 5 tests

float testTimeSeconds;
long testSizeCharacters;

const char testString[] = ":abcdefghijklmnopqrstuvwxyzABCDEFGHIJKLMNOPQRSTUVWXYZabcdefghijklmnopqrstuvwxyzABCDEFGHIJKLMNOPQRSTUVWXYZ-!#";

//The actual test string has a unique char in the front and a \n\r at the end
//Remove 1 for the \0 at the end of the array
int testStringSize = (sizeof(testString) - 1) + 3; 

char testFile[] = "testfile.txt";

SoftwareSerial TestSuite(6, 7); // RX, TX

void setup()
{
  pinMode(ledPin, OUTPUT);
  pinMode(resetOpenLog, OUTPUT);

  Serial.begin(settingBaudRate);

  TestSuite.begin(57600);

  //setupOpenLog(); //Resets logger and waits for the '<' I'm alive character
}

void loop()
{
  //Calc test run time based on current settings
  calcTestTime(false);

  TestSuite.println();
  TestSuite.println();
  TestSuite.println("OpenLog Benchmarking");

  TestSuite.print("Test time: ");

  if (testTimeSeconds / 60 > 1)
  {
    TestSuite.print(testTimeSeconds / 60, 2);
    TestSuite.println(" minutes");
  }
  else
  {
    TestSuite.print(testTimeSeconds, 2);
    TestSuite.println(" seconds");
  }

  TestSuite.print("Test size: ");
  TestSuite.print(testSizeCharacters);
  TestSuite.println(" characters");

  TestSuite.print("1) Baud to test at: ");
  TestSuite.println(settingBaudRate);

  TestSuite.print("2) Loops to run: ");
  TestSuite.println(settingLoops);

  TestSuite.print("3) Delay between sending each test string: ");
  TestSuite.println(settingWriteDelay);

  TestSuite.print("4) Number of tests: ");
  TestSuite.println(settingTestNumber);

  TestSuite.println("r) Run test with current settings");
  TestSuite.println("T) Test connection to OpenLog");
  TestSuite.println("e) Evaluate the test file");

  TestSuite.print(">");

  //Read command
  while (!TestSuite.available());
  char command = TestSuite.read();

  //Execute command
  if (command == '1')
  {
    baud_menu();
  }
  else if (command == '2')
  {
    loop_menu();
  }
  else if (command == '3')
  {
    delay_menu();
  }
  else if (command == '4')
  {
    numberOfTests_menu();
  }
  else if (command == 'r')
  {
    calcTestTime(true);
  
    TestSuite.print("This test will take approximately ");
  
    if (testTimeSeconds < 60)
    {
      TestSuite.print(testTimeSeconds, 2);
      TestSuite.println(" seconds");
    }
    else
    {
      TestSuite.print(testTimeSeconds / 60, 2);
      TestSuite.println(" minutes");
    }
  
    TestSuite.println();
    TestSuite.print("Are you sure?");
  
    while (!TestSuite.available());
    char incoming = TestSuite.read();
  
    if (incoming == 'y' || incoming == 'Y')
    {
      TestSuite.println();
      TestSuite.println("Beginning test...");
  
      for(int x = 0 ; x < settingTestNumber ; x++)
      {
        TestSuite.print("Running test ");
        TestSuite.print(x);
        TestSuite.print(" out of ");
        TestSuite.println(settingTestNumber);
  
        runTest(); //Each time we call this it resets OpenLog and creates new log

        delay(1000); //Give OpenLog a chance to record the remaining bits in buffer before we reset it
      }

      TestSuite.println("Test complete");
    }
    else
    {
      TestSuite.println();
      TestSuite.print(F("Bailing from test"));
    }
  }
  else if (command == 't')
  {
    if(gotoCommandMode())
      TestSuite.println("OpenLog responded!");
    else
      TestSuite.println("OpenLog failed to go into command mode.");
  }
  else if (command == 'e')
  {
    TestSuite.println("Evaluating file...");
    
    long charactersRead = readCharacterCount(testFile);

    TestSuite.print("Expected: ");
    TestSuite.println(testSizeCharacters);
    TestSuite.print("Found: ");
    TestSuite.println(charactersRead);

    long characterDelta = testSizeCharacters - charactersRead;

    TestSuite.print("Delta: ");
    TestSuite.println(characterDelta);
  }

}

void runTest()
{
  setupOpenLog(); //Resets module and waits for '<' ready character

  long startTime = millis();

  //Each test is 100 lines. 10 tests is 1000 lines (11,000 characters)
  for (int numofTests = 0 ; numofTests < settingLoops ; numofTests++)
  {
    //This loop will print 100 lines of 110 characters each
    for (int k = 33; k < 43 ; k++)
    {
      //Print one line of 110 characters with marker in the front (markers go from '!' to '*')
      Serial.write(k); //Print the ASCII value directly: ! then " then #, etc
      Serial.println(testString);

      if (settingWriteDelay > 0) delay(settingWriteDelay); //There is a small amount of time to do the if test

      //Then print 9 lines of 110 characters with new line at the end of the line
      for (int i = 1 ; i < 10 ; i++)
      {
        Serial.print(i, DEC);
        Serial.println(testString);

        if (settingWriteDelay > 0) delay(settingWriteDelay); //There is a small amount of time to do the if test
      }

      if (digitalRead(ledPin) == 0) //Turn the status LED on/off as we go
        digitalWrite(ledPin, HIGH);
      else
        digitalWrite(ledPin, LOW);
    }
  } //End numofTests loop

  unsigned long totalCharacters = (long)settingLoops * 100 * testStringSize;

  TestSuite.print("Characters pushed: ");
  TestSuite.println(totalCharacters);

  TestSuite.print("Time taken (s): ");
  TestSuite.println( (millis() - startTime) / (float)1000, 3);

  digitalWrite(ledPin, LOW);
}
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

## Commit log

2009-12-24 Adding Eagle Files and some directory structure
    [OpenLog.brd, OpenLog.sch]
2010-02-18 "cat" command now writes a paritial line instead of ending junk if the file ends. Added "read" command that dumps ASCII (nonprintable as ".") Added a just over 5 second idle timeout that flushes the 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
2010-03-31 v1.4 Eliminates errors while logging at 57600bps. Added exit options to the two menus (set and baud) Also added display of current settin to two menus (Ex: "Baud currently: 57600bps")
    Added '!' infront of 'error opening'. This pops up if there is an error while trying to append to a freshly created new log (ex: LOG00548.txt is created, then errors out because it cannot append). '!' was added so that user can parse against it.
    Replicated logging errors at 57600 using 5V Arduino
    Unit would systematically glitch during logging of 111054 bytes
    Increasing buffer to 1000 characters caused URU error.
    URU: Unit Resets Unexpectedly
    To recreate URU error. Type "append ". Include the space. If you g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
2010-04-07 v1.5 Added 4800bps and 19200bps support
    Added power saving features. Current consumption at 5V is now:
    In default append mode:
    6.6/5.5mA while receiving characters (LED On/Off)
    2.1mA during idle
    In command mode: 3.2/2.1mA (LED On/Off)
    So if you're actively throwing characters at the logger, it will be ~6mA. If you send the logger characters then delay 5-10 seconds, current will be ~2.5mA. (Unit records the characters in the buffer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
2010-04-14 v1.51 check_emergency_reset, default break character is ctrl+z 3 times, example Arduino sketch
    Added function from mungewell - check_emergency_reset. This has improved testing of the RX pin. There was potential to get a false baud reset. There is still a chance but it's now much less likely.
    If OpenLog is attached to a Arduino, during bootloading of the Arduino, ctrl+z will most likely be sent to the Arduino from the computer. This character will cause OpenLog to drop to command mode - probably not what we want. So I added user selectable character (ctrl+x or '$' for example) and I added user selectable number of escape characters to look for in a row (example is 1 or 2 or 3, '$$$' is a com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
    [OpenLog_Test_Sketch.pde]
2010-04-28 v1.61 Small PCB change. Fixed version # in help menu.
    Fixed the firmware version in the help menu to v1.61.
    Updated Eagle files to Eagle v5.9. Fixed weird airwire. Changed D1 LED from Green to Blue. Will only affect new production after 4-28-10.
    Closed some tickets and wrote some more example Arduino code:
    http://forum.sparkfun.com/viewtopic.php?t=21438
    [OpenLog.brd, OpenLog.sch]
2010-06-01 Support for using OpenLog with Parallax Javelin Stamp. Simplified set of commands -that can be used with any other micro processor- to count files in a folder (efcount), get file info (efinfo), turn 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
2010-06-03 Fixed issue 30 (Character Ctrl+Z on OpenLog). Escape characters (in this case Ctrl+Z) are no longer appended to the file. Fixed some other small terminal endline problems like for example 2 newlines 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
2010-06-03 Fix for disabling the logging of escape character ASCII 26 (Ctrl+z). When appending to a file the escape character currently used will also be appended to the file. In order to avoid this problem iss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
2010-06-03 Removed unneeded #defines and fixed compiling errors when undefining INCLUDE_SIMPLE_EMBEDDED. Fixed timing problems in OpenLog.java driver. Smaller chages in OpenLogTest.java.
2010-07-28 v2.0 - 25986 bytes out of 30720 Welcome to version 2! We've moved from Roland Riegel's FAT library to Bill Greiman's sdfatlib. OpenLog now works with SD cards up to 16GB (that is the current largest 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
    Almost all the previous commands have been ported from v1 to v2. The current commands that do not work:
    cd.. - does not work. You can change to an upper directory, but you cannot navigate back down the tree.
    cat - this command was depricated. HEX printing is now done with the 'read' command. We've added a 5th argument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
    [SdFat.cpp]
2010-07-28 v2.0 - 25986 bytes out of 30720 Welcome to version 2! We've moved from Roland Riegel's FAT library to Bill Greiman's sdfatlib. OpenLog now works with SD cards up to 16GB (that is the current largest 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
    cat - this command was deprecated. HEX printing is now done with the 'read' command. We've added a 5th argument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
    [SdFat.cpp]
2010-08-04 v2.1 - Fixed issue 35. Dropping characters at 57600bps. Power save not working.
    26058 bytes out of 30720
    Fixed a bug found by Salient (Issue 35). User settings where declared at chars which allowed them to be signed. If a user went from old firmware, to v2, the safety checks would fail because the settings would be read at -1 instead of 255. Declaring user settings as byte fixed issue.
    Added "a) Clear user settings" to set menu. This allows us to completely wipe an OpenLog (user settings and config file) to see how it will respond to future firmware changes.
    Improved the file 'size' command.
    Sequential logging is tested and works.
    Receive testing: Using the Test_Sketch found on Github, I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
2010-08-18 v2.11 Tested with 16GB microSD. Fixed some general bugs. Lowered power consumption.
    Fixed issue 30. I added printing a period ('.') for non-visible ASCII characters during a 'read' command. This cleans up the output a bit. HEX printing is still available.
    Fixed issue 34. When issuing a long command such as "read log00056.txt 100 200 2" (read from spot 100 to spot 200 and print in HEX), the command shell would die at 24 spots. I increased both the general_buffer and 'buffer' in the command shell from 24 to 30. The limit is now 30 characters, so "read log00056.txt 100 20000 2" is allowed.
    Works with a 16GB microSD card! High volume test: loaded 16GB card with 5GB of data. Basic serial tests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
    [OpenLog_Test_Sketch.pde]
2010-08-18 v2.11 Tested with 16GB microSD. Fixed some general bugs. Lowered power consumption.
    26136 bytes out of 30720
    Works with a 16GB microSD card! High volume test: loaded 16GB card with 5GB of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
2010-08-25 v2.2 Modified append_file() to use a single buffer. Increased HardwareSerial.cpp buffer to 512 bytes.
    More testing at 57600. Record times look to be 2, 5, and zero milliseconds when doing a record. This means that the split buffer doesn't really make a difference? There are some records that take 150ms, 14ms, etc. At 57600bps, that's 7200 bytes/s, 138us per byte. With a 150ms pause, that's 1,086 bytes that need to be buffered while we wait... Grrr. Too many.
    I re-wrote the append_file function to use only one buffer. This allows us to more quickly pull data from the hardware serial buffer. Hardware serial buffer has to be increased manually to 512. This file (hardwareserial.cpp) is stored i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
    [OpenLog_Test_Sketch.pde]
2010-09-25 Added support for wilcard listing and removal of files. This should now work the same as in previous OpenLog versions. "cd.." now works up to a depth of 15 folders. The depth can be increase be redef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
    [SdFat.cpp]
2010-10-03 Fixed "888 88" bug when hitting backspace. Resolved ambigous "rm" command, new "rm" implementation. New commands: pwd (print working directory), echo <on>|<off>. Fixed bug when using "size", leaking 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
2010-10-27 v2.3 Migrated to v10.10.10 of sdfatlib. Moved to inline RX interrupt and buffer. Improved the ability to receive a constant stream at 57600bps.
    27334 bytes out of 30720.
    Remember - we had to completely butcher HardwareSerial.cpp so a normal Arduino installation will not work.
    C:\arduino-xxxx\hardware\arduino\cores\arduino\HardwareSerial.cpp
    I removed the receive interrupt handler from HardwareSerial.cpp so that we can deal directly with USART_RX_vect in the main code. This allows us to return to the way OpenLog used to operate - by having one buffer split in half. Once one half fills, it is recorded to SD while the other half fills up. This dramatically decreases the time spent in function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
    [OpenLog_Test_Sketch.pde]
2010-11-03 v2.4 Merged ringp updates. Commands cd, rm, ls work again! New "rm -rf" command to remove directory and its files.
    Windows 7 stores the Arduino hex file is an aweful place. Something like:
    C:\Users\Main\AppData\Local\Temp\build3390340147786739225.tmp\OpenLog_v2.cpp.hex
    Added HardwareSerial.cpp and a readme to the main trunk.
    Added OpenLog_v2.cpp.hex to the main trunk.
2010-11-03 Cherry-picking "Drivers/Parallax/..." from previous commits.
2010-11-17 v2.41 Power loss bug fixed. Adding support for 38400bps for testing with SparkFum 9DOF IMU logging.
    29124 bytes of 30720 (yikes)
    Found a bug in the append_file routine. If the unit is actively logging, file.writes are flying by quickly. But if OpenLog loses power, none of the data is recorded because there is no file.sync. Data would only get recorded if the unit went idle or if user entered escape command. This has since been fixed with two file.sync() commands.
2011-02-02 v2.5 Improved 'read' command. Added 'reset' command.
    28782 bytes of 30720 (yikes)
    Modified the read command so that we can print extended ASCII characters. The function was also failing to print any value over 127 (limited to signed 8 bits - boo). Thank you wilafau! You proposed excellent, easy fixes.
    Added raw command during print operation. This allows for non-visible and extended ASCII characters to be printed correctly, if need be.
    Issuing 'reset' command causes OpenLog to reset and re-read the config file. This is important if you want to change the config file then restart.
    Removed some of the extraneous prints from the help menu to save on space.
2011-06-01 v2.51 Improved command prompt parsing (now ignores '\n')
    We now ignore the \n character when parsing characters from the command prompt. This makes it easier to create code on a microcontroller that correctly controls OpenLog. Previously, println or sprintf commands were adding a \n to the end of the string that would confuse OpenLog. One way around this if you have previous versions is this
    sprintf(buff, "new blah.txt\r");
    Serial.print(buff); //No println, use \r in string instead
    Also - added a CommandTest sketch to demonstrate how you can control OpenLog from a microcontroller / automate the command prompt
    [OpenLog_CommandTest.pde]
2012-02-22 Updated the CommandTest code to Arudino v1.0. I had to change the Serial.print(char(26)) to Serial.write(26). Also added more comments to top of code. File is now .ino.
2012-02-22 Updated example sketches to Arduino v1.0. This required only some small changes (Serial.print to Serial.write).
2012-03-14 v3.0 Re-write of core functions. Support under Arduino v1.0. Now supports full speed 57600 and 115200bps! Lower standby power. 28354 bytes out of 32256. Update to new beta version of SerialPort lib f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
2012-03-14 v3.0 Re-write of core functions. Support under Arduino v1.0. Now supports full speed 57600 and 115200bps! Lower standby power. 28354 bytes out of 32256. Update to new beta version of SerialPort lib f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
    Unzip 'SerialPortBeta20120106.zip' and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
2012-03-23 v3.1 Fixed bug where entire log data is lost when power is lost. Added fix from issue 76: https://github.com/nseidle/OpenLog/issues/76 Added support for verbose and echo settings recorded to the conf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
2012-03-23 v3.1 Fixed bug where entire log data is lost when power is lost. Added fix from issue 76: https://github.com/nseidle/OpenLog/issues/76 Added support for verbose and echo settings recorded to the conf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
2012-03-23 v3.1 Pushing a beta version of OpenLog Light. Works decently at 115200bps but doesn't yet record in power fail situation.
2012-03-26 v3.11 Added freeMemory support for RAM testing. This was taken from: http://arduino.cc/playground/Code/AvailableMemory
2012-03-27 v3.11 Added freeMemory support for RAM testing. This was taken from: http://arduino.cc/playground/Code/AvailableMemory Also updated HEX files for v3.11 and v3 Light
2013-01-08 Changes to attempt to free up RAM.
    Added printRam/freeRam function from Jeelabs. Many more F() uses.
    new_file now exits before it calls append_file. Removed global Sf file
    in an attempt to free up RAM. Didn't really help. Removed helper line
    from the config file. We need to bring this back but I'm not sure how.
2013-01-14 Better handling of max time before sync.
    There is a case where the user could be throwing non-stop data at the
    unit. The log won't be recorded because it never goes idle. This version
    adds/makes better the check of max time for the un-recorded buffer. Also
    moved from sprintf_P to strcpy_P for known file names.
    [OpenLog_Test_Sketch.ino]
2013-01-21 Added a fix for issue 132
    Sending lots of binary, fast, causes the escape character to not
    properly get reset. Added a secondary reset of escape_chars_received to
    reset it. Works well. Also added a binary test sketch to test OpenLogs
    with binary at 115200bps.
    [OpenLog_Test_Sketch_Binary.ino]
2013-03-07 Cleaning up directory structure.
    Filing firmware and hardware into their own directories.
    [OpenLog.brd, OpenLog.sch]
2013-04-08 Re-wrote baud menu system.
    Now supports any baud rate from 300bps to 1,000,000bps and anything in
    between. This will allow you to really configure OpenLog to anything you
    need, but remember you can always hardware reset OpenLog to 9600 by
    pulling the RX line low during power up.
2013-04-08 Added ability to ignore RX.
    You can now ignore the state of RX at power up. See issue #150.
2013-04-15 Updated the .hex files to reflect v3.2 changes
    Two .hex files in this commit: One is a .hex version of the Arduino
    sketch. The other .hex file is a "combined" .hex file that contains both
    the optiboot bootloader and the v3.2 firmware.
2013-09-23 Added 'disk' checking in the read example sketch.
    Related to issue 158.
    [OpenLog_ReadExample.ino]
2013-12-14 Increased number of escape chars, log name increment and memory bug.
    The number of escape chars was increased to 0 to 254. The log name now
    increments even if there are no files and the receive buffer was
    decreased to prevent memory bugs.
    [OpenLog_Test_Sketch.ino]
2014-03-10 Updated production hex and combined hex to v33
    Also moved v321 into an "old" folder to keep around in case anyone needs
    to use that.
2014-08-04 Adding large file testing for issue 169.
    When reading back a file it seems there are 5 extra bytes read. One of
    these is the '>' that OpenLog responds with. The other four are probably
    newline and other white space chars.
    [OpenLog_ReadExample_LargeFile.ino]
2014-08-11 Re-write large file example to report without character errors.
    This example reads characters from OpenLog over the hardware serial at
    9600 and passes them out over the software serial at 14400. This is
    needed for issue 170.
    [OpenLog_ReadExample_LargeFile.ino]
2015-11-24 Now compiles under Arduino v1.6.x. A large number of changes. See CHANGELOG
    Significant changes to reduce RAM footprint. Updated to most recent
    SdFatlib-beta.
2015-11-25 Best performance at 512/256 RAM split. Fixed odd zero newlog EEPROM glitch.
    [OpenLog.ino, OpenLog_Benchmarking.ino]
2015-11-25 Returning to original dimensions
    -Scooted the outer dimensions back to original spacing.
    -Moved to "TIGHT" DRU, so all traces are 10 mil, with 10 mil spacing,
    all vias are 15 mil.
    -Had to remove OSHW logo, there's no room, also it wasn't on original
    product design.
    -bumped version to v15 in sch and brd copper
    -Moved fiducials to upper left and lower right corners, (this is not the
    norm but shouldn't be a problem)
    [OpenLog.brd, OpenLog.sch]
2015-12-01 Changed to 10uF tantalum. Added labels to bottom silk. Added TP vias.
    [OpenLog.brd, OpenLog.sch]
2015-12-01 Change to smaller OSHW logo. Moved top copper fiducials.
    [OpenLog.brd, OpenLog.sch]
2016-01-26 Removed via from SD GND pad
    [OpenLog.brd]
2016-01-26 Remove/approve dimensional warnings.
    [OpenLog.brd]
2016-01-27 moved 1 fiducial
    [OpenLog.brd]
2016-01-27 created panel v15
    [OpenLog_Panel_v15.brd]
2016-01-28 moved bottom side fiducial
    [OpenLog.brd, OpenLog_Panel_v15.brd]
2016-01-28 recreated panel v15
    [OpenLog_Panel_v15.brd]
2016-01-29 added bottom side panel fiducials
    [OpenLog_Panel_v15.brd]
2016-03-21 Swapped resistor on grn LED to 330 for better visibility
    [OpenLog.brd, OpenLog.sch]
2016-03-21 Resolved the merge conflict
    I think Bob moved some fiducials (good) and I failed to bring in his
    changes before submitting resistor change. All fixed. Should not affect
    his panel because it's just a part_id change on the schematic.
    [OpenLog.brd]
2016-04-07 Repo cleanup, readme cleanup
    [OpenLog.sch]
2016-10-11 Updating serialport lib to work with recent Arduino releases.
    Fixes issue 204.
2018-02-09 Fix verbose bug issue 208
    [OpenLog.ino, OpenLog_Light.ino]
2018-04-25 Adding 'read firmware version' example
    [OpenLog.sch]
2018-04-30 Driving SPI pins low to avoid power consumption on some SD cards. See issue 215.
    [OpenLog.ino]
2018-11-28 Fix echo and verbose bug in issue #224.
    [OpenLog.ino]
2021-10-11 Adds support for new "Rotate" log mode (issue #244) * Removed extra comments related to MAX_CFG (could be confusing to future developers) * Added two new parameters to config file (Max Filesize and M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
    [OpenLog.ino]

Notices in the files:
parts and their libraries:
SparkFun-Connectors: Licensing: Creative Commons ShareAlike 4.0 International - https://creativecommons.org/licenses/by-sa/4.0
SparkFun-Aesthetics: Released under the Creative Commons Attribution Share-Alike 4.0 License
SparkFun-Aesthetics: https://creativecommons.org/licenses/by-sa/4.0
